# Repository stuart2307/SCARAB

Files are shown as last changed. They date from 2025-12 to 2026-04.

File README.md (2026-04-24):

# The SCARAB
The Save and Cartridge Aid Requiring Adapter Boards

# THE IDEA
As far as preservation goes, emphasis is placed on the software side of things.
Tools exist to dump ROMs, and archive them, but there are few tools to diagnose the hardware.
This is the niche the SCARAB aims to fill.

# WHAT DOES IT DO?
It tests the pins of cartridges to ensure they work correctly.
It validates the checksum of the internal ROM.
It tests the save battery, if applicable, via a Save Data Retention test.

# WHY DID YOU MAKE IT?
I've always loved retro gaming, and I am a collector of old hardware.
As such, when given the opportunity to work with it as part of my Final Year Project, I settled on the SCARAB.
I wanted to have some kind of tool to ensure my cartridges were operational.

Licensed under the GNU General Public License.

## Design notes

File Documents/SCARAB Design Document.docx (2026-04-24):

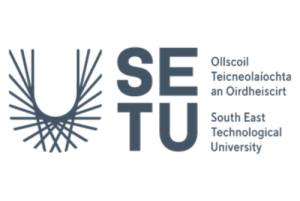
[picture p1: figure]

# SCARAB: Design Document

For submission to SETU

Author: Stuart Rossiter

Student Number: C00284845

Course: BSc (Hons.) Software Development

Supervisor: Joseph Kehoe

# 1. SCARAB Program

## 1.1 Software Architecture

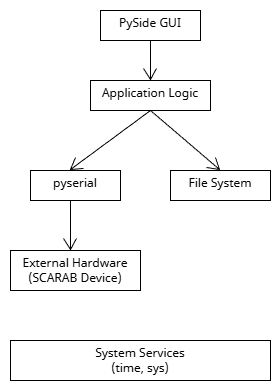
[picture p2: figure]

### 1.1.1 PySide

For GUI development, I am using Python’s own binding of the GUI toolkit Qt, developed by The Qt Company themselves. The binding, known as PySide, is cross-platform, much like Qt. The PySide binding is open source under the GPLv3 and Qt commercial license (pyside, 2021).

### 1.1.2 Python

The application logic will be handled using Python. Python, created by Guido van Rossum in 1991, is a general-purpose language with a simple syntax, similar to the English language (W3Schools, n.d.). Given its simplicity, it allows for rapid development, aided by its abundance of external libraries.

### 1.1.3 pySerial

The pySerial library encapsulates serial port access, providing cross-platform backends for Python (pyserial, 2022). This will be used to interface with the SCARAB Device.

### 1.1.4 File System

The SCARAB program will need to store backed up save files. As such, interaction with the PC’s file system is necessary.

### 1.1.5 External Hardware (SCARAB Device)

pySerial is being used to communicate with external hardware. In this case, it is communicating with the SCARAB Device itself. Specifically, it is communicating with the Arduino which powers the SCARAB.

### 1.1.6 System Services

The SCARAB PC Program will need to make use of some system libraries such as time for any necessary delays while the SCARAB Device connects, and sys for exiting.

# 2. SCARAB Device

## 2.1 Hardware Architecture

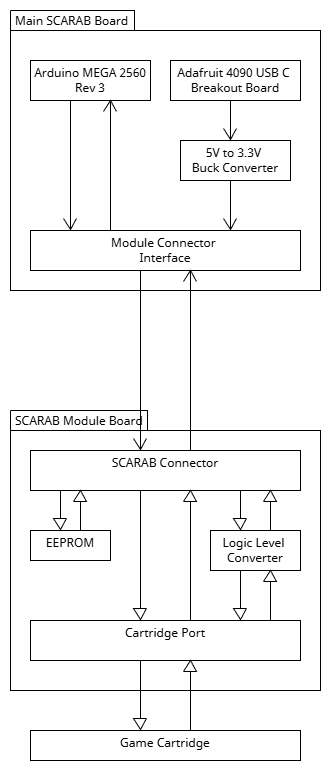
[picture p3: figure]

### 2.1.1 Arduino MEGA 2560 Rev 3

Based on the ATmega2560 microcontroller, the Arduino Mega 2560 Rev3 contains everything needed to support the ATMega2560, including 54 digital I/O pins, 16 analog inputs, 4 hardware serial ports, a 16MHz crystal oscillator, USB connection, and a power jack (Arduino, 2025). The Arduino serves as the intermediary device which translates between what the PC wants, and what the cartridge expects.

### 2.1.2 Adafruit 4090 USB C Breakout Board

The Adafruit USB C board will serve as the main power source for the cartridges and the EEPROM. While a microcontroller has enough power to interface with the cartridge, it doesn’t support the Amps necessary to also power it. Using a USB-C cable, the SCARAB could draw the power necessary from a USB port on the PC. While this will require 2 USB cables to be connected between the SCARAB and the PC, it’s preferable to the alternative of batteries.

### 2.1.3 5V to 3.3V Buck Converter

Not only do some cartridges such as the GBA or N64 use 3.3V logic, but they utilise 3.3V VCC too. The logic level converters would not work for the level of amps required, so a new solution was needed. This is where buck converters are being used. Buck converters convert a DC voltage to a lower DC voltage, such as 5V to 3.3V in this case (Yates, 2024).

### 2.1.4 Module Connector Interface / SCARAB Connector

A series of pins and pin headers, the Module Connector and SCARAB Connector serve as a link between the SCARAB Device and its various cartridge port modules.

### 2.1.5 EEPROM

The Electronically Erasable Programmable Read Only Memory (EEPROM) serves as the identification chip for the individual modules. The SCARAB will need to adjust itself based on the type of cartridge it is reading from, so the EEPROM will store the necessary data to assist in this.

### 2.1.6 Logic Level Converter

As mentioned above, some cartridges use 3.3V logic, where the Arduino MEGA 2560 uses 5V logic. These logic level converters will translate between the Arduino and the cartridge in these cases. They will not be present on every module, only the ones that require 3.3V.

### 2.1.7 Cartridge Port

The cartridge ports serve as an interface between the Arduino and the cartridges themselves. They are fit for purpose, and mimic the port contained within the respective consoles that the cartridges are designed for.

### 2.1.8 Game Cartridge

The game cartridges themselves are the main purpose of the SCARAB. They are being tested and checked for any issues, and having their save data backed up.

## 2.2 Circuit Diagrams

### 2.2.1 SCARAB Device

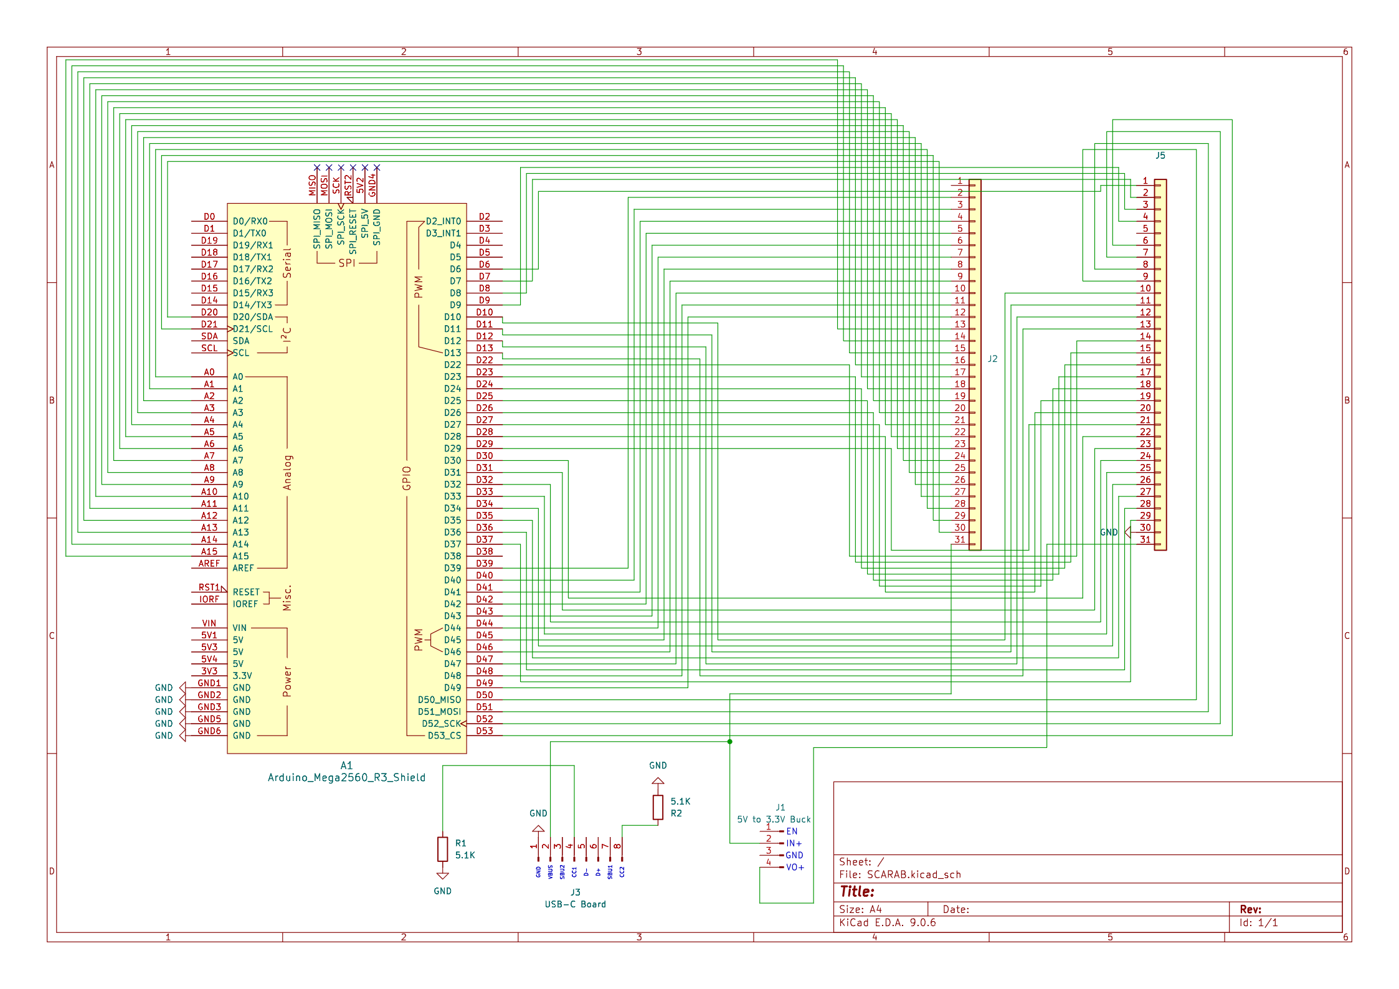
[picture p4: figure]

### 2.2.2 SNES Module

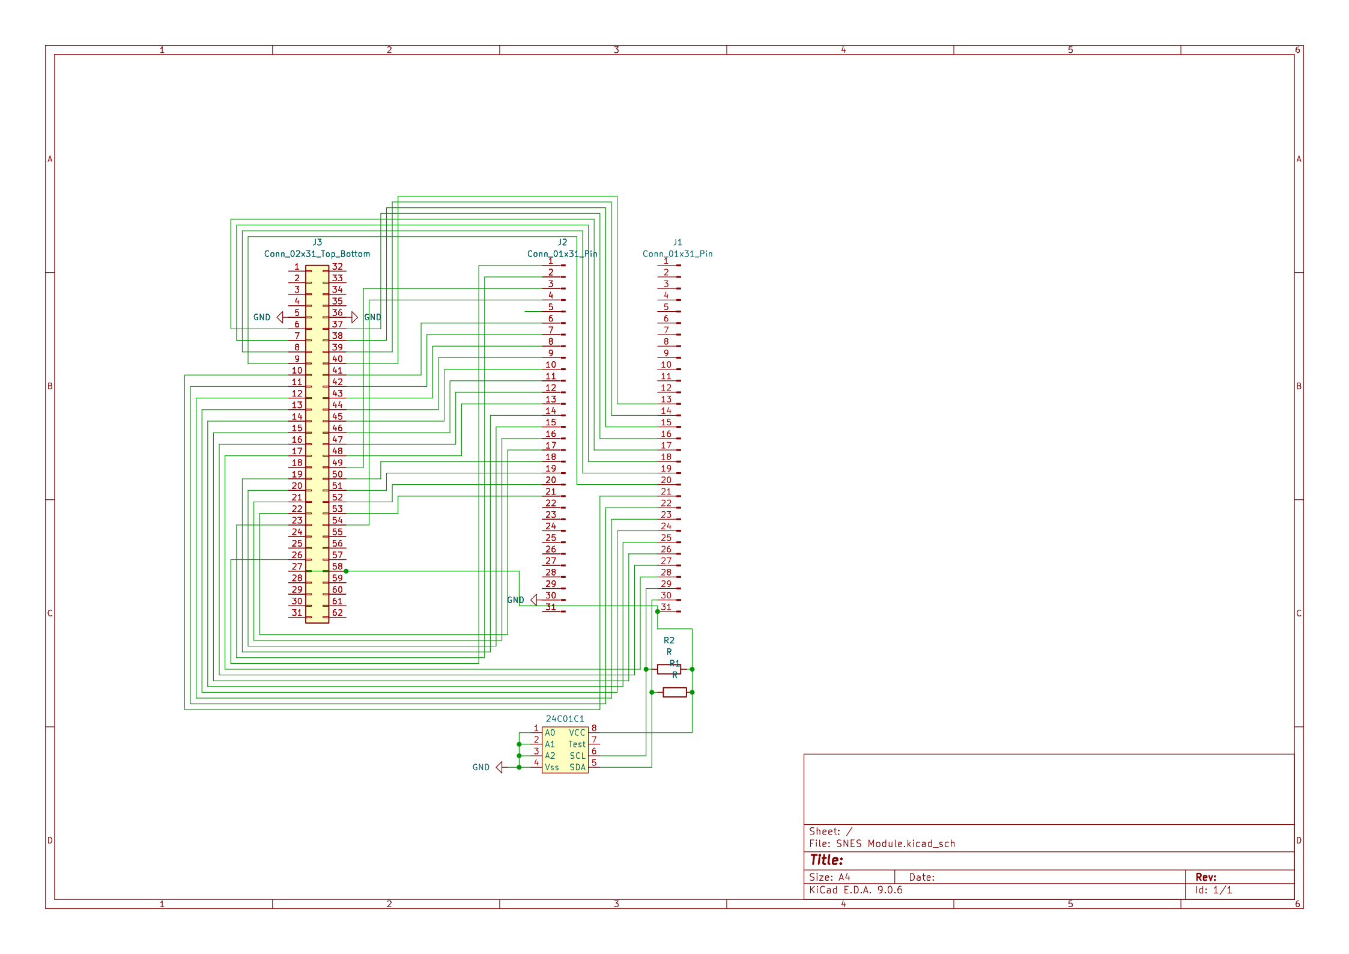
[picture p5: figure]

### 2.2.3 N64 Module

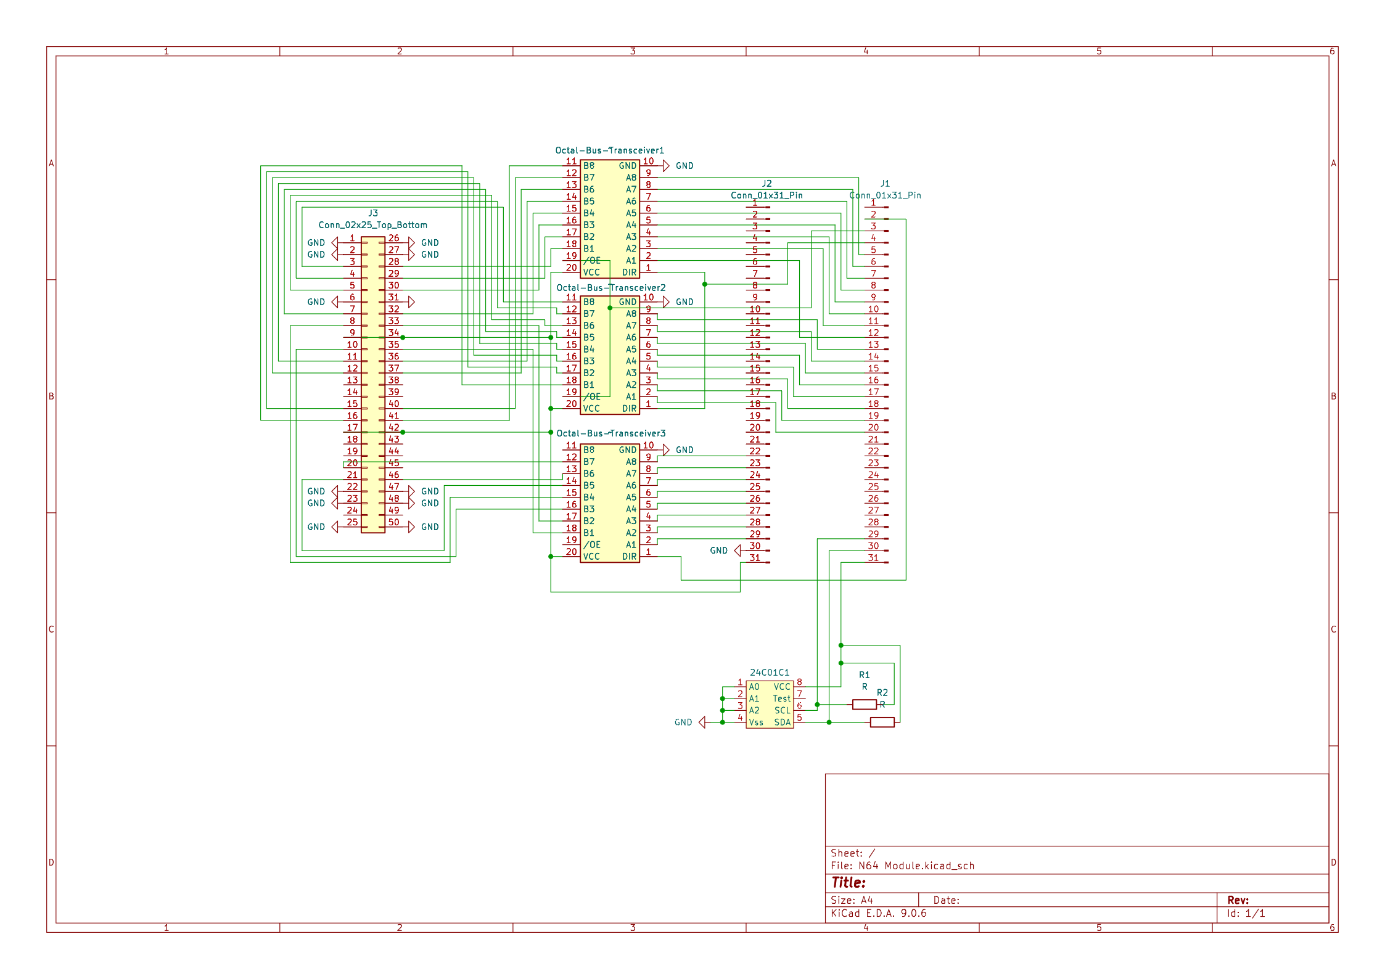
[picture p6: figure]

### 2.2.4 GBA Module

### 2.2.5 NES Module

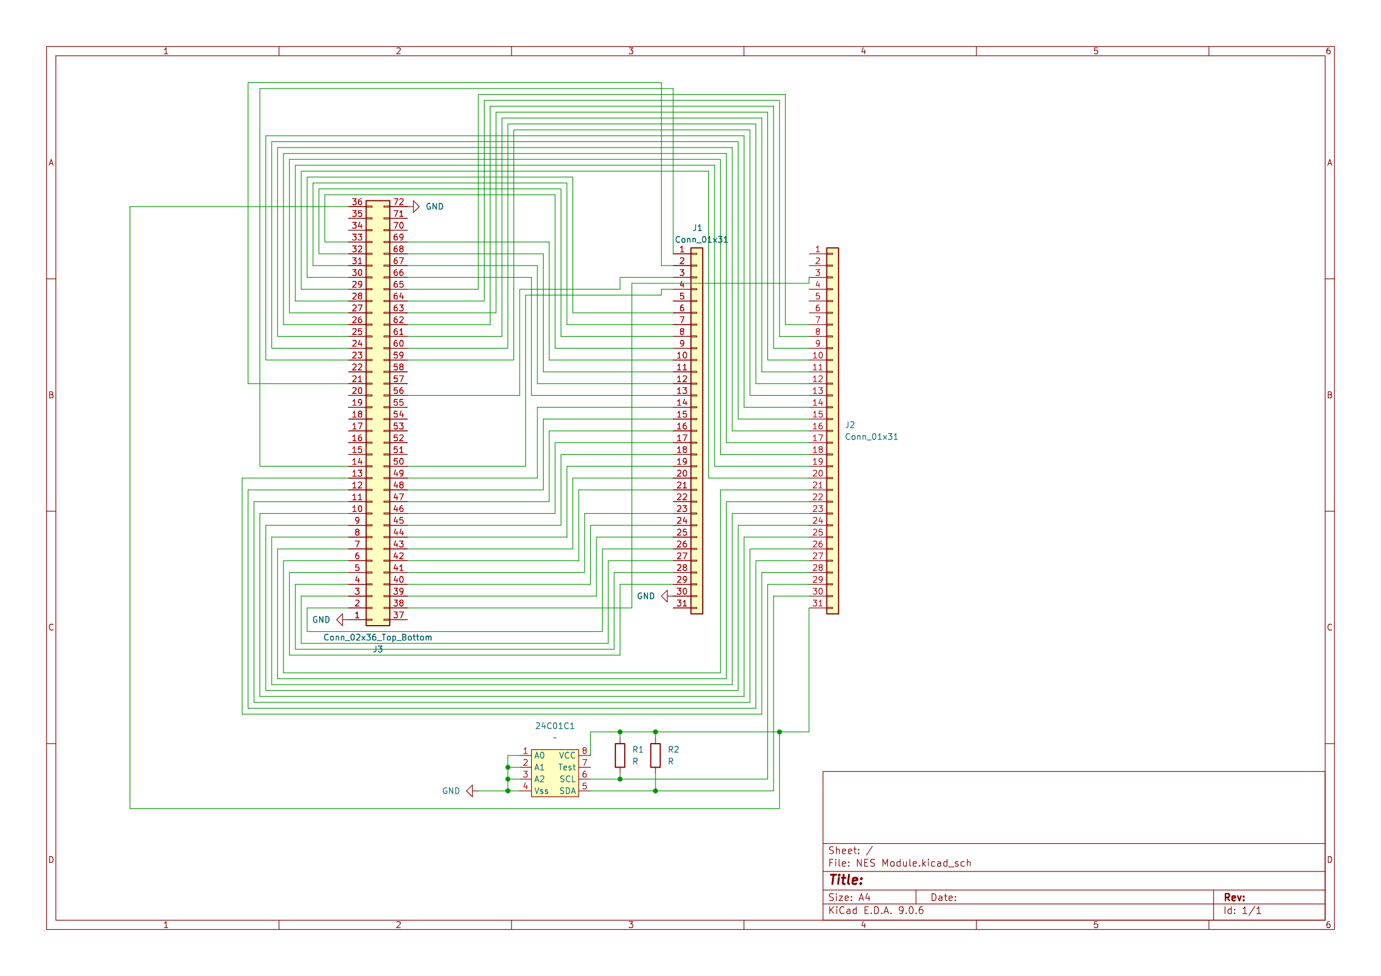
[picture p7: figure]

# 3. Algorithm Pseudocode

## 3.1 SCARAB

### 3.1.1 Identify Module

func identifyModule() {

Initialize EEPROM Connection

value = Read From EEPROM

Close EEPROM Connection

switch (value) {

case “SNES”:

globalFunctionPointers = snesFunctionPointers

case “NES”:

globalFunctionPointers = nesFunctionPointers

case “GBA”:

globalFunctionPointers = gbaFunctionPointers

case “GBC”:

globalFunctionPointers = gbcFunctionPointers

case “N64”:

globalFunctionPointers = n64FunctionPointers

}

}

## 3.2 SNES

### 3.2.1 Read Cartridge

func readSnesCartridge(address) {

Place address on address lines

Set RD line to active low

byte = Read from data lines

return byte

}

### 3.2.2 Write Cartridge

func writeSnesCartridge(address, byte) {

Place address on address lines

Place byte on data lines

Set WR line to active low

}

### 3.2.3 Dump Save

func dumpSnesSave(saveSize, romLayout) {

Create buffer[1024] to store data

switch (romLayout) {

case “LoRom”:

startLocation = LoRomSaveLocation

case “HiRom”:

startLocation = HiRomSaveLocation

case “ExHiRom”:

startLocation = ExHiRomSaveLocation

}

for address in range startLocation to startLocation + saveSize {

buffer[(address – startLocation % 1024)] = readSnesCartridge(address)

checksum for buffer XOR new byte of data

if buffer is full {

Send buffer to PC

Send checksum to PC

clear buffer

if PC returns OK then continue

else error

}

}

}

### 3.2.4 Restore Save

func restoreSnesSave(saveSize, romLayout) {

Create buffer[1024] to store data

switch (romLayout) {

case “LoRom”:

startLocation = LoRomSaveLocation

case “HiRom”:

startLocation = HiRomSaveLocation

case “ExHiRom”:

startLocation = ExHiRomSaveLocation

}

for address in range startLocation to startLocation + saveSize {

if buffer is empty { //if (address – startLocation % 1024) == 0

Request data from PC

Request Checksum from PC

Validate Checksum

if OK then ACK

else ERR

}

writeSnesCartridge(address, buffer[(address – startLocation % 1024)])

}

Send OK to PC

}

### 3.2.5 Calculate Checksum

func calcSnesChecksum(romSize) {

checksum = 0

for address in range romSize {

checksum += readSnesCartridge(address)

if checksum overflows 16 bits, checksum &= 0x00FF

}

return checksum

}

## 3.3 NES

### 3.3.1 Read Cartridge

func readNesCartridge(address, romArea) {

if romArea is “PRG” {

Place address on CPU address lines

set CPU RD to active low

byte = read from CPU data lines

}

else romArea is “CHR” {

Place address on PPU address lines

set PPU RD to active low

byte = read from PPU data lines

}

return byte

}

### 3.3.2 Write Cartridge

func writeNesCartridge(address, romArea, byte) {

if romArea is “PRG” {

Place address on CPU address lines

Place byte on CPU data lines

set CPU WR to active low

}

else romArea is “CHR” {

Place address on PPU address lines

Place byte on PPU data lines

set PPU WR to active low

}

}

### 3.3.3 Dump Save

func dumpNesSave(saveSize, mapper, saveSize) {

based on mapper, writeNesCartridge(BankControlAddress, PRG, RamEnableCode)

declare buffer[1024] to store data

for x in range saveSize {

buffer[x % 1024] = readNesCartridge(x + baseSaveAddress, PRG)

if buffer full {

send buffer to PC

calc Checksum on buffer

send Buffer to PC

clear buffer on OK

}

}

}

### 3.3.4 Restore Save

func restoreNesSave(saveSize, mapper, saveSize) {

based on mapper, writeNesCartridge(BankControlAddress, PRG, RamEnableCode)

declare buffer[1024] to store data

for x in range saveSize {

writeNesCartridge(x + baseSaveAddress, PRG, buffer[x%1024]

if buffer empty { //if (x % 1024) == 0

Request data from PC

Request Checksum from PC

Validate Checksum

if OK then ACK

else ERR

}

}

}

### 3.3.5 Calculate Checksum

## 3.4 GBA

### 3.4.1 Read Cartridge

### 3.4.2 Write Cartridge

### 3.4.3 Dump Save

### 3.4.4 Restore Save

### 3.4.5 Calculate Checksum

## 3.5 GB/GBC

### 3.5.1 Switch Bank

func switchBank(bankNumber, romType, memType) {

Determine Write address from romType

if memType is RAM, write to enable RAM mode

If bankNumber > 1F (needs more than 5 bits, never happens with RAM) {

Write to enable ROM banking mode

Write lower 5 bits

Write upper 2 bits

}

else {

Write bank to address

}

}

### 3.5.2 Read Cartridge

func readGbCartridge(address) {

Place address on address lines

Toggle READ to active low

byte = Read from data pins

return byte

}

### 3.5.3 Write Cartridge

func writeGbCartridge(address, bank, byte) {

Place address on address lines

Place byte on data lines

Toggle WRITE to active low

}

### 3.5.4 Dump Save

func dumpGbSave(ramBanks) {

Create buffer to store data

for x in range ramBanks {

//Banks are offset by 1. bank 0 is the first bank, never needs switching

if bank > 1, switchBank(x – 1, romType, RAM), change offset from 0

Write enable RAM

for y in range 8KiB + offset {

buffer.add(readGbCartridge(y)

if buffer full {

Calculate checksum on buffer

Send buffer to PC

Send checksum to PC

}

}

Write disable RAM

}

}

### 3.5.5 Restore Save

func restoreGbSave(saveSize, ramBanks) {

Create buffer[1024] to store data

Request data from PC

Request Checksum from PC

Validate Checksum

if OK then ACK

else ERR

for x in range ramBanks {

//Banks are offset by 1. bank 0 is the first bank, never needs switching

if bank > 1, switchBank(x – 1, romType, RAM), change offset from 0

Write enable RAM

for y in range 8KiB + offset {

writeGbCartridge(

if buffer empty {

Request data from PC into buffer

Request Checksum from PC

Validate Checksum

if OK then ACK

else ERR

}

}

Write disable RAM

}

Send OK to PC

}

### 3.5.6 Calculate Checksum

## 3.6 N64

### 3.6.1 Read Cartridge

func readN64Cartridge(address) {

Place upper half of address on address lines

Latch upper half of address

Place lower half of address on address lines

Latch lower half of address

Set RD line to active low

byte = Read from data lines

return byte

}

### 3.6.2 Write Cartridge

func writeN64Cartridge(address, byte) {

Place upper half of address on address lines

Latch upper half of address

Place lower half of address on address lines

Latch lower half of address

Put data on data lines

Set WR to active low

}

### 3.6.3 Dump Save

### 3.6.4 Restore Save

### 3.6.5 Calculate Checksum

# 4. User Interface

## 4.1 Main Menu

### 4.1.1 SCARAB Found

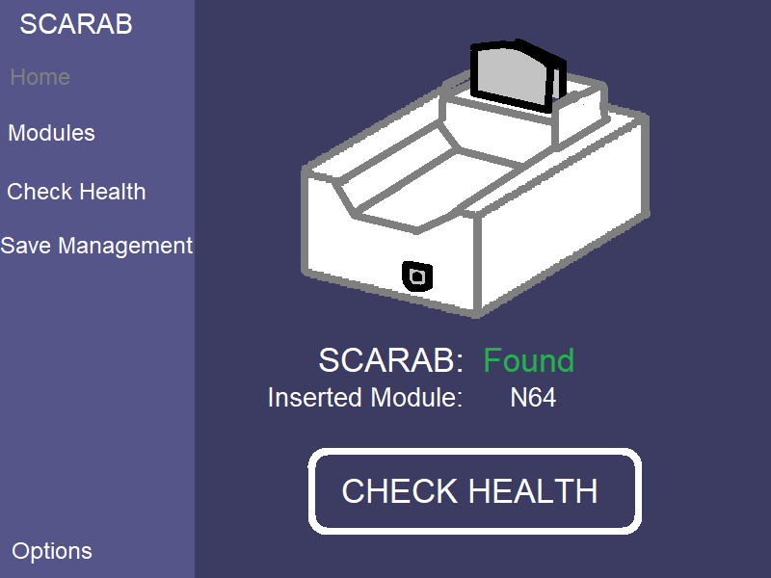
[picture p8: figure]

### 4.1.2 SCARAB Not Found

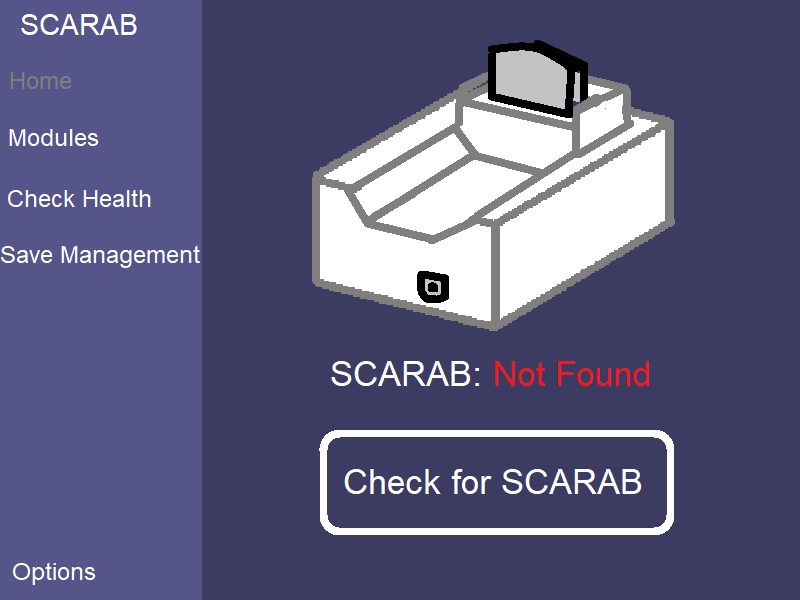
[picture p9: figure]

## 4.2 Modules

### 4.2.1 Module Inserted

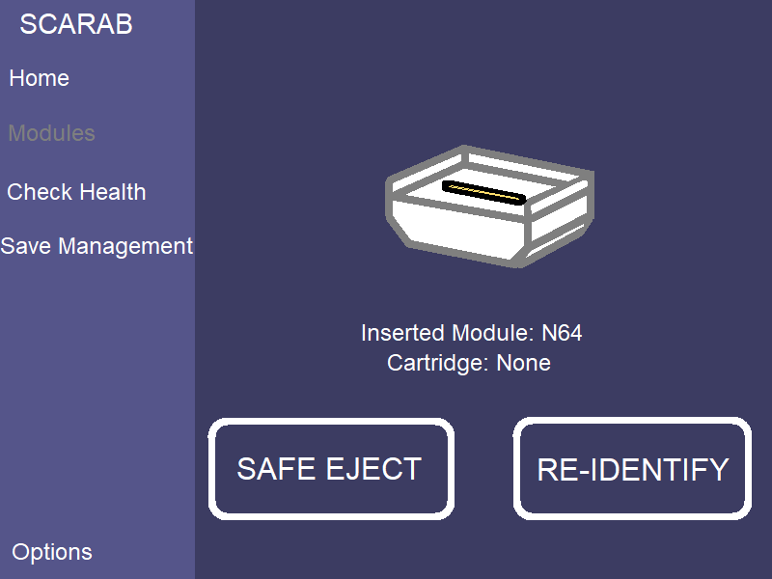
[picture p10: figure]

### 4.2.2 Module Not Inserted

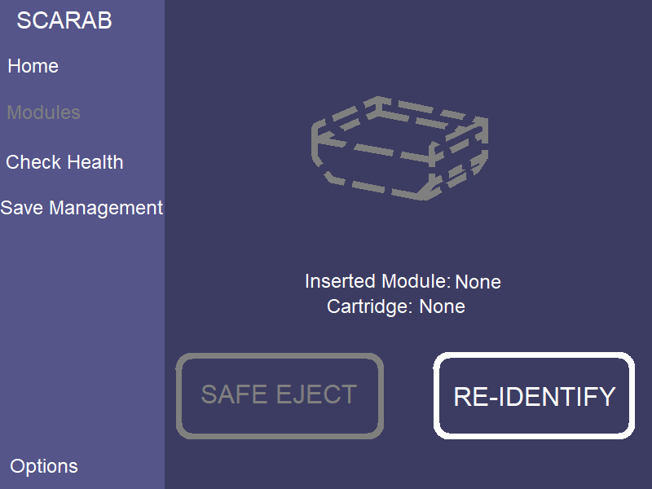
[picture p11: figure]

## 4.3 Check Health

### 4.3.1 Cartridge Inserted

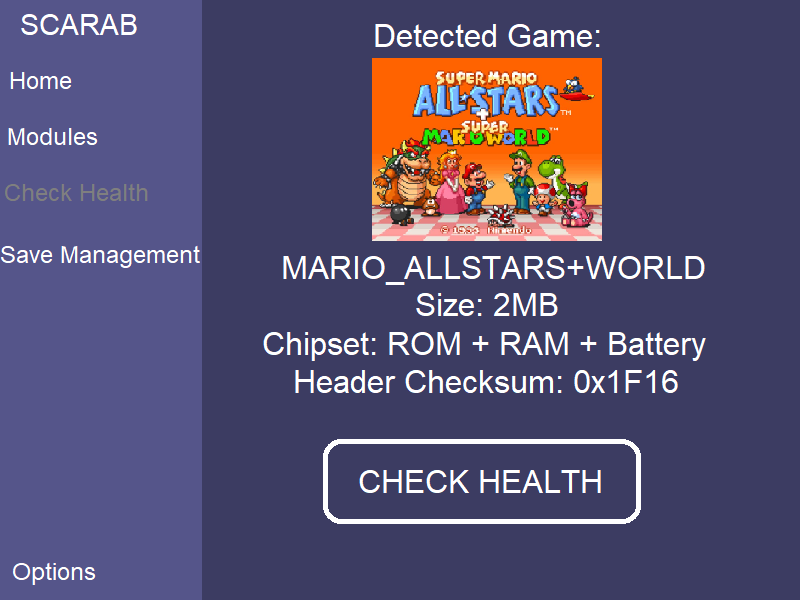
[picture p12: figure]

### 4.3.2 Cartridge Not Inserted

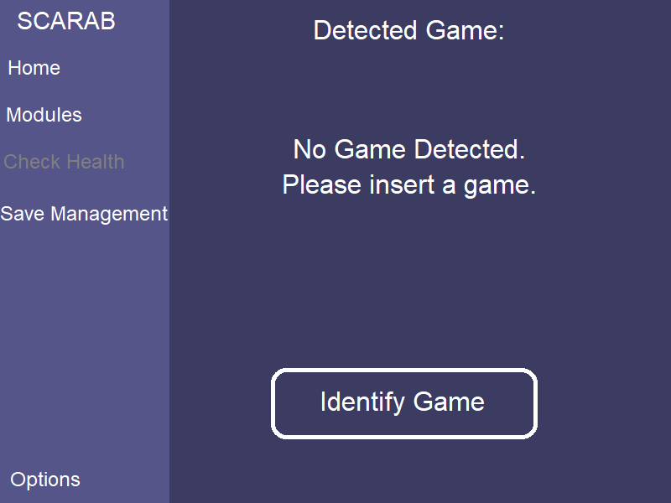
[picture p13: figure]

### 4.3.3 Health Check In Progress

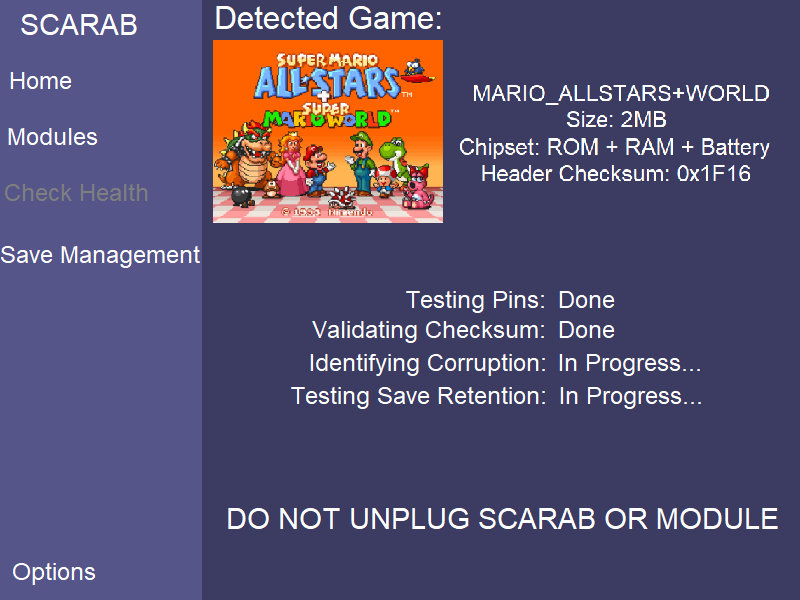
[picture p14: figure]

### 4.3.4 Health Check Done

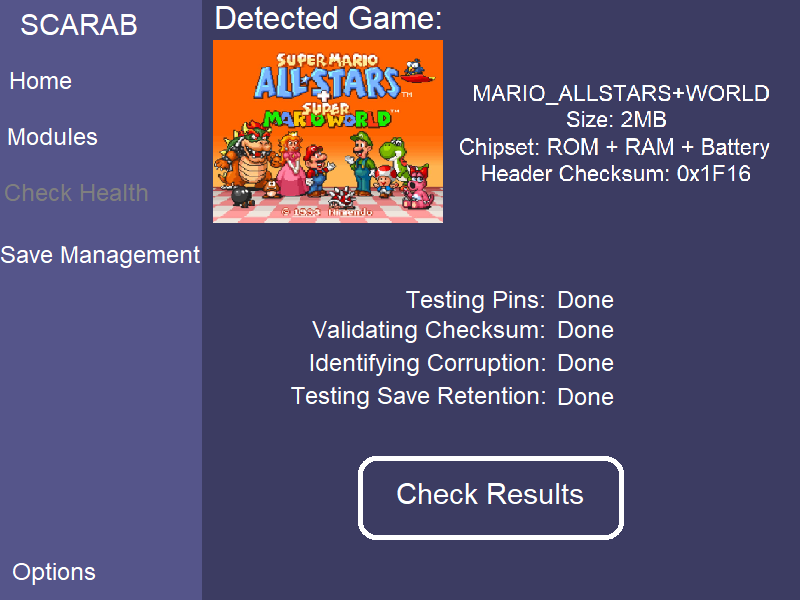
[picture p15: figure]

### 4.3.5 Health Check Results

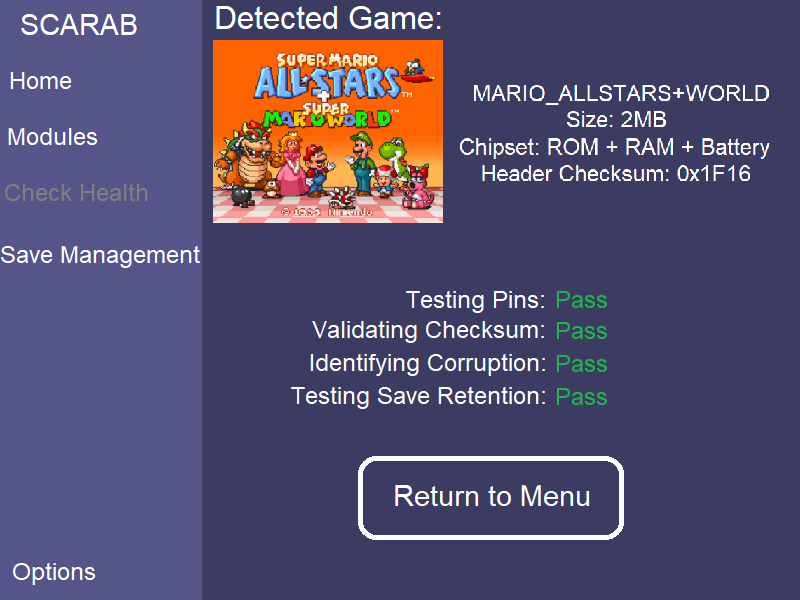
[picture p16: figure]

## 4.4 Save Management

### 4.4.1 Main Menu

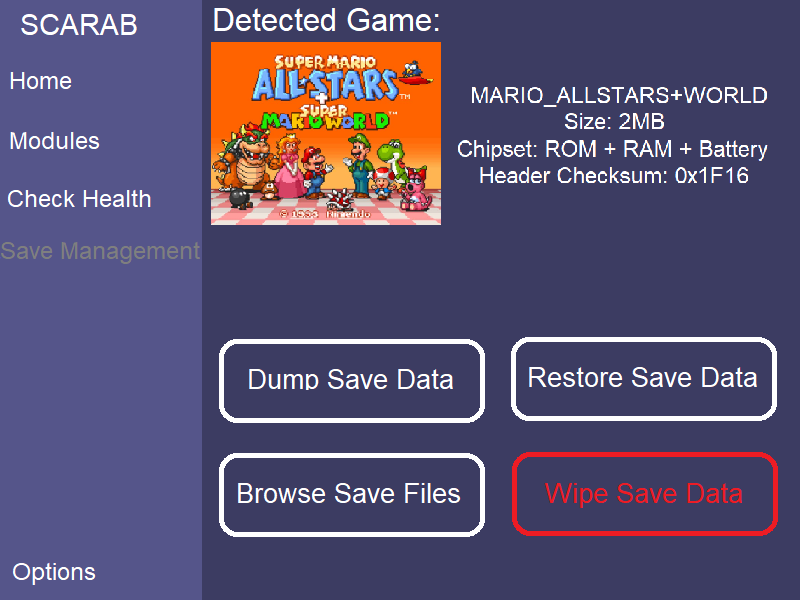
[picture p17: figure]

### 4.4.2 Main Menu No Cart

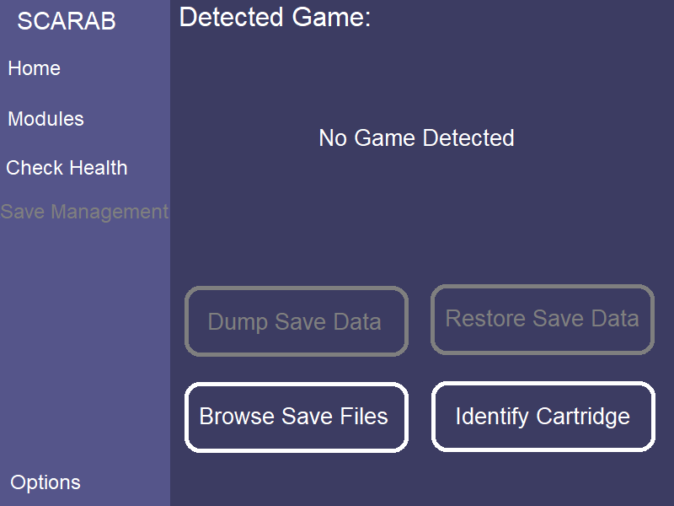
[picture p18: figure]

### 4.4.3 Dumping Save

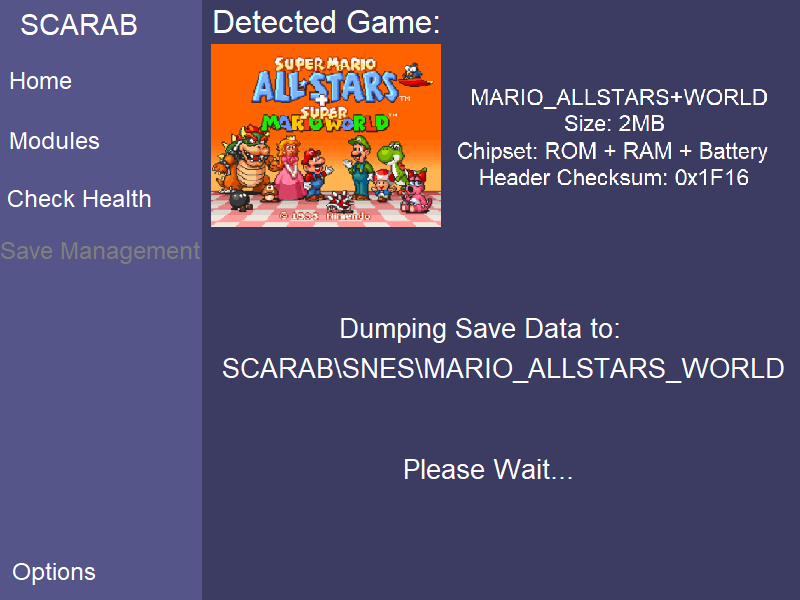
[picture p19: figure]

### 4.4.4 Save Dumped

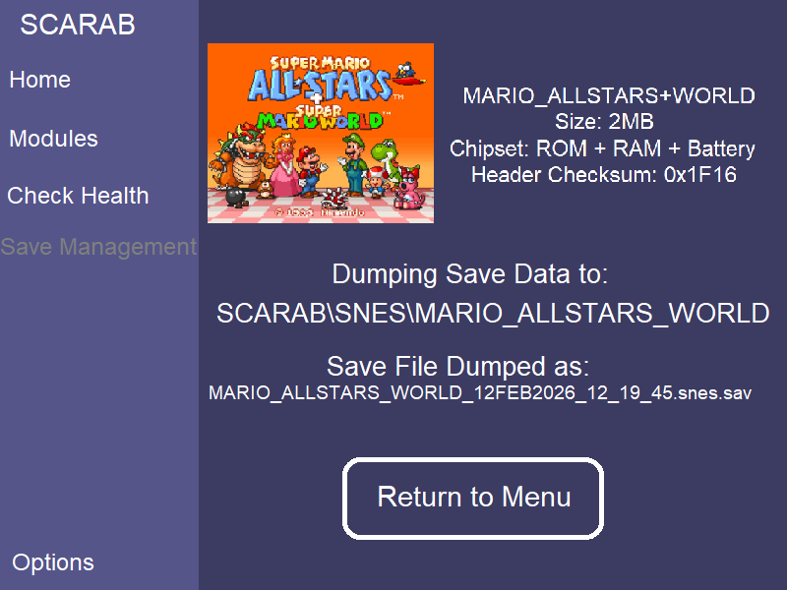
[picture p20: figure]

### 4.4.5 Restore Save

### 4.4.6 Restoring Save

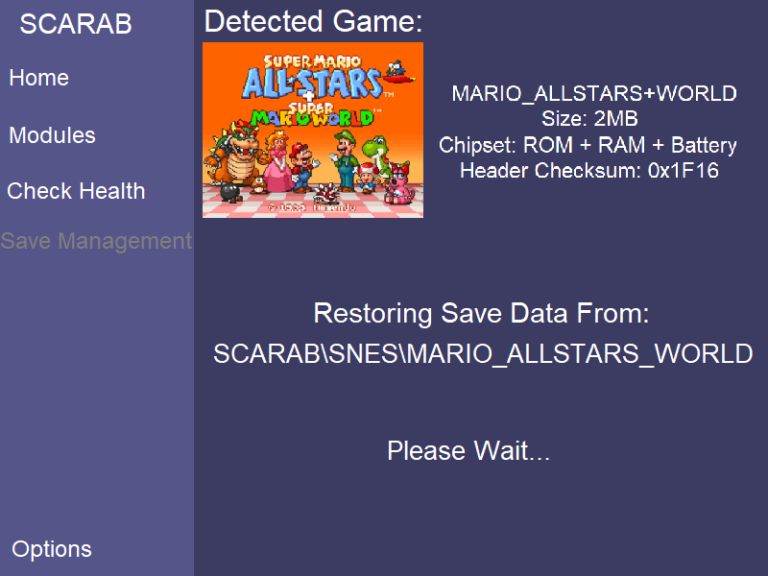
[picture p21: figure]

### 4.4.7 Save Restored

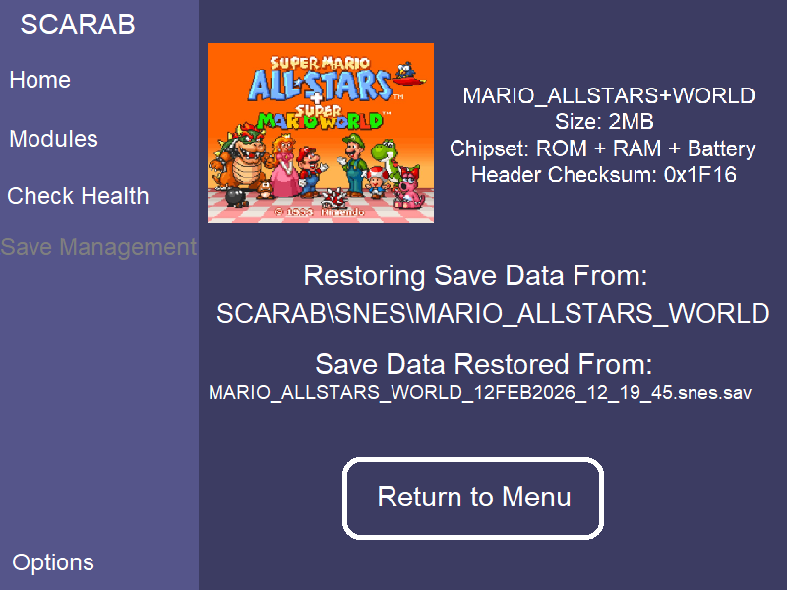
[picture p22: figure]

### 4.4.8 Browse Saves – Select Game

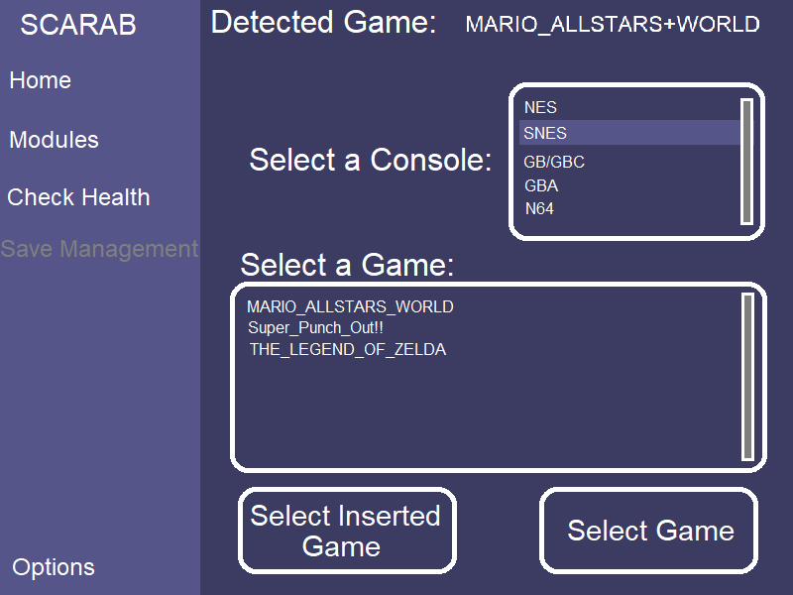
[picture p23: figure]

### 4.4.9 Browse Saves

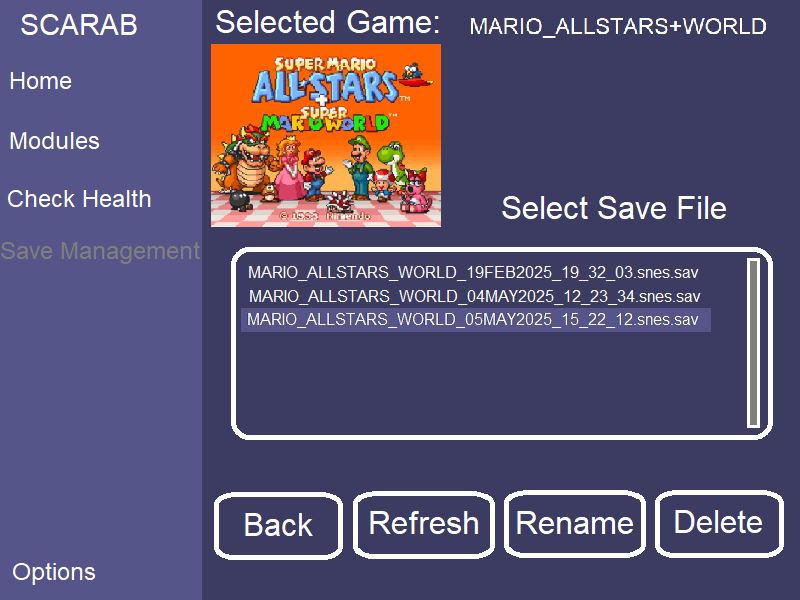
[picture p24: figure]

# 5. Bibliography

Arduino, 2025. Arduino® MEGA 2560 Rev3. [Online]
Available at: https://docs.arduino.cc/resources/datasheets/A000067-datasheet.pdf
[Accessed 10 February 2026].

pyserial, 2022. pySerial. [Online]
Available at: https://github.com/pyserial/pyserial
[Accessed 10 February 2026].

pyside, 2021. GitHub - pyside/pyside-setup: Git super project for PySide. [Online]
Available at: https://github.com/pyside/pyside-setup
[Accessed 10 February 2026].

W3Schools, n.d. Introduction to Python. [Online]
Available at: https://www.w3schools.com/python/python_intro.asp
[Accessed 9 November 2025].

W3Schools, n.d. Introduction to Python. [Online]
Available at: https://www.w3schools.com/python/python_intro.asp
[Accessed 10 February 2026].

Yates, J., 2024. Understanding Buck and Boost Converters and the Capacitors Behind Them. [Online]
Available at: https://blog.knowlescapacitors.com/blog/understanding-buck-and-boost-converters-and-the-capacitors-behind-them
[Accessed 10 February 2026].

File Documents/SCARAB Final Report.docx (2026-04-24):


# SCARAB: Final Report

For submission to SETU

Author: Stuart Rossiter

Student Number: C00284845

Course: BSc (Hons.) Software Development

Supervisor: Joseph Kehoe

# 1. Abstract

This final report covers the development cycle of the Save and Cartridge Aid Requiring Adapter Boards. Shortened to SCARAB, the project’s purpose is to aid in the preservation of retro gaming hardware, through various health checks.

Throughout this report, the challenges encountered during development will be discussed, along with the methods used to overcome them. These issues range from hardware to software, with an emphasis on the latter as this is a Software Development course.

Following the challenges, the requirements that have been achieved and those that have not been achieved will be discussed. Achievements range from the creation of an Arduino powered device to NES and SNES compatibility, while the scrapped features include the likes of Mega Drive compatibility.

In addition, the lessons learned during the creation of the SCARAB will be discussed. These tie in with the challenges, as many of the challenges provided opportunities to grow and learn as a developer.

Testing is documented next, outlining the rigorous testing which was done on the SCARAB Device and SCARAB PC Program. Many of the test cases cover alternative outcomes, such as a cartridge not having been inserted into the SCARAB.

Finally, a reflection concludes the report. This is a personal section, where my skills and growth as a developer are discussed at length. This final section shows how I have become a better developer after undertaking the SCARAB project.

# 2. Introduction

The Save and Cartridge Aid Requiring Adapter Boards (SCARAB) is a retro game cartridge health checker, designed to aid in the preservation of the hardware, over the software. The SCARAB project is split into 2 parts: the SCARAB Device, and the SCARAB PC Program.


(Fig 2.1.1 SCARAB board with inserted Arduino Mega 2560)

The SCARAB Device is responsible for interfacing directly with game cartridges and performing tests to determine their current condition. The results of these tests are returned to the user’s machine over serial, to be displayed in the PC Program.

The SCARAB PC Program provides a user interface for the device, communicating with it via serial. Core features include cartridge identification, a health checking suite, and save management capabilities.

# 3. Challenges

## 3.1 Breadboard Prototyping Issues

One of the main challenges during the development of the SCARAB, was the prototyping of modules. The rows of pins on the Cartridge Connectors were too close together to utilise a breadboard, without connecting both rows of pins to the same side of said breadboard. In addition to this, the pins were slightly too small to have a snug fit within a wire’s female end. This would result in loose connections, causing insufficient power or bad data reads/writes to cartridges. To facilitate the ease of development, only the most fundamental features of the modules would be tested on breadboards, i.e. reading a byte from and writing a byte to a cartridge. With a simple prototype confirming viability of the module, the PCB would be designed and ordered to fully develop the module, and the SCARAB’s interface with it.

## 3.2 Logic Level Translation

While the Arduino is powered at 5v and utilises the same voltage for its logic levels, not all cartridges support this level of power. NES, SNES, and GB/GBC cartridges run natively on 5v, yet the N64 and GBA cartridges run at a lower voltage: 3.3v. Translating all GPIO pins from 5v down to 3.3v would be necessary for these cartridges, which proved to be more difficult than anticipated. Attempts were made to utilise the SN74LVC245AN Octal Bus Transceivers, as it was believed that they would suffice. This was not the case, as the level shifting capabilities of these were not bi-directional. The voltage would be downgraded to 3.3v coming from the Arduino, but it would not be upscaled back to 5v when coming from the cartridge. Alternative approaches were considered, to ensure safe voltage translation and communication with low voltage cartridges.

## 3.3 NES Mapper Handling

NES cartridges use a wide variety of mapper configurations. These mappers are specialized hardware chips within the cartridges that extend the console’s capabilities. For example, they can swap in different banks of ROM/RAM data, allowing games larger than 40KB to be run on the NES. These mappers all behave differently, and as such, performing operations on the cartridges requires pre-operation mapper handling. The decision was made to stick with 6 main mappers, for the time being: NROM, UNROM, CNROM, AOROM, MMC1, and MMC3. Of the 695 licensed releases in North America, 668 are covered by these mappers (tepples, 2020), providing broad compatibility while keeping the complexity to a minimum.

## 3.4 GUI Threading with the SCARAB

When interfacing with the SCARAB device, I encountered the issue of the PC Program’s main GUI Thread becoming blocked, while the SCARAB performed its tests on the cartridge that was inserted. This was a major problem, as the app would become completely unresponsive while the tests were being run. To remedy this, different approaches to concurrency were investigated, including traditional multi-threading and asynchronous execution. In the end, a solution was devised using PySide6’s QTimer.singleShot method. This method utilises a delayed callback to a function, without blocking the main thread. To implement, the operations were split into discrete stages, progressing to the next stage via these scheduled executions.

# 4. Achievements

## 4.1 Arduino Powered Device

One of the 2 main components of the SCARAB project is the SCARAB device. A fully functional cartridge interfacing device was designed and implemented, powered by an Arduino Mega 2560. The main PCB also hosts a USB-C module for power supply, a buck converter for converting the 5V supply to 3.3V for certain modules, and pin headers for attaching module boards. The device reads from cartridges based on the inserted board, and relays the necessary information to the SCARAB PC Program.

## 4.2 GUI Based Cross-Platform Program

The other component of the SCARAB project is the SCARAB PC Program: a GUI-based application designed and developed in Python using the PySide 6 framework. The application supports user-provided cartridge imagery, displayed when the specified cartridge is inserted. Key details about the cartridge are also displayed to the user, such as Title, ROM Size, and Checksum. The SCARAB application has also been developed with modularity in mind. It allows for new modules to be added by placing their Python files in a designated Modules directory, which allows for extension without modifying the application.

## 4.3 NES/SNES Support

The SCARAB module boards allow for future expansion, and the support of various cartridge types. Currently, the SCARAB supports 2 cartridge types: the NES, and the SNES. These modules were designed and prototyped on breadboards, before being given custom PCBs to connect to the SCARAB device. The NES has support for 6 mappers, allowing for a high level of compatibility with licensed releases. The SNES supports LoRom and HiRom layouts, covering a vast majority of cartridges, save for those with the SA-1 enhancement chip.

## 4.4 Save Management

As part of the cartridge aiding functionalities of the SCARAB, the ability to dump/restore save data from cartridges was included to, for example, allow the batteries powering internal SRAM to be changed without losing one’s save file. This save management system was developed and integrated into the SCARAB PC Program, providing means to backup and archive save files for cartridge repair or otherwise.

## 4.5 Health Checking

The main purpose of the SCARAB is to allow for users to check the overall health of their retro video game cartridges. This is facilitated by the SCARAB Program’s Check Health Suite. The checking of cartridge health is split into 3 distinct categories; Cartridge Pins, ROM Data, and Save Data.

For Cartridge Pins, the functionality of the cartridge’s edge connector’s pins are verified. The SCARAB tests that all data pins are toggling on and off as intended, which consequently tests the READ and ROMSELECT pins, if applicable.

For ROM Data, the checksum of the ROM is calculated. This varies by system, as some contain a checksum within the ROM header, whereas some need to be validated externally. For example, the SNES header contains 16-bit sum of every byte of ROM data, with the overflow discarded (Nintendo, 1993).

Finally, the Save Data testing consists of the testing of the cartridge’s save retention. Any previously existing save file is dumped from the cartridge, and a predetermined save is written to it. After cutting cartridge power for ~30 seconds, the predetermined save is read back and compared to the original. The match percentage is returned to the user.

## 4.6 Modular Design

The SCARAB device supports a modular design. The cartridge connectors each have their own custom PCB, which they are attached to along with an EEPROM for identification. This modular system allows for users to pick and choose which cartridges they wish for their SCARAB device to support. In addition, this allows for future expansion, for cartridge types currently not supported by the SCARAB.

## 4.7 EEPROM Identification

Each SCARAB module accommodates an EEPROM for cartridge identification. The first page of the EEPROM stores an 8-byte identifier string, specific to each module. The SCARAB Program provides the functionality to set this identifier when performing initial setup for newly assembled modules.

# 5. Scrapped Features

## 5.1 Mega Drive Compatibility

Originally, the SCARAB was to come with a Mega Drive Adapter Board, which would allow for the analysis and archival of SEGA Mega Drive cartridges. This, however, was dropped due to time constraints. The choice was made to drop the SEGA Mega Drive over other cartridge types, as it is less popular than the Nintendo consoles planned for the SCARAB (Zackariasson & Wilson, 2012).

## 5.2 Automatic Save Retention Testing

When testing a cartridge’s save data retention, the SCARAB requests that the user unplug the power cable, to allow for RAM to lose the data written to it. The original plan was for this to be an automatic process.

Using MOSFETs, the SCARAB would control the power lines. Unfortunately, the SCARAB’s main board was very packed, leading the idea to be pushed back to a later stage. This later stage never arrived, leading to the scrapping of the MOSFET controlled power lines. With a redesign, this could potentially be accommodated.

## 5.3 3.3V Compatibility

The SCARAB was ideally to support cartridges of both 5V logic levels, and 3.3V logic levels. This did not end up happening. The 8-bit Logic Level Translators used, the SN74LVC245A Octal Bus Transceivers, were not ideal for the job. It was my understanding that the level shifting was bidirectional, but that is not the case. The use of a truly bidirectional level shifter, in the TXS1080E would serve to allow for such compatibility. By omitting the 3.3V environment from the SCARAB’s compatibility, it immediately renders the Nintendo 64 and Game Boy Advance adapter boards redundant until a redesign is done.

## 5.4 Identify Corruption

Out of the 4 tests originally planned as part of the Check Health Suite provided by the SCARAB, only 3 were completed. Identify Corruption was scrapped. The original plan was to identify any areas of ROM that were incorrect or had become corrupted. This proved to be far more difficult than thought. Without a fully intact version of the ROM on the inserted cartridge, there would be no way to know exactly which bytes were invalid. Alternatives were explored, such as adding a feature for users to supply their own ROM files. This too was abandoned, as I felt it condoned piracy, which is a moral grey area.

# 6. Lessons Learned

Throughout the development of the SCARAB, I have learned many things.

## 6.1 Hardware Prototyping Limitations

Throughout the development of the SCARAB device, it became clear that there were limitations to what could be achieved via breadboard prototyping. Loose wires, cheap breadboards, and multiple connections between components create additional potential points of failure. As a result, I have learned that the ideal approach is to create a prototype of the most basic features on a breadboard, and to develop fully on a designed PCB.

## 6.2 “Measure Twice, Cut Once”

Upon receiving the PCBs I had designed, it had come to my attention that the spacing between the pins on the GB/GBC/GBA modules were incorrect. The pin distance for these devices is 1.5mm, yet I had mistakenly set them to the pre-existing distance of 1.27mm. With no time to reprint, the module had to be abandoned. This taught me the incredibly important lesson of double and triple checking all my work.

## 6.3 Importance of Concurrency in GUI Programs

When running the tests on the inserted cartridges, I noticed that the SCARAB PC program became unresponsive. Concerned, I investigated and found that it was a quirk of the main GUI thread of PySide6 being occupied by the testing. I learned many ways to remedy this, such as external multithreading, or Qt Event Loop functions within PySide6. My chosen method was the QTimer.singleShot function which allows for delayed callbacks. This was a vital change, as letting a GUI go unresponsive results in a poor user experience.

## 6.4 Benefits of Modular Design

A key feature of the SCARAB is its modular design. It allows for future expansion, allowing users to create and implement their own SCARAB modules with ease. This also helped me in my development, as it led to a fully functional GUI early on, where I could simply drop in new modules to test.

## 6.5 Ethical and Legal Implications of Software

When deliberating the feasibility of the Identify Corruption test, the idea of users supplying their own valid ROMs was brought up. This raised an ethical dilemma about whether this was encouraging piracy. This also crosses over into the legality of such an option.

# 7. Testing

The SCARAB project was tested rigorously, as outlined below. Prior to all these tests, the following preconditions were verified and assumed to be handled correctly throughout all subsequent tests.

## 7.1 Precondition Test Cases

### 7.1.1 Detect SCARAB

Actors: PC, Cartridge Port
Pre-conditions: | The PC is running the SCARAB GUI program.
Main Success Scenario: | 1. The user plugs the SCARAB into the PC using the USB cables. 2. The user clicks “Re-Identify SCARAB” 3. The program begins its attempt of identifying the SCARAB.
Expected Result: | The SCARAB PC Program has identified the SCARAB.
Actual Result: | The SCARAB was indeed correctly identified, and reflected in the GUI Program.
Result: | PASS
Comments:

Alternate Scenario
Scenario | The SCARAB was not plugged in to the PC.
Expected Result: | The SCARAB PC Program displays an error message to the user.
Actual Result: | The user receives an error message as expected, notifying them that the SCARAB was not found.
Result: | PASS

Alternate Scenario
Scenario | An Arduino Mega 2560 is connected, but without the SCARAB code on it.
Expected Result: | The SCARAB PC Program displays an error message to the user.
Actual Result: | The user receives an error message as expected, notifying them that the SCARAB was not found.
Result: | PASS

### 7.1.2 Identify Module

Actors: PC, Cartridge Port
Pre-conditions: | The PC is running the SCARAB GUI program. The SCARAB has been plugged in and identified.
Main Success Scenario: | 1. The user plugs a module into the SCARAB’s module connector. 2. The user clicks “Modules” on the sidebar of the GUI program, moving to the “Modules” menu. 3. The user clicks “Identify Module”. 4. The SCARAB attempts to identify the inserted module.
Expected Result: | The SCARAB has identified the module.
Actual Result: | The SCARAB module was correctly identified, and this was reflected accordingly in the program.
Result: | PASS
Comments:

Alternate Scenario
Scenario | No module has been inserted into the SCARAB.
Expected Result: | The SCARAB PC Program displays an appropriate error message to the user.
Actual Result: | The user received an error message as expected, notifying them that no module has been inserted.
Result: | PASS

Alternate Scenario
Scenario | The inserted module has not had its EEPROM configured.
Expected Result: | The SCARAB PC Program displays an appropriate error message to the user.
Actual Result: | The user received an error message as expected, notifying them that no module has been inserted.
Result: | PASS

### 7.1.3 Identify Cartridge

Actors: PC, Cartridge Port
Pre-conditions: | The SCARAB is plugged into the PC. The inserted module has been identified.
Main Success Scenario: | 1. A cartridge is inserted into the SCARAB’s module. 2. The user clicks “Modules” on the sidebar of the GUI program, moving to the “Modules” menu. 3. The user clicks “Identify Cartridge”. 4. The SCARAB attempts to identify the inserted cartridge.
Expected Result: | The cartridge is successfully identified and reflected in the GUI program.
Actual Result: | The cartridge was successfully identified, with details about it being reflected to the user.
Result: | PASS
Comments:

Alternate Scenario
Scenario | No cartridge is inserted.
Expected Result: | The SCARAB PC Program displays an appropriate error message to the user.
Actual Result: | The user received an error message as expected, notifying them that there is no cartridge present.
Result: | PASS

## 7.2 Detailed Test Cases

### 7.2.1 Dump Save

Actors: User, SCARAB Device
Pre-conditions: | The SCARAB is connected to a PC with both USB cables. The PC is running the SCARAB GUI program. A cartridge port module is inserted into the SCARAB. A cartridge is inserted into the SCARAB’s cartridge port. A 100% save file has been restored to the cartridge in question.
Main Success Scenario: | 1. The user selects the “Save Management” option from the GUI’s sidebar 2. The program takes the user to the “Save Management” screen. 3. The user selects “Dump Save Data” from the main window. 4. The program begins dumping the save data of the inserted cartridge.
Expected Result: | The SCARAB has successfully dumped the save file of the inserted cartridge to a new file on the PC.
Actual Result: | A .sav file was successfully created, and the validity was verified against the pre-restored save file.
Result: | PASS
Comments:

Alternate Scenario
Scenario | The inserted cartridge does not support save data.
Expected Result: | The user is notified that the cartridge does not support save data, and the program does not attempt to dump the save.
Actual Result: | The user received an error message as expected, notifying them that save data is not supported.
Result: | PASS

### 7.2.2 Restore Save

Actors: User, SCARAB Device
Pre-conditions: | The SCARAB is connected to a PC with both USB cables. The PC is running the SCARAB GUI program. A cartridge port module is inserted into the SCARAB. A cartridge is inserted into the SCARAB’s cartridge port.
Main Success Scenario: | 1. The user selects the “Save Management” option from the GUI’s sidebar 2. The program takes the user to the “Save Management” screen. 3. The user selects “Restore Save Data” from the main window. 4. The program prompts the user to select a save file, displaying the dumped saves compatible with the inserted cartridge. 5. The user selects the predetermined “100% completion” save file, and clicks “Restore Save” 6. The SCARAB begins restoring the save file to the cartridge.
Expected Result: | The SCARAB successfully restores the save data to the cartridge.
Actual Result: | The save data was confirmed to have been written, after having been checked in-game.
Result: | PASS
Comments:

Alternate Scenario
Scenario | The inserted cartridge does not support save data.
Expected Result: | The user is notified that the cartridge does not support save data, and the program does not attempt to restore the save.
Actual Result: | The user received an error message as expected, notifying them that save data is not supported.
Result: | PASS

### 7.2.3 Check Health

Actors: User, SCARAB Device
Pre-conditions: | The SCARAB is connected to a PC with both USB cables. The PC is running the SCARAB GUI program. A cartridge port module is inserted into the SCARAB. A cartridge is inserted into the SCARAB’s cartridge port.
Main Success Scenario: | 1. The user selects the “Check Health” option from the GUI’s sidebar. 2. The program takes the user to the “Health Management” screen. 3. The user clicks “Check Health”. 4. The program brings the user to the testing screen, where it warns the user not to remove the cartridge during testing, while providing progress updates. 5. The SCARAB performs the test(s) on the cartridge.
Expected Result: | The tests are run by the SCARAB, and the results are displayed.
Actual Result: | The tests were successfully run by the SCARAB, and the results were displayed within the GUI Program.
Result: | PASS
Comments:

### 7.2.4 Identify Corruption

Actors: User, SCARAB Device
Pre-conditions: | The SCARAB is connected to a PC with both USB cables. The PC is running the SCARAB GUI program. A cartridge port module is inserted into the SCARAB. A cartridge is inserted into the SCARAB’s cartridge port.
Main Success Scenario: | 1. The user selects the “Check Health” option from the GUI’s sidebar. 2. The program takes the user to the “Health Management” screen. 3. The user selects “Custom Scan” 4. The user ticks the box for Identify Corruption. 5. The user clicks “Run Test(s)”. 6. The program brings the user to the testing screen, where it warns the user not to remove the cartridge during testing, while providing progress updates. 7. The SCARAB checks the ROM and save data for any corruption.
Expected Result: | The SCARAB displays the results of the Identify Corruption test to the user.
Actual Result: | The Identify Corruption test never ran, as it always defaults to “Not Selected.”
Result: | FAIL
Comments: | Feature was scrapped due to difficulties and ethical concerns.

### 7.2.5 Verify Checksum

Actors: User, SCARAB Device
Pre-conditions: | The SCARAB is connected to a PC with both USB cables. The PC is running the SCARAB GUI program. A cartridge port module is inserted into the SCARAB. A cartridge is inserted into the SCARAB’s cartridge port.
Main Success Scenario: | 1. The user selects the “Check Health” option from the GUI’s sidebar. 2. The program takes the user to the “Health Management” screen. 3. The user selects “Custom Scan” 4. The user ticks the box for Verify Checksum. 5. The user clicks “Run Test(s)”. 6. The program brings the user to the testing screen, where it warns the user not to remove the cartridge during testing, while providing progress updates. 7. The SCARAB calculates the checksum of the cartridges rom, and checks it against a known valid checksum.
Expected Result: | The result of the Verify Checksum test is returned to the user. Known functioning cartridges should pass.
Actual Result: | The SCARAB Program successfully relayed the test results back to the user through the GUI. The known working cartridge passed.
Result: | PASS
Comments:

### 7.2.6 Test Pins

Actors: User, SCARAB Device
Pre-conditions: | The SCARAB is connected to a PC with both USB cables. The PC is running the SCARAB GUI program. A cartridge port module is inserted into the SCARAB. A cartridge is inserted into the SCARAB’s cartridge port.
Main Success Scenario: | 1. The user selects the “Check Health” option from the GUI’s sidebar. 2. The program takes the user to the “Health Management” screen. 3. The user selects “Custom Scan” 4. The user ticks the box for Test Pins. 5. The user clicks “Run Test(s)”. 6. The program brings the user to the testing screen, where it warns the user not to remove the cartridge during testing, while providing progress updates. 7. The SCARAB reads tests the toggling of data pins using the header or other known ROM data.
Expected Result: | The results of the test are displayed to the user. Known functioning cartridges should pass.
Actual Result: | The results of the test were relayed back to the user through the GUI. A known working cartridge passed.
Result: | PASS
Comments:

### 7.2.7 Test Save Retention

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

Main Success Scenario:

1. The user selects the “Check Health” option from the GUI’s sidebar.
2. The program takes the user to the “Health Management” screen.
3. The user selects “Custom Scan”
4. The user ticks the box for Test Save Retention.
5. The user clicks “Run Test(s)”.
6. The program brings the user to the testing screen, where it warns the user not to remove the cartridge during testing, while providing progress updates.
7. The SCARAB backs up the user’s save and writes a pre-determined save file to the cartridge.
8. The user, as prompted, removes the USB-C Power Cable from the SCARAB.
9. After 30 seconds, the user reinserts the power cable, as prompted.
10. The save file is dumped and compared to the pre-determined one.
11. The backup save file is rewritten to the cartridge.

Expected Result: | The results are a >99% match.
Actual Result: | The save files were a >99% match, confirming an operational save battery.
Result: | PASS
Comments:

Alternate Scenario
Scenario | User does not unplug the USB-C Power Cable.
Expected Result: | The results were skewed, as a near 100% match.
Actual Result: | The results are a 99.99% match
Result: | PASS

Alternate Scenario
Scenario | The user does not plug the USB-C Power cable back in.
Expected Result: | The results are skewed, as a near 0% match
Actual Result: | The results were a 0% match.
Result: | PASS

Alternate Scenario
Scenario | The inserted cartridge does not support save data.
Expected Result: | The user is notified that the cartridge does not support save data, and the test is listed as “Not Selected”.
Actual Result: | The test was listed as “Not Selected”.
Result: | FAIL
Comments: | User is not notified about lack of save data support.

### 7.2.8 Set Pins

Actors: None
Pre-conditions: | The SCARAB is powered. The SCARAB has received a request
Main Success Scenario: | 1. The SCARAB checks the correct pin layout for the inserted port module. 2. The SCARAB sets the appropriate pins to input or output.
Expected Result: | The correct ports are set to input and output.
Actual Result: | The correct ports were set on the SCARAB.
Result: | PASS

### 7.2.9 Read Data

Actors: PC, Cartridge Port
Pre-conditions: | The SCARAB is plugged into the PC. The SCARAB has received a read request from the PC.
Main Success Scenario: | 1. The SCARAB receives the address to read from, and the size of the read. 2. The SCARAB reads the data from the cartridge into a buffer.
Expected Result: | The SCARAB reads data from the given address and returns it to the PC over serial.
Actual Result: | The SCARAB read the data and returned it, which was validated against a known valid ROM.
Result: | PASS

### 7.2.10 Write Data

Actors: PC, Cartridge Port
Pre-conditions: | The SCARAB is plugged into the PC. The SCARAB has received a write request from the PC.
Main Success Scenario: | 1. The SCARAB receives the request data. 2. The SCARAB loads the writable data into a buffer. 3. The SCARAB writes the data to the cartridge, beginning at the specified address.
Expected Result: | The SCARAB successfully writes the necessary data to the cartridge.
Actual Result: | The SCARAB wrote the data to the cartridge, tested by writing to the save data and checking in-game
Result: | PASS

# 8. Reflection

During my development of the SCARAB, I learned a lot about the development cycle of software, and the intricacies of embedded systems. While some decisions I stand by, there are some things that I would change were I to do this project all over again.

First and foremost, I would swap out the Arduino Mega 2560 Rev 3 for the Arduino Mega PRO. The PRO supports being powered at 3.3v, which negates the need for logic level translators altogether. This is seen in the likes of the Open-Source Cart Reader by Sanni (sanni, 2025).

In addition, I would reduce the number of USBs used from 2 to 1. Currently, the Arduino gets powered by its serial cable, with it also serving as the Serial Communications cable. The cartridges get powered by an external USB-C Breakout board. Ideally, I would develop a communications protocol and utilise the USB-C port for both power and data transfer.

The SCARAB introduced challenges previously unknown to me, such as the ethical concerns of encouraging piracy. This taught me to think about more than just the feasibility of coding a feature, when it came to deliberating whether it should be included.

To conclude, the most meaningful takeaway from the SCARAB project was what it revealed about what I value as a developer. I learned to love coding more than I had ever believed, when working on something I was truly interested in, that being retro gaming and hardware. Through the earlier years of the Software Development course, heavy amounts of web development were involved, which I did not find as interesting as one would hope. The SCARAB, however, has reignited my passion for development, and has outlined for me the type of work I would like to do going forward.

# 9. Glossary

SCARAB – Save and Cartridge Aid Requiring Adapter Boards

SNES – Super Nintendo Entertainment System

NES – Nintendo Entertainment System

ROM – Read Only Memory

EEPROM – Electronically Erasable Programmable Read Only Memory

USB – Universal Serial Bus

# 10. Bibliography

Nintendo, 1993. SNES Development Manual. s.l.:Nintendo of America.

sanni, 2025. OSCR: What to Order. [Online]
Available at: https://github.com/sanni/cartreader/wiki/What-to-order
[Accessed 20 April 2026].

tepples, 2020. Most common mappers. [Online]
Available at: https://forums.nesdev.org/viewtopic.php?t=20019
[Accessed 20 April 2026].

Zackariasson, P. & Wilson, T. L., 2012. The Video Game Industry: Formation, Present State, and Future. 1st ed. New York: Routledge.

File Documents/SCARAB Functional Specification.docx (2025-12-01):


# SCARAB: Functional Specification

For submission to SETU

Author: Stuart Rossiter

Student Number: C00284845

Course: BSc (Hons.) Software Development

Supervisor: Joseph Kehoe

# 1. Introduction

The SCARAB (Save and Cartridge Aid Requiring Adapter Boards) is a diagnostic tool designed to check the overall health of retro game cartridges, and manage their saves through a GUI based PC program. Designed for the purpose of retro game preservation, the SCARAB will use an Arduino MEGA 2560 to interface with the cartridges, through cartridge port modules. These modules will be able to be swapped in and out, allowing for a wide variety of cartridge types, and future expansion.

## 1.1 Target Users

The SCARAB will be designed for retro gaming enthusiasts and preservationists. Retro gaming enthusiasts would want to ensure that their video games remain playable, and would be interested in backing up their save games in case something does go wrong. Preservationists keep all sorts of cartridges in working order, preserving the hardware with the software, so they would make use of the SCARAB’s diagnostic capabilities.

## 1.2 Technologies

To serve as an interface between the cartridge port modules and the PC, a microcontroller will be required, in this case an Arduino. Due to the number of pins required for cartridge ports such as the Game Boy Advance, or the Nintendo 64, an Arduino MEGA 2560 would be ideal, due to the sheer number of digital I/O pins on the board. Alternate boards would be usable, but would require latches or multiplexing. For the GUI based PC program, Python would be sufficient, as it can interface with the Arduino directly over serial, and the Tkinter library provides GUI functionality. Various electronic components will also be required, listed below:

- 2x 8-bit transceivers, for 5v to 3.3v logic conversion.
- USB-C port. The Arduino has a max mA output, so a separate USB will be used to power the cartridges.
- Cartridge ports, to interface with the cartridges.
- Printed PCBs, for the SCARAB and its modules.

# 2. Functional Requirements

The functional requirements for the SCARAB are separated into 2 groups: Core and Non-Core.

## 2.1 Core Requirements

- Users should be able to run diagnostic tests on inserted cartridges.
- Users should be able to dump the save data from their cartridges.
- Save Data should be able to be flashed back to the cartridges.
- Users should be able to view and manage their various save files from the GUI program.
- Cartridge ports should be able to be removed, and swapped out with other cartridge port modules.

## 2.2 Non-Core Requirements

- Users should be able to view and edit their save files with a hex editor within the GUI program.
- Users can insert more than one cartridge module to the SCARAB at the same time.
- Users will be able to use 2 probes contained in the side of the SCARAB to check battery levels directly, with results displayed in the GUI PC program.

# 3. Context Diagram and Use Cases

## 3.1 Context Diagram


## 3.2 Use Case Diagrams

### 3.2.1 PC Program


### 3.2.2 SCARAB Device Use Case Diagram


## 3.3 Brief Use Cases

### 3.3.1 Dump Save

Actors: User, SCARAB Device

Description: This use case begins when the user wishes to dump the save file from the inserted cartridge. The user selects “Save Manager” from the sidebar. From there, the user selects the “Dump Save Data” option. The use case ends when the save data has been dumped from the cartridge.

### 3.3.2 Restore Save

Actors: User, SCARAB Device

Description: This use case begins when the user wishes to restore a dumped save to the inserted cartridge. The user selects “Save Manager” from the sidebar. From there, they select the desired save, and press “Restore Save Data”. The use case ends when the save data has been restored to the cartridge.

### 3.3.3 Check Health

Actors: User, SCARAB Device

Description: This use case begins when the user wishes to check the health of the inserted cartridge. The user selects “Health Check” from the sidebar. The user then selects the tests they wish to run, and clicks “Run Test(s)”. This use case ends when the results of the tests are returned to the user.

### 3.3.4 Identify Corruption

Actors: User, SCARAB Device

Description: This use case begins when the user wishes to identify any corrupted data within a cartridge/memory card. The user selects “Health Check” from the sidebar. The user then selects “Identify Corrupted Blocks”, and clicks “Run Test(s)”. This use case ends when the result of the test is returned to the user.

### 3.3.5 Verify Checksum

Actors: User, SCARAB Device

Description: This use case begins when the user wishes to verify the checksum of a cartridge ROM against a known dump. The user selects “Health Check” from the sidebar. The user then selects “Verify Checksum”, and clicks “Run Test(s)”. This use case ends when the result of the test is returned to the user.

### 3.3.6 Test Pins

Actors: User, SCARAB Device

Description: This use case begins when the user wishes to verify the checksum of a cartridge ROM against a known dump. The user selects “Health Check” from the sidebar. The user then selects “Verify Checksum”, and clicks “Run Test(s)”. This use case ends when the result of the test is returned to the user.

### 3.3.7 Test Save Retention

Actors: User, SCARAB Device

Description: This use case begins when the user wishes to test the save retention of the inserted cartridge. The user selects “Health Check” from the sidebar. The user then selects “Test Save Retention”, and clicks “Run Test(s)”. This use case ends when the result of the test is returned to the user.

### 3.3.8 Determine Port

Actors: Cartridge Port

Description: This use case begins when a new cartridge port is inserted. The SCARAB probes the inserted board to determine what cartridge port the board holds. This use case ends when the Arduino has determined the port type.

### 3.3.9 Set Pins

Actors: None

Description: This use case begins when the SCARAB determines a new port type. The SCARAB determines which pins to set as INPUT and OUTPUT. This use case ends when the pins are correctly set.

### 3.3.10 Read Data

Actors: PC, Cartridge Port

Description: This use case begins when the SCARAB gets a read request from the PC. The SCARAB reads data from the cartridge. This use case ends when the requested data has been read.

### 3.3.11 Write Data

Actors: PC, Cartridge Port

Description: This use case begins when the SCARAB gets a write request from the PC. The SCARAB receives the data and places it in a buffer. This use case ends when the requested data has been written to the cartridge.

### 3.3.12 Return Data

Actors: PC

Description: This use case begins when the SCARAB needs to send data to the PC. This use case ends when the SCARAB has sent the data to the PC.

### 3.3.13 Release Port

Actors: PC, Cartridge Port

Description: This use case begins when the PC sends a request to the SCARAB to release the cartridge port. The SCARAB cuts power to the port and disables all pins. This use case ends when the SCARAB sends a confirmation to the PC.

## 3.4 Detailed Use Cases

### 3.4.1 Dump Save

Actors: User, SCARAB Device
Difficulty: | ★★★★☆
Pre-conditions: | The SCARAB is connected to a PC with both USB cables. The PC is running the SCARAB GUI program. A cartridge port module is inserted into the SCARAB. A cartridge is inserted into the SCARAB’s cartridge port.
Main Success Scenario: | 1. The user opens the sidebar and selects the “Save Manager” option. 2. The program takes the user to the “Save Management” screen. 3. The user selects “Dump Save Data” from the main window. 4. The program prompts the user to confirm the dump, displaying the inserted cartridge name and image. 5. The user clicks “Dump Save”, and the SCARAB begins dumping the cartridge’s save file.
Post-conditions: | The SCARAB has successfully dumped the save file of the inserted cartridge to a new file on the PC.
Alternate Step(s): | 4a. The program prompts the user that the current cartridge does not store save data. 5a. The user cancels the dump.

### 3.4.2 Restore Save

Actors: User, SCARAB Device
Difficulty: | ★★★★☆
Pre-conditions: | The SCARAB is connected to a PC with both USB cables. The PC is running the SCARAB GUI program. A cartridge port module is inserted into the SCARAB. A cartridge is inserted into the SCARAB’s cartridge port.
Main Success Scenario: | 1. The user opens the sidebar and selects the “Save Manager” option. 2. The program takes the user to the “Save Management” screen. 3. The user selects “Restore Save Data” from the main window. 4. The program prompts the user to select a save file, displaying the dumped saves compatible with the inserted cartridge. 5. The user selects the save file they wish to restore, and clicks “Restore Save”. 6. The SCARAB begins restoring the save file to the cartridge.
Post-conditions: | The SCARAB has successfully restored the save data to the inserted cartridge.
Alternate Step(s): | 4a. The program prompts the user that the current cartridge does not store save data. 4b. The program prompts the user that there are no supported save files present for the current cartridge. 5a. The user backs out of the save file selection screen.

### 3.4.3 Check Health

Actors: User, SCARAB Device
Difficulty: | ★★★★★
Pre-conditions: | The SCARAB is connected to a PC with both USB cables. The PC is running the SCARAB GUI program. A cartridge port module is inserted into the SCARAB. A cartridge is inserted into the SCARAB’s cartridge port.
Main Success Scenario: | 1. The user opens the sidebar and selects the “Health Manager” option. 2. The program takes the user to the “Health Management” screen. 3. The user selects which tests they wish to perform on the cartridge. 4. The user clicks “Run Test(s)”. 5. The program brings the user to the testing screen, where it warns the user not to remove the cartridge during testing, while providing progress updates. 6. The SCARAB performs the test(s) on the cartridge.
Post-conditions: | The user can see the results of the test(s).
Alternate Step(s): | 3a. The user clicks “Run All Tests”.

### 3.4.4 Identify Corruption

Actors: User, SCARAB Device
Difficulty: | ★★★★☆
Pre-conditions: | The SCARAB is connected to a PC with both USB cables. The PC is running the SCARAB GUI program. A cartridge port module is inserted into the SCARAB. A cartridge is inserted into the SCARAB’s cartridge port.
Main Success Scenario: | 1. The user opens the sidebar and selects the “Health Manager” option. 2. The program takes the user to the “Health Management” screen. 3. The user selects the “Identify Corruption”. 4. The user clicks “Run Test(s)”. 5. The program brings the user to the testing screen, where it warns the user not to remove the cartridge during testing, while providing progress updates. 6. The SCARAB checks the ROM and save data for any corruption.
Post-conditions: | The user can see the results of the test.
Alternate Step(s):

### 3.4.5 Verify Checksum

Actors: User, SCARAB Device
Difficulty: | ★★★☆☆
Pre-conditions: | The SCARAB is connected to a PC with both USB cables. The PC is running the SCARAB GUI program. A cartridge port module is inserted into the SCARAB. A cartridge is inserted into the SCARAB’s cartridge port.
Main Success Scenario: | 1. The user opens the sidebar and selects the “Health Manager” option. 2. The program takes the user to the “Health Management” screen. 3. The user selects the “Verify Checksum”. 4. The user clicks “Run Test(s)”. 5. The program brings the user to the testing screen, where it warns the user not to remove the cartridge during testing, while providing progress updates. 6. The SCARAB calculates the checksum of the cartridges rom, and checks it against a known valid checksum.
Post-conditions: | The user can see the results of the test.
Alternate Step(s):

### 3.4.6 Test Pins

Actors: User, SCARAB Device
Difficulty: | ★★☆☆☆
Pre-conditions: | The SCARAB is connected to a PC with both USB cables. The PC is running the SCARAB GUI program. A cartridge port module is inserted into the SCARAB. A cartridge is inserted into the SCARAB’s cartridge port.
Main Success Scenario: | 1. The user opens the sidebar and selects the “Health Manager” option. 2. The program takes the user to the “Health Management” screen. 3. The user selects the “Test Pins”. 4. The user clicks “Run Test(s)”. 5. The program brings the user to the testing screen, where it warns the user not to remove the cartridge during testing, while providing progress updates. 6. The SCARAB reads areas of ROM multiple times and compares results.
Post-conditions: | The user can see the results of the test.
Alternate Step(s):

### 3.4.7 Test Save Retention

Actors: User, SCARAB Device
Difficulty: | ★★★★☆
Pre-conditions: | The SCARAB is connected to a PC with both USB cables. The PC is running the SCARAB GUI program. A cartridge port module is inserted into the SCARAB. A cartridge is inserted into the SCARAB’s cartridge port.
Main Success Scenario: | 1. The user opens the sidebar and selects the “Health Manager” option. 2. The program takes the user to the “Health Management” screen. 3. The user selects the “Test Save Retention”. 4. The user clicks “Run Test(s)”. 5. The program brings the user to the testing screen, where it warns the user not to remove the cartridge during testing, while providing progress updates. 6. The SCARAB loads the cartridge with a predetermined save, cuts power from the cartridge for 30 seconds, and checks the save on the cartridge against the original.
Post-conditions: | The user can see the results of the test.
Alternate Step(s):

### 3.4.8 Determine Port

Actors: Cartridge Port
Difficulty: | ★★★☆☆
Pre-conditions: | The SCARAB is powered. A cartridge port has just been inserted into the SCARAB device.
Main Success Scenario: | 1. The SCARAB detects that a new cartridge port has been inserted. 2. The SCARAB tests identifier lines on the module, and checks the returned voltages. 3. The voltages are checked against a table, to determine the inserted module type.
Post-conditions: | The SCARAB knows which cartridge port module has been inserted.
Alternate Step(s):

### 3.4.9 Set Pins

Actors: None
Difficulty: | ★☆☆☆☆
Pre-conditions: | The SCARAB is powered. The SCARAB has just determined the type of the inserted port.
Main Success Scenario: | 1. The SCARAB checks the correct pin layout for the inserted port module. 2. The SCARAB sets the appropriate pins to input or output.
Post-conditions: | The SCARAB has set the pins correctly.
Alternate Step(s):

### 3.4.10 Read Data

Actors: PC, Cartridge Port
Difficulty: | ★★☆☆☆
Pre-conditions: | The SCARAB is plugged into the PC. The SCARAB has received a read request from the PC.
Main Success Scenario: | 1. The SCARAB receives the address to read from, and the size of the read. 2. The SCARAB reads the data from the cartridge into a buffer.
Post-conditions: | The SCARAB has read the data at the requested address
Alternate Step(s): | 3. The SCARAB sends the full buffer to the PC, and continues reading.

### 3.4.11 Write Data

Actors: PC, Cartridge Port
Difficulty: | ★★★☆☆
Pre-conditions: | The SCARAB is plugged into the PC. The SCARAB has received a write request from the PC.
Main Success Scenario: | 1. The SCARAB receives the request data. 2. The SCARAB loads the writable data into a buffer. 3. The SCARAB writes the data to the cartridge, beginning at the specified address.
Post-conditions: | The SCARAB has written the data to the cartridge.
Alternate Step(s):

### 3.4.12 Return Data

Actors: PC
Difficulty: | ★☆☆☆☆
Pre-conditions: | The SCARAB is plugged into the PC. The SCARAB needs to send data to the PC program.
Main Success Scenario: | 1. The SCARAB performs a handshake with the PC program. 2. The SCARAB sends the data with packet headers along the serial line to the PC. 3. The SCARAB receives a response confirming transfer.
Post-conditions: | The SCARAB’s data has been transferred to the PC.
Alternate Step(s): | 2a. The PC has not responded to the handshake, so the SCARAB aborts the process.

### 3.4.13 Release Port

Actors: PC, Cartridge Port
Difficulty: | ★★★☆☆
Pre-conditions: | The SCARAB is plugged into the PC. The SCARAB has detected a port is being removed.
Main Success Scenario: | 1. The SCARAB sets all pins to INPUT, essentially disabling them. 2. The SCARAB cuts power to the cartridge port. 3. The SCARAB sends a “Port Removed” response to the PC.
Post-conditions: | The port module connector is no longer receiving power or data.
Alternate Step(s):

# 4. FURPS

## 4.1 Functionality

The SCARAB’s ability to read save data and test cartridges will be its main measure. It should be able to interact with a variety of cartridges, and detect issues with known damaged test cartridges. The SCARAB puts emphasis on modularity, so it must also be able to support a wide range of cartridges and cartridge port modules. The modules need to be able to be swapped seamlessly, with detections in place for removal and insertion of both cartridges and modules. The final iteration should have at least 5 different modules.

## 4.2 Usability

The SCARAB needs to be well documented, with graphical guides within the GUI program for module insertion. Given a SCARAB with no inserted port, a port module, an appropriate cartridge, and an installed SCARAB GUI, users new to the system should be able to begin a health check or save data dump within 60 seconds.

## 4.3 Reliability

The SCARAB will need to be very reliable, as malfunctions could cause damage to the cartridges which it is trying to preserve. Confirmed working cartridges will need to pass all tests 99% of the time. Cartridges with known defects, such as dirty pins or a dead internal battery, will also need to fail at minimum 1 test 95% of the time. Any time a module or cartridge has been removed, the SCARAB PC program should detect it within 1 second.

## 4.4 Performance

The SCARAB will need to be reasonably quick, within reason. The absolute maximum baud rate of the Arduino Mega’s serial line is 1 Megabit per second. Given constant data flow, that’s ~80 seconds for an 8MB N64 ROM dump for checksum calculation. Leaving room for pauses in data flow, the SCARAB should be able to transfer the contents of The Legend of Zelda: Ocarina of Time (32MB) within 6 minutes. Below is a table showing ROM sizes, Minimum Possible Time (MPT), and Acceptable Transfer Time (ATT).

Name | Console | Size | MPT | ATT
Super Mario Bros. 3 | NES | 384KB | 3.1s | 5s
Pokémon Red & Blue | GB | 1MB | 8s | 12s
Super Metroid | SNES | 3MB | 24s | 30s
Pokémon Crystal | GBC | 2MB | 16s | 20s
The Legend of Zelda: Ocarina of Time | N64 | 32MB | 5 Min 20s | 6 Min
Pokémon Ruby / Sapphire | GBA | 16MB | 2 Min 30s | 3 Min

## 4.5 Supportability

The SCARAB is designed with supportability in mind. New firmware should be able to be flashed to the microcontroller (Arduino, in this case) via the connecting cable. Modular cartridge ports should allow for future expansion to the list of compatible cartridges.

# 5. Metrics

There are certain criteria that the SCARAB must meet in order to be deemed a success. They are as follows:

- Users from the target demographic should be able to go from an unplugged SCARAB device and an installer for the PC program on the PCs desktop, to checking the health of an inserted cartridge, within 60 seconds.
- The SCARAB device should be able to detect the inserted module. The insertion or removal of modules should be detected by the SCARAB device and PC program within 0.5 seconds.
- The insertion or removal of cartridges into the modules should be detectable by the SCARAB and PC program within 1 second.
- The SCARAB device should be able to fully dump the save file of a cartridge within 5 seconds. The same 5 second timeframe applies to restoring a save file.
- The SCARAB must identify known issues in at least 95% of cases. Known working cartridges must not have any issues identified at least 99% of the time.
- The SCARAB should be able to identify whether the cartridge supports on-cartridge save data.
- The SCARAB should be able to dump ROMs for checksum validation as outlined in the table above (see 4.4 Performance).

# 6. Project Plan

Each use case of the SCARAB will need to be implemented in order of importance. Below is a timeline of the expected development of the SCARAB.

| October | | | | November | | | | December | | | | January | | | | February | | | | March | | | | April
Functional Specification
Research Document
Design Document
Read Data
Return Data
Check Health
Test Pins
Dump Save
Identify Corruption
Verify Checksum
Write Data
Test Save Retention
Restore Save
Determine Port
Set Pins
Release Port
Testing
Final Report

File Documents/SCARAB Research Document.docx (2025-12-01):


# SCARAB: Research Document

For submission to SETU

Author: Stuart Rossiter

Student Number: C00284845

Course: BSc (Hons.) Software Development

Supervisor: Joseph Kehoe

# 1. Abstract

The SCARAB device and accompanying program are retro game preservation tools designed to check the health of retro game cartridges, and manage their save data. The device, built around a microcontroller, interfaces with the cartridges via cartridge port modules. These modules can be swapped in and out, allowing for a variety of cartridge types, and providing future expansion options. The SCARAB device can auto-detect the inserted modules, and can detect whether a cartridge is inserted. The SCARAB program provides a GUI for the user to interact with. It provides options to dump and restore save data, run a full diagnostic checkup on an inserted cartridge, and run individual tests. It also serves as a save browser, allowing the user to view the save files they have dumped from cartridges.

# 2. Overview

When it comes to researching for the SCARAB, the research needed to be split up into 2 parts. One part focuses on the GUI PC Program. This first part goes into the choice of language for developing the program, and discusses the libraries which have been considered for use with the language. The second part of the research focuses on the SCARAB Device itself. First and foremost, research has been done about microcontrollers, as the “brain” of the device. In addition, the architecture of game cartridges will be discussed, as they will need to be interfaced with by the microcontroller. Finally, various electronic components will be required, and they will be discussed accordingly.

# 3. SCARAB PC Program

## 3.1 Languages

When it comes to choosing a language for the PC program portion of the SCARAB, a lot of thinking needed to be done. The list of requirements for a language are as follows:

- Does not need to be super performance oriented (e.g. Assembly).
- Needs to be able to interface with the SCARAB’s microcontroller.
- Needs to have a good GUI library.
- Needs to be cross platform (Windows, Linux, MacOS).

Several languages are being considered for this.

### 3.1.1 C++

Developed by Bjarne Stroustrup, C++ is a cross-platform language with a high level of control over system resources and memory, due to it being an extension of the C language (W3Schools, 2011). It’s an object-oriented language, facilitating structure and the reusability of code. C++ is known for being fast, as it is used in the likes of operating systems or embedded systems. While not necessary for the SCARAB, this is appreciated.

(Fig 3.1.1.1 – C++ Logo, (Wikimedia Commons, 2017))

With regards to microcontroller interfacing, C++ has a one-size-fits-all library: Boost.Asio. Boost.Asio is a part of the open-source Boost libraries, and it provides tools for asynchronous I/O, concurrency, and networking (Exito Technology, 2023). Boost.Asio provides means for communication over Wi-Fi and Serial connections, 2 prominent methods used by microcontrollers. Bluetooth can also be used, but it requires user implementation as it is not standard with Boost.Asio. The library also abstracts any platform-specific details, allowing for cross-platform support (Exito Technology, 2023).

Qt is a framework designed mainly around the creation of GUI based cross-platform applications. It contains a set of intuitive and modularized C++ library classes, and is loaded with APIs to simplify development (The Qt Company, n.d.). Tools such as Qt Design Studio, a UI design and development environment, also aid in development (The Qt Company, n.d.).

### 3.1.2 C#

Created by Microsoft, C# is a cross-platform general purpose language that runs on the .NET Framework (Microsoft, 2024). Much like C++, C# is in the C family of languages, leading to some familiar syntax such as ending lines with semi-colons, but with added features such as a “foreach” statement for any collection type.


(Fig 3.1.2.1 – C# Logo, (Microsoft, 2022))

C# has Wi-Fi and Serial connection modules built-in, allowing for easy communication with the SCARAB’s microcontroller. With regards to GUI development, C# has an open-source cross-platform framework in Avalonia. Avalonia is a dotnet framework, considered by many to be the spiritual successor of Windows Presentation Foundation, an open-source UI framework for Windows (AvaloniaUI, 2024).

### 3.1.3 Python

Python, created by Guido van Rossum in 1991, is a general-purpose language with a simple syntax, similar to the English language (W3Schools, n.d.). Given its simplicity, it allows for rapid development, aided by its abundance of external libraries. It is a high-level interpreted language, and as such, speed is not a strong point. As mentioned above, however, speed is not paramount for the SCARAB, but it would be appreciated.

(Fig 3.1.3.1 – Python Logo, (Wikimedia Commons, 2008))

For microcontroller communication, Python can cover all bases. The ‘socket’ module allows for communication with Wi-Fi and Bluetooth enabled boards, opening sockets for low-level networking (Python, 2020). For Serial communications, the pySerial library is ideal. The pySerial module encapsulates serial port access, providing cross-platform backends for Python (pyserial, 2022).

For GUI development, Python has its own binding of the GUI toolkit Qt, developed by The Qt Company themselves. The binding, known as PySide, is cross-platform, much like Qt. The PySide binding is open source under the GPLv3 and Qt commercial license (pyside, 2021).

# 4. SCARAB Device

## 4.1 Microcontrollers

To serve as an interface between the cartridge port modules and the SCARAB PC program, some kind of microcontroller was deemed necessary. Microcontrollers are small computers on a single chip. They contain a processor core, RAM, and EEPROM, for storing programs to run. The purpose of a microcontroller is to manage a specific set of tasks within an embedded system, without the need for a complex operating system (Schneider & Smalley, 2024). This is perfect for the SCARAB, as there are only a handful of tasks necessary.

### 4.1.1 Arduino

Among the reasons for choosing Arduino, the main one is the variety of development boards. Several families of boards exist, such as Nano, MKR, UNO, Classic, and Mega, sporting over 30 different boards between them (Arduino, 2022). Given the sheer number of boards, and all their different configurations, there is sure to be a board suitable for the SCARAB. In addition to this, Arduino is inexpensive, has cross-platform support, and the software and hardware are completely open source. Choosing Arduino is not all that needs to be chosen, however. If Arduino is to be chosen, a specific board needs to be chosen. Below are some such boards.

#### 4.1.1.1 Arduino Mega 2560 Rev3


(Fig 4.1.1.1.1 – Arduino Mega 2560, (Arduino, n.d.))

Based on the ATmega2560 microcontroller, the Arduino Mega 2560 Rev3 contains everything needed to support the ATMega2560, including 54 digital I/O pins, 16 analog inputs, 4 hardware serial ports, a 16MHz crystal oscillator, USB connection, and a power jack (Arduino, 2025). The Mega 2560 has enough GPIO pins to handle even the largest of cartridge ports, and the Arduino “port” system allows for the reading from/writing to 8 pins at a time, i.e. 1 byte, all in one single instruction. The Mega 2560 runs on 5V logic. Most cartridges run at 5V logic, with the occasional 3.3V cartridges, so bus transceivers would be needed in these scenarios.

#### 4.1.1.2 Arduino UNO R3


(Fig 4.1.1.2.1 – Arduino UNO R3, (ARDUINO, 2021))

The Arduino UNO R3 is based around the ATmega328P, which is socketed on the board to allow for easy replacement of it in case of failure. The board supports the microcontroller with 14 digital I/O pins, 6 analog inputs, a 16MHz ceramic resonator, a USB connection, and a power jack (Arduino, 2022). To handle the cartridge I/O, the Arduino UNO would need some form of multiplexing and latches, to interface with different lines and to store those inputs/outputs. In addition to that, the UNO runs at 3.3V. The UNO R3 also runs on 5V logic, much like the Mega 2560. Most cartridges run at 5V logic, with the occasional 3.3V cartridges, so bus transceivers would be needed in these scenarios.

### 4.1.2 ESP32

The ESP32 family of chips and boards are developed by Espressif; a fabless silicon vendor based in China, and founded in 2008 (Cording, 2022). Centred around Wi-Fi and Bluetooth connectivity, the ESP32 chip is ideal for Internet of Things (IoT) devices, wearables, and smart home automation. Below are some ESP32 boards.

#### 4.1.2.1 ESP32-P4-Function-EV-Board


(Fig 4.1.2.1.1 – ESP32-P4-Function-EV-Board, (Espressif, 2016))

Clocking in at a maximum of 400MHz, the ESP32-P4 features a dual-core RISC-V processor, supporting the likes of USB 2.0, MIPI-CSI/DSI, H264 Encoder, and various other peripherals (Espressif, 2016). The board supports WiFi 6, Bluetooth 5.0, USB type A and C, Ethernet, and has 55 GPIOs. It also runs at 3.3V, which will require boosting to 5V for some cartridge types. The ESP32-P4-Function-EV-Board seems to be overkill for the project, and it seems to be geared towards audio and video devices.

#### 4.1.2.2 ESP32-C6-DevKitM-1

(Fig 4.1.2.1.1 – ESP32-C6-DevKitM-1, (Espressif, 2023))

The ESP32-C6-MINI-1(U) supports WiFi 6, Bluetooth 5.0, and maxes out at 160MHz (Espressif, 2023). With 22 GPIO pins, the board would need some form of multiplexing and latches, to interface with different lines and to store those inputs/outputs. Much like the ESP32-P4-Function-EV-Board, the ESP32-C6-DevKitM-1 is geared towards audio and video devices, or IoT usage.

## 4.2 Languages

There are a variety of languages supported by the above microcontrollers, all with their pros and cons:

### 4.2.1 Arduino Language


(Fig 4.2.1.1 – Arduino IDE Logo, (Wikimedia Commons, n.d.))

The Arduino programming language is essentially C++ with extra features. It serves as the default programming language for Arduino boards, for use with the Arduino IDE (Arduino, n.d.). As it is based on C++, the Arduino language is fast and lightweight. Support for ESP32 microcontrollers is available, using an Arduino core developed by Espressif, the creators of the ESP32 microcontrollers (Espressif, 2019). The Arduino language is also heavily documented, with code examples available directly from the Arduino IDEs (Arduino, 2025).

### 4.2.2 MicroPython

(Fig 4.2.2.1 – MicroPython Logo, (Wikimedia Commons, 2018))

MicroPython is an implementation of Python 3 that includes a small subset of the Python standard library, optimised to run on microcontrollers and in constrained environments (MicroPython, 2024). Despite all these optimizations, it still has some drawbacks. The main drawback is its compatibility. Among the Arduino boards, only a select few are even compatible (Arduino, 2025). ESP32 boards surpass the specifications for MicroPython, however, and it would be suited to them.

### 4.2.3 TinyGo


(Fig 4.2.3.1 – TinyGo Logo, (TinyGo, 2024))

Bringing concurrency to embedded systems, TinyGo is a port of the Go language to microcontrollers. Unfortunately, it has several flaws as of current. Many microcontrollers are not well-supported, such as the ATmega328P seen in the Arduino UNO, or the ESP32 seen in the ESP32-P4-Function-EV-Board (TinyGo, 2024). It lacks Wi-Fi and Bluetooth support for the ESP32 – one of the microcontroller’s main selling points. In addition to this, the main selling point of Go is its concurrency, but this is irrelevant for microcontrollers possessing only a single core (most Arduino boards). For this reason, there is no reason to use TinyGo on single-core microcontrollers, as it can not be leveraged to its full potential.

## 4.3 Game Cartridges

The SCARAB is intended to interface with many different cartridges through its module boards. The architecture of these cartridges varies, so measures must be taken on a system-by-system basis.

### 4.3.1 Nintendo Entertainment System (NES)

Released in 1983 in Japan as the Famicom, and later in Europe in 1986 (Nintendo, 2016), the NES single-handedly saved the gaming industry. The cartridges, known as Game Paks (a recurring name for Nintendo), have since become iconic.


(Fig. 3.3.1.1 NES Cartridge External View) (Fig. 3.3.1.2 NES Cartridge Internal View)

Earlier games, such as Super Mario Bros, were simple to read and write to, as they contained 2 important chips: one containing 32KB of Program ROM, and the other containing 8KB of Character ROM. These were part of a board revision known as NROM-256 (NESdev Wiki, 2024). The problem with reading later cartridges comes from the introduction of “Mapper Chips”. These chips allowed the NES to bypass its 16-bit address bus limit, by swapping the currently accessible ROM data on the cartridge, allowing for much bigger games (NESdev Wiki, 2023). All but 20 games are covered by the Action 53, MMC1, and MMC3 families, so implementing the 256 registered mappers is not a goal of this project.

Figure 3.3.1.3 shows the pinout of the NES cartridge connector. Most of the important pins for this project come in the format “XXX YZ”, where XXX is either CPU (leading to Program ROM), or PPU (leading to Character ROM), Y is either A for address line or D for data line, and Z is the number for the line. Other important pins include the 5V and GND lines, M2 for the mapper chips, /ROMSEL, CPU R/W, PPU /RD, and CIC +RST (Reset).

(Fig 3.3.1.3 NES cartridge pinout (NESdev Wiki, 2023))

### 4.3.2 Super Nintendo Entertainment System (SNES)

In 1990, Nintendo Japan released the Super Famicom, the 16-bit successor to the Famicom. This was later released in Europe in June 1992 as the SNES (Nintendo, 2016).


(Fig. 3.3.2.1 SNES Cartridges External View) (Fig. 3.3.2.2 SNES Cartridges Internal View)

Many games are straightforward to read from and interface with. The problems arise with some of the “Enhancement Chips” that were seen in later games. Some enhancement chips hold no effect on the reading of cartridges, such as the Super FX chip (seen in Starwing, see MARIO CHIP-1 in Fig 3.3.2.2). The Super Accelerator 1 (SA1) chip, however, is troublesome.

The SA1 is a coprocessor, running at 10.74 MHz: 4 times faster than the speed of the SNES CPU (SnesLab, 2025). As seen in figure 3.3.2.3, it has pins which interface directly with ROM, and has pins for CIC data. This is where the problem lies. Some ROM data is locked behind the SA1 coprocessor, as it contains a Super MMC memory mapper chip. The SA1 begins in a sleeping state, to be woken by the SNES CPU, which will not happen if the CIC lockout chip and correct clock timing are not made available to the SA1. This can be overcome, as seen in how the Sanni Open-Source Cartridge Reader works (sanni, 2024). For the sake of this project, the SA1 bypass will be skipped. It may be implemented down the line.


(Fig. 3.3.2.3 SNES SA1 Chip Pinout (SNESdev Wiki, 2025)) (Fig 3.3.2.4 SNES Connector Pinout (SNESdev Wiki, 2022))

### 4.3.3 Nintendo 64 (N64)

1996 graced Japanese store shelves with the world’s first 64-bit home videogame system: the Nintendo 64. The following year, it was released in Europe, to critical acclaim (Nintendo, 2016).


(Fig. 3.3.3.1 N64 Cartridge External View) (Fig. 3.3.3.2 N64 Cartridge Internal View)

The N64 marks the first cartridge type in my research to use 3.3V power and logic, as opposed to 5V. This is where bus transceivers and a buck converter will be needed see (3.4.1 and 1.4.2).


Figure 3.3.3.3 shows the pinout of the N64 cartridge. AD0-15 are multifunctional. They control the upper 2 bytes of the address input, the lower 2 bytes of the address input, and the 2 bytes of data output. The addresses are latched within the cartridge by the ALE_L and ALE_H pins, and the data is read with the RD pin.

In addition to those, the GND, 3.3V, RESET, and EEPROM_DAT lines will likely be required.

(Fig. 3.3.3.3 N64 Connector Pinout (ConsoleMods Wiki, 2022))

### 4.3.4 Game Boy (GB)

In 1989, Nintendo Japan released the first handheld game system with interchangeable game cartridges. Its name? The Game Boy. It released alongside Tetris, one of its bestselling games. In 1990, the Game Boy came to Europe, and with it, Nintendo of Europe was formed (Nintendo, 2016).


(Fig. 3.3.4.1 Game Boy Cartridge External View) (Fig. 3.3.4.2 Game Boy Cartridge Internal View)

The Game Boy, much like the NES, had mapper chips of its own. Games larger than 32KB needed to use these mapper chips. These chips allowed for “banks” of ROM data to be switched in and out, for access via the address lines. This could be achieved by writing specific values to areas on the cartridge (Retrocomputing Stack Exchange, 2019). Apart from that, addressing the ROM is rather straightforward.


(Fig. 3.3.4.3 GB Connector Pinout (ConsoleMods Wiki, 2022))

Above is the pinout for the Game Boy cartridge. All but AUDIO IN will likely be required.

### 4.3.5 Game Boy Color (GBC)

1998 saw the release of the next step up from the Game Boy, in the Game Boy Color (Nintendo, 2016).


(Fig. 3.3.5.1 GBC Cartridge External View) (Fig. 3.3.5.2 GBC Cartridge Internal View)

From my research, the Game Boy Color cartridges utilise the same addressing and banking systems that the original Game Boy used. This makes things easier, as they are essentially Game Boy games, but bigger.

### 4.3.6 Game Boy Advance (GBA)

The Game Boy Advance released worldwide in 2001, being marked as the fastest selling console ever with over 500k units sold in its first week in Europe. 2 years later, we would see it take on a new clam-shell form; the Game Boy Advance SP (Nintendo, 2016).


(Fig. 3.3.6.1 GBA Cartridge External View) (Fig. 3.3.6.2 GBA Cartridge Internal View)

GBA cartridges are the second cartridges to use 3.3V power and logic. So long as the first read is non-sequential, it’s possible to sequentially read from the ROM by pulsing the “RD” pin repeatedly, to a point (Ziegler, 2025).


(Fig. 3.3. GBA Connector Pinout (ConsoleMods Wiki, 2022))

Reading the ROM is simple enough. The save data depends on the format, however. If it is battery backed SRAM, it’s simple reads and writes. Flash storage requires specific “commands” sent as writes to memory (Korth, 2024). EEPROM is easily the most annoying of the 3. To make a long story short, it handles data serially, i.e. one bit at a time (DenSinH, 2021).

## 4.4 Electronic Components

### 4.4.1 Bus Transceiver

As the GBA and N64 cartridges utilise 3.3V logic, as opposed to the Arduino’s 5V logic, some form of voltage lowering was required. The method of choice was the SN74LVC245AN Octal Bus Transceiver. The bus transceiver allows for bi-directional voltage modulation, converting 5V to 3.3V on one side, and 3.3V to 5V on the other. This feature lets the device function as a translator in mixed 3.3V and 5V environments (Texas Instruments, 2015). These transceivers will allow the Arduino’s 5V logic to interface with the 3.3V logic of the GBA and N64 cartridges.

### 4.4.2 Buck Converter

Not only do the GBA and N64 cartridges use 3.3V logic, but they utilise 3.3V VCC too. The transceivers would not work for the level of amps required, so a new solution was needed. This is where buck converters are introduced. Buck converters convert a DC voltage to a lower DC voltage, such as 5V to 3.3V in this case (Yates, 2024).

### 4.4.3 USB-C Input Module

While a microcontroller has enough power to interface with the cartridge, it doesn’t support the Amps necessary to also power it. Using a USB-C cable, the SCARAB could draw the power necessary from a USB port on the PC. While this will require 2 USB cables to be connected between the SCARAB and the PC, it’s preferable to the alternative of batteries.

### 4.4.4 Cartridge Ports

A microcontroller may have many I/O pins, but cartridges can’t be inserted directly into pins. Cartridge ports are widely available, mostly known by their pin count. For example, the NES port is known as a 72-pin connector. These ports have pins which can be slotted into pin connectors, or directly into PCBs, which will be the case for the cartridge port modules.

### 4.4.5 Resistors

Resistors are passive devices used to control the flow of current in a circuit. Controlling current flow helps to prevent damage to fragile components.

### 4.4.6 EEPROM

EEPROM chips will be used for identification of modules. They can work using serial connections, which the microcontrollers can either support natively or spoof with the correct timing.

# 5. Similar Products

## 5.1 Open Source Cartridge Reader (OSCR)

Created by Sanni, the Open Source Cartridge Reader is a device designed to allow the dumping of cartridge ROMs and Save Data, along with the restoring of saves.

Similarities:

- Both the SCARAB and OSCR will dump and restore save data.
- Both the SCARAB and OSCR use microcontrollers.
- Both the SCARAB and OSCR can calculate the checksum of a cartridge.

Differences:

- The OSCR does not check the checksum against a known valid checksum.
- The OSCR does not interface with a PC. It’s a standalone device with an LCD and SD card. The SCARAB has a PC program it interacts with.
- The SCARAB has automatic voltage detection as standard, with the OSCR it is a modification.
- The OSCR focuses on software preservation, and the SCARAB focuses more on hardware preservation.
- The OSCR solders in multiple cartridge ports to the device itself, where the SCARAB uses a plug-and-play module system.

## 5.2 Retrode2

The Retrode2 is a USB interface for retro cartridges and controllers. It allows users to play their favourite retro games on PC emulators.

Similarities:

- The Retrode2 allows for save dumping and restoring.
- The Retrode2 interfaces with a PC.

Differences:

- The Retrode2 does not check the integrity of the cartridges.
- The Retrode2 serves as an adaptor for SNES and Sega controllers to PC.
- The Retrode2’s main purpose is to bridge the gap between the cartridges and emulators on modern machines, where the SCARAB’s main purpose is hardware preservation.

# 6. Conclusion

Throughout this document, many aspects of the SCARAB have been researched and discussed. First was the GUI Program, where the candidates for language were discussed. Python has been chosen as the language for the program, with the pyserial and PySide libraries. As far as the SCARAB device is concerned, all aspects of it have been researched. The microcontroller chosen is the Arduino Mega 2560. The language of choice for the Arduino is the default C++ based Arduino language. Space conservation is important, so MicroPython won’t do, and TinyGo is focused on concurrency, but the Mega 2560 only has one core. Cartridge pinouts and architecture were also discussed. This was a very important topic, as the Arduino must interface with the cartridges. Knowing which pins are necessary, and where they lie on the connectors, along with any other oddities relating to the cartridges is paramount. Extra components are required, as research had found. These were simple things, such as bus transceivers and buck converters to handle voltage differences, cartridge ports to provide a more familiar interface for the Arduino, USB-C inputs for power, and resistors for many different things.

This document has established several ideas which are important to remember for the development of this project:

- Cartridges are complex. Voltages are different. Pins are different. Pin count is different. Some have extra chips such as mapper chips, EEPROMs, and even CPUs.
- Sometimes, simplicity is ok. For example, C++ may have better speed and memory control than Python, but none of that is needed for this project.

# 7. Appendix

# 8. Glossary

SCARAB – Save and Cartridge Aid Requiring Adapter Boards

UI – User Interface

GUI – Graphical User Interface

RAM – Random Access Memory

EEPROM – Electrically Erasable Programmable Read-Only Memory

I/O – Input/Output

ROM – Read Only Memory

CPU – Central Processing Unit

PPU – Pixel Processing Unit

SRAM – Static Random Access Memory

OSCR – Open Source Cartridge Reader

LCD – Liquid Crystal Display

SD – Secure Digital

USB – Universal Serial Bus

DC – Direct Current

CIC – Checking Integrated Circuit

IoT – Internet of Things

GPIO – General Purpose Input Output

# 9. Bibliography

Anon., 2025. PySide. [Online]
Available at: https://www.pythonguis.com/topics/pyside
[Accessed 12 October 2025].

ARDUINO, 2021. Arduino Uno Rev3. [Online]
Available at: https://store.arduino.cc/products/arduino-uno-rev3
[Accessed 9 November 2025].

Arduino, 2022. Arduino Hardware. [Online]
Available at: https://www.arduino.cc/en/hardware
[Accessed 9 October 2025].

Arduino, 2022. UNO R3 | Arduino Documentation. [Online]
Available at: https://docs.arduino.cc/hardware/uno-rev3
[Accessed 9 November 2025].

Arduino, 2025. Arduino® MEGA 2560 Rev3. [Online]
Available at: https://docs.arduino.cc/resources/datasheets/A000067-datasheet.pdf
[Accessed 10 October 2025].

Arduino, 2025. Built-in Examples. [Online]
Available at: https://docs.arduino.cc/built-in-examples
[Accessed 9 November 2025].

Arduino, 2025. MicroPython. [Online]
Available at: https://docs.arduino.cc/micropython
[Accessed 9 November 2025].

Arduino, n.d. Arduino IDE. [Online]
Available at: https://docs.arduino.cc/software/ide
[Accessed 9 November 2025].

Arduino, n.d. Arduino Mega 2560. [Online]
Available at: https://store-usa.arduino.cc/cdn/shop/files/A000067_00.front_1000x750.jpg?v=1727102662
[Accessed 11 October 2025].

AvaloniaUI, 2024. GitHub - AvaloniaUI/Avalonia: Develop Desktop, Embedded, Mobile and WebAssembly apps with C# and XAML. The most popular .NET UI client technology. [Online]
Available at: https://github.com/avaloniaui/avalonia
[Accessed 9 November 2025].

ConsoleMods Wiki, 2022. Game Boy Connector Pinouts. [Online]
Available at: https://consolemods.org/wiki/Game_Boy:Connector_Pinouts
[Accessed 12 October 2025].

ConsoleMods Wiki, 2022. GBA Connector Pinouts. [Online]
Available at: https://consolemods.org/wiki/GBA:Connector_Pinouts
[Accessed 12 October 2025].

ConsoleMods Wiki, 2022. N64 Connector Pinouts. [Online]
Available at: https://consolemods.org/wiki/N64:Connector_Pinouts
[Accessed 12 October 2025].

Cording, S., 2022. What Is the ESP32? Its Brief History and How to Get Started. [Online]
Available at: https://www.elektormagazine.com/articles/what-is-the-esp32
[Accessed 9 November 2025].

Dahl, Ø. N., 2023. What Is A Resistor And What Does It Do?. [Online]
Available at: https://www.build-electronic-circuits.com/what-is-a-resistor
[Accessed 11 October 2025].

DenSinH, 2021. [GBA] EEPROM Save Type. [Online]
Available at: https://densinh.github.io/DenSinH/emulation/2021/02/01/gba-eeprom.html
[Accessed 12 October 2025].

Espressif, 2016. ESP32-P4-Function-EV-Board v1.5.2 - ESP32-P4 - — esp-dev-kits latest documentation. [Online]
Available at: https://docs.espressif.com/projects/esp-dev-kits/en/latest/esp32p4/esp32-p4-function-ev-board/user_guide.html
[Accessed 9 November 2025].

Espressif, 2019. espressif/arduino-esp32. [Online]
Available at: https://github.com/espressif/arduino-esp32
[Accessed 9 November 2025].

Espressif, 2023. ESP32-C6-DevKitM-1 - ESP32-C6 - — esp-dev-kits latest documentation. [Online]
Available at: https://docs.espressif.com/projects/esp-dev-kits/en/latest/esp32c6/esp32-c6-devkitm-1/user_guide.html
[Accessed 9 November 2025].

Exito Technology, 2023. Boost.Asio: A Powerful Networking Library for C++. [Online]
Available at: https://medium.com/@extio/boost-asio-a-powerful-networking-library-for-c-e86367c2568d
[Accessed 9 November 2025].

GitHub, 2022. pyserial. [Online]
Available at: https://github.com/pyserial/pyserial
[Accessed 12 October 2025].

Korth, M., 2024. GBATEK - GBA/NDS Technical Info. [Online]
Available at: https://problemkaputt.de/gbatek.htm#gbacartbackupflashrom
[Accessed 12 October 2025].

Kumar, A., 2023. Why do We Use the Arduino Programming Language? How is it Helpful?. [Online]
Available at: https://emeritus.org/blog/coding-arduino-programming-language
[Accessed 12 October 2025].

MicroPython, 2024. The MicroPython project. [Online]
Available at: https://github.com/micropython/micropython
[Accessed 9 November 2025].

Microsoft, 2022. File:Logo C sharp.svg. [Online]
Available at: https://commons.wikimedia.org/wiki/File:Logo_C_sharp.svg
[Accessed 09 November 2025].

Microsoft, 2024. Overview - A tour of C#. [Online]
Available at: https://learn.microsoft.com/en-us/dotnet/csharp/tour-of-csharp/overview
[Accessed 9 November 2025].

NESdev Wiki, 2023. Cartridge connector. [Online]
Available at: https://www.nesdev.org/wiki/Cartridge_connector
[Accessed 11 October 2025].

NESdev Wiki, 2023. Mapper. [Online]
Available at: https://www.nesdev.org/wiki/Mapper
[Accessed 11 October 2025].

NESdev Wiki, 2024. NROM. [Online]
Available at: https://www.nesdev.org/wiki/NROM
[Accessed 11 October 2025].

Nintendo, 2016. Nintendo History. [Online]
Available at: https://www.nintendo.com/en-gb/Hardware/Nintendo-History/Nintendo-History-625945.html
[Accessed 11 October 2025].

pyserial, 2022. pySerial. [Online]
Available at: https://github.com/pyserial/pyserial
[Accessed 9 November 2025].

pyside, 2021. GitHub - pyside/pyside-setup: Git super project for PySide. [Online]
Available at: https://github.com/pyside/pyside-setup
[Accessed 9 November 2025].

Python, 2020. socket — Low-level networking interface — Python 3.8.1 documentation. [Online]
Available at: https://docs.python.org/3/library/socket.html
[Accessed 9 November 2025].

Retrocomputing Stack Exchange, 2019. How does the Gameboy's memory bank switching work?. [Online]
Available at: https://retrocomputing.stackexchange.com/questions/11732/how-does-the-gameboys-memory-bank-switching-work
[Accessed 12 October 2025].

sanni, 2024. Reading SNES SFC carts.. [Online]
Available at: https://github.com/sanni/cartreader/wiki/Reading-SNES-SFC-carts
[Accessed 12 October 2025].

Schneider, J. & Smalley, I., 2024. What is a microcontroller?. [Online]
Available at: https://www.ibm.com/think/topics/microcontroller
[Accessed 9 October 2025].

SNESdev Wiki, 2022. Cartridge connector. [Online]
Available at: https://snes.nesdev.org/wiki/Cartridge_connector
[Accessed 12 October 2025].

SNESdev Wiki, 2025. SA-1 Pinout. [Online]
Available at: https://snes.nesdev.org/wiki/SA-1_Pinout
[Accessed 12 October 2025].

SnesLab, 2025. SA-1. [Online]
Available at: https://sneslab.net/wiki/SA-1
[Accessed 12 October 2025].

Texas Instruments, 2015. SN74LVC245A Octal Bus Transceiver With 3-State Outputs. [Online]
Available at: https://www.ti.com/lit/ds/symlink/sn74lvc245a.pdf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
[Accessed 11 October 2025].

The Qt Company, n.d. Qt Features, Framework Essentials, Modules, Tools & Add-Ons. [Online]
Available at: https://www.qt.io/product/features
[Accessed 9 November 2025].

The Qt Company, n.d. Qt Framework - One framework to rule all!. [Online]
Available at: https://www.qt.io/product/framework
[Accessed 9 November 2025].

TinyGo, 2024. Microcontrollers. [Online]
Available at: https://tinygo.org/docs/reference/microcontrollers
[Accessed 9 November 2025].

TinyGo, 2024. TinyGo Home. [Online]
Available at: https://tinygo.org
[Accessed 9 November 2025].

W3Schools, 2011. C++ Introduction. [Online]
Available at: https://www.w3schools.com/cpp/cpp_intro.asp
[Accessed 9 November 2025].

W3Schools, n.d. Introduction to Python. [Online]
Available at: https://www.w3schools.com/python/python_intro.asp
[Accessed 9 November 2025].

Wikimedia Commons, 2008. File:Python-logo-notext.svg - Wikimedia Commons. [Online]
Available at: https://commons.wikimedia.org/wiki/File:Python-logo-notext.svg
[Accessed 9 November 2025].

Wikimedia Commons, 2017. File:ISO C++ Logo.svg - Wikimedia Commons. [Online]
Available at: https://commons.wikimedia.org/wiki/File:ISO_C%2B%2B_Logo.svg
[Accessed 9 November 2025].

Wikimedia Commons, 2018. File:MicroPython new logo.jpg - Wikimedia Commons. [Online]
Available at: https://commons.wikimedia.org/wiki/File:MicroPython_new_logo.jpg
[Accessed 9 November 2025].

Wikimedia Commons, n.d. Arduino IDE logo. [Online]
Available at: https://commons.wikimedia.org/wiki/File:Arduino_IDE_logo.svg
[Accessed 9 November 2025].

Yates, J., 2024. Understanding Buck and Boost Converters and the Capacitors Behind Them. [Online]
Available at: https://blog.knowlescapacitors.com/blog/understanding-buck-and-boost-converters-and-the-capacitors-behind-them
[Accessed 11 October 2024].

Ziegler, R., 2025. Gameboy Advance. [Online]
Available at: https://reinerziegler.de.mirrors.gg8.se/GBA/gba.htm
[Accessed 12 October 2025].

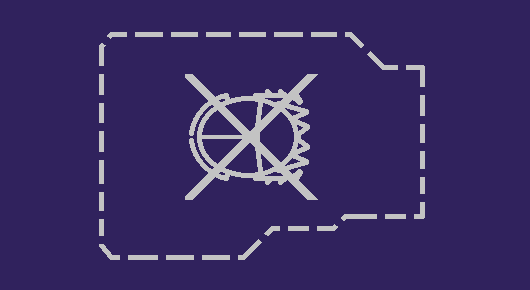
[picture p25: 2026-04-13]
Code/SCARAB Program/Images/SCARAB/not_found.png

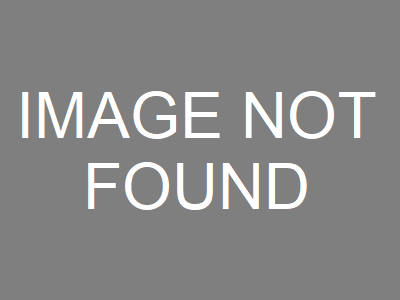
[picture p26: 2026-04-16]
Code/SCARAB Program/Images/cart_image_not_found.png

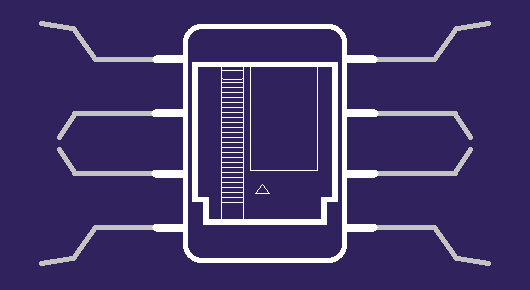
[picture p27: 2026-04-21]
Code/SCARAB Program/Images/Modules/NES.png

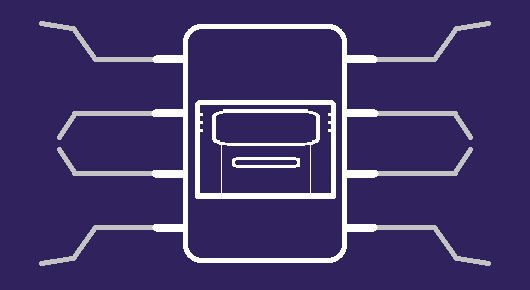
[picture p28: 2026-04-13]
Code/SCARAB Program/Images/Modules/SNES.png

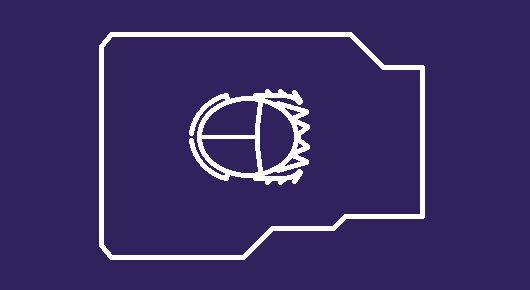
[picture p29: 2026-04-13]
Code/SCARAB Program/Images/SCARAB/found.png

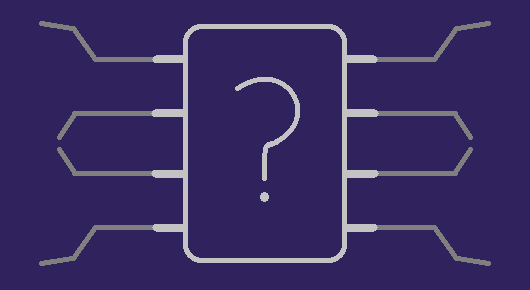
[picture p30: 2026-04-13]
Code/SCARAB Program/Images/Modules/NONE.png

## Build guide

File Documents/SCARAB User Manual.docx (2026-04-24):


# SCARAB: User Manual

For submission to SETU

Author: Stuart Rossiter

Student Number: C00284845

Course: BSc (Hons.) Software Development

Supervisor: Joseph Kehoe

# Requirements

2 Available USB Ports

Arduino IDE

# Installation Instructions

## PC PROGRAM

### Windows:

Download the SCARAB_Setup_Win.exe from GitHub.

Run the installer.

### Linux:

Download the SCARAB_Linux.zip file from GitHub.

Extract the zip file, and run SCARAB

## SCARAB DEVICE

Download the Arduino IDE from the Arduino website.

Download the SCARAB_SKETCH.zip file from GitHub.

Extract it, and open the SCARAB.ino file with the Arduino IDE.

Plug in your Arduino Mega 2560 you will be using for the SCARAB.

Compile and upload the sketch to the Arduino.

# How to Use

Insert the Arduino Mega into the SCARAB Main PCB.

Insert the USB-C Power Cable and USB-A Serial cable into the SCARAB and Arduino respectively.

Insert a module into the SCARAB, with the module facing away from the SCARAB’s Main PCB.

Insert a cartridge into the SCARAB’s module.

Run the SCARAB PC Program.

If the SCARAB GUI Program is running for the first time, it will not auto-identify the SCARAB. This needs to be enabled in “Options”.

Click “Re-Identify SCARAB”. The SCARAB will be identified, along with the Module and Cartridge. If this is a new module, the EEPROM can be written to in “Options”.

Navigate to the “Check Health” menu.

Click “Check Health”.

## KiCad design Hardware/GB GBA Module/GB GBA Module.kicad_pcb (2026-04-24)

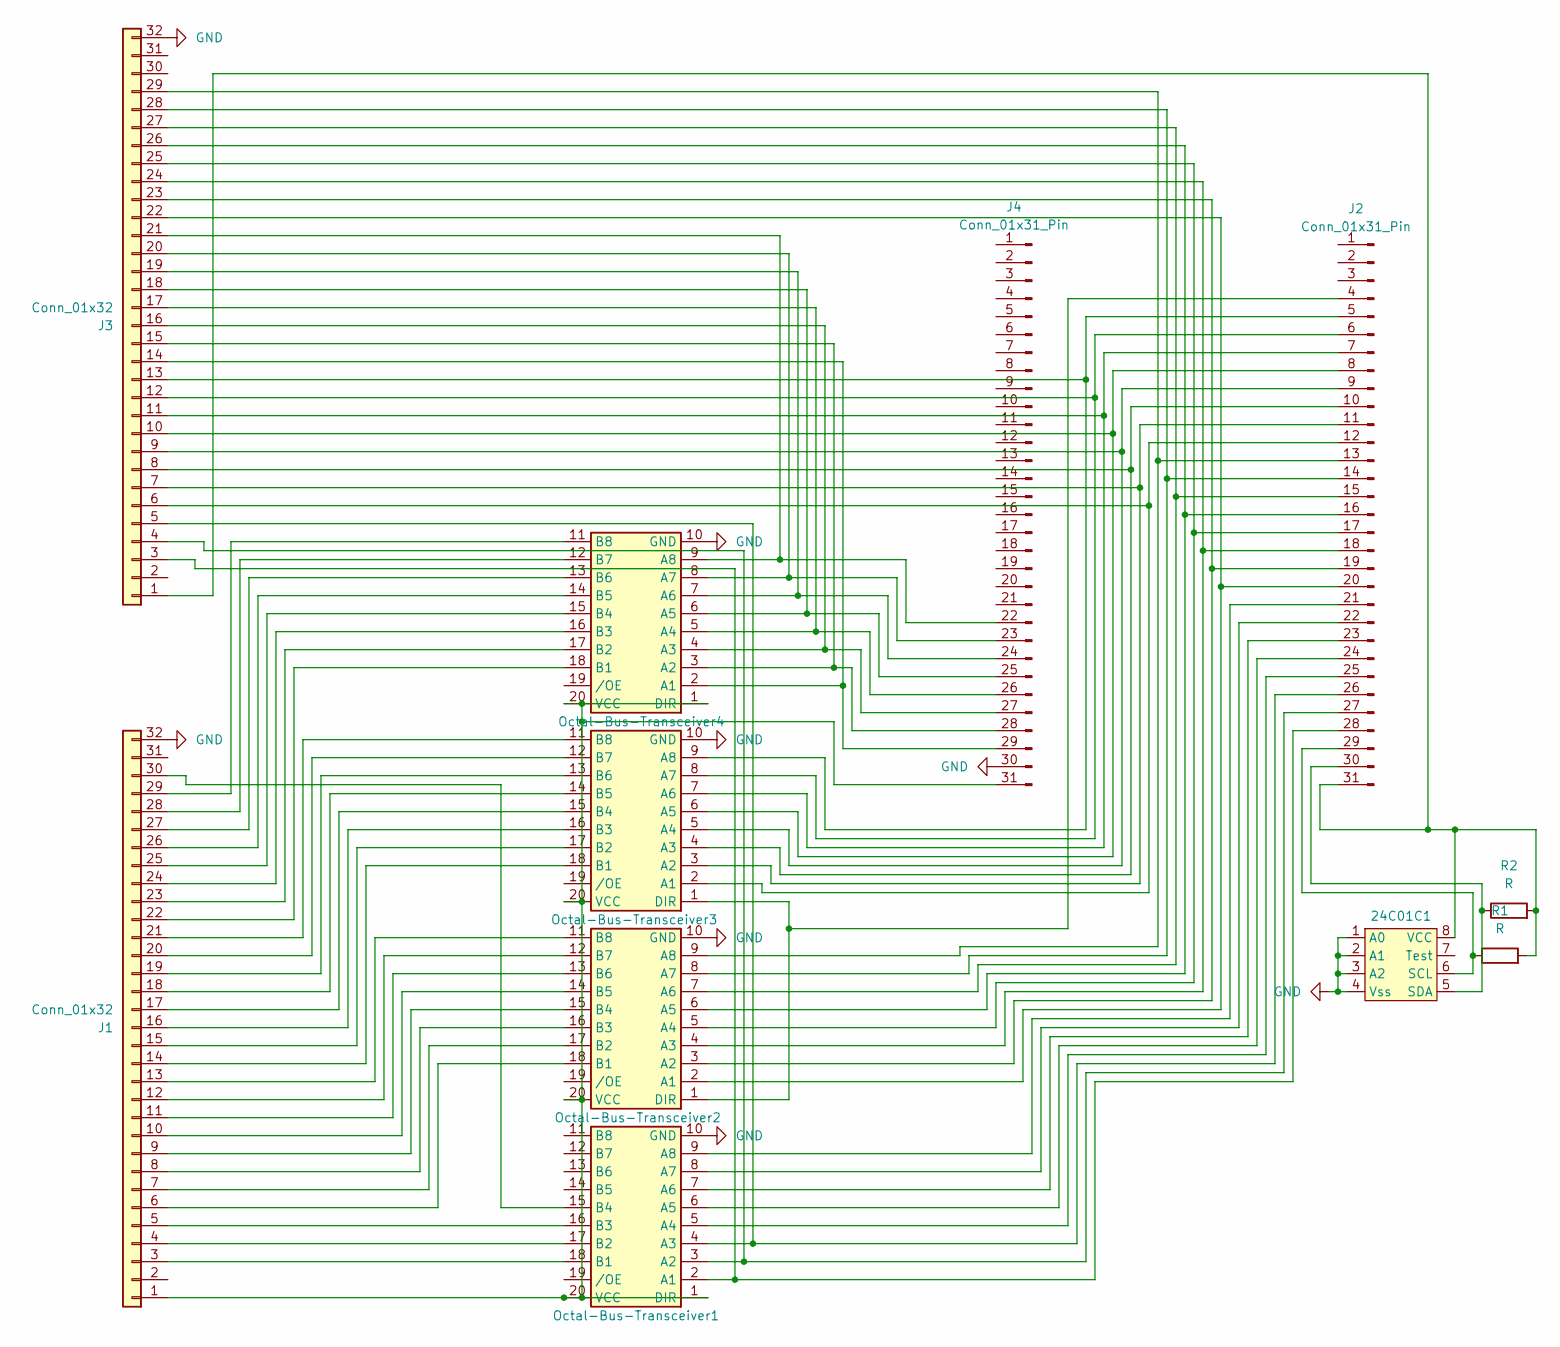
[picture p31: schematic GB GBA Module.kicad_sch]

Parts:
24C01C1: DIP-8_W7.62mm
J1, J3: Conn_01x32; GB_GBA_Cartridge_Port
J2, J4: Conn_01x31_Pin; PinSocket_1x31_P2.54mm_Vertical
Octal-Bus-Transceiver1, Octal-Bus-Transceiver2, Octal-Bus-Transceiver3, Octal-Bus-Transceiver4: CERDIP-20_W7.62mm_SideBrazed
R1, R2: R; R_Axial_DIN0207_L6.3mm_D2.5mm_P10.16mm_Horizontal

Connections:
GND: 24C01C1.1 (A0), 24C01C1.2 (A1), 24C01C1.3 (A2), 24C01C1.4 (Vss), J1.32, J3.32, J4.30, Octal-Bus-Transceiver1.10 (GND), Octal-Bus-Transceiver2.10 (GND), Octal-Bus-Transceiver3.10 (GND), Octal-Bus-Transceiver4.10 (GND)
unnamed: 24C01C1.6 (SCL), J2.29, R1.1
unnamed: 24C01C1.5 (SDA), J2.30, R2.1
unnamed: 24C01C1.8 (VCC), J2.31, J3.1, R1.2, R2.2
unnamed: J1.1, J4.31, Octal-Bus-Transceiver1.1 (DIR), Octal-Bus-Transceiver1.20 (VCC), Octal-Bus-Transceiver2.20 (VCC), Octal-Bus-Transceiver3.20 (VCC), Octal-Bus-Transceiver4.1 (DIR), Octal-Bus-Transceiver4.20 (VCC)
unnamed: J1.3, Octal-Bus-Transceiver1.18 (B1)
unnamed: J1.4, Octal-Bus-Transceiver1.17 (B2)
unnamed: J1.5, Octal-Bus-Transceiver1.16 (B3)
unnamed: J1.6, Octal-Bus-Transceiver2.18 (B1)
unnamed: J1.7, Octal-Bus-Transceiver2.17 (B2)
unnamed: J1.8, Octal-Bus-Transceiver2.16 (B3)
unnamed: J1.9, Octal-Bus-Transceiver2.15 (B4)
unnamed: J1.10, Octal-Bus-Transceiver2.14 (B5)
unnamed: J1.11, Octal-Bus-Transceiver2.13 (B6)
unnamed: J1.12, Octal-Bus-Transceiver2.12 (B7)
unnamed: J1.13, Octal-Bus-Transceiver2.11 (B8)
unnamed: J1.14, Octal-Bus-Transceiver3.18 (B1)
unnamed: J1.15, Octal-Bus-Transceiver3.17 (B2)
unnamed: J1.16, Octal-Bus-Transceiver3.16 (B3)
unnamed: J1.17, Octal-Bus-Transceiver3.15 (B4)
unnamed: J1.18, Octal-Bus-Transceiver3.14 (B5)
unnamed: J1.19, Octal-Bus-Transceiver3.13 (B6)
unnamed: J1.20, Octal-Bus-Transceiver3.12 (B7)
unnamed: J1.21, Octal-Bus-Transceiver3.11 (B8)
unnamed: J1.22, Octal-Bus-Transceiver4.18 (B1)
unnamed: J1.23, Octal-Bus-Transceiver4.17 (B2)
unnamed: J1.24, Octal-Bus-Transceiver4.16 (B3)
unnamed: J1.25, Octal-Bus-Transceiver4.15 (B4)
unnamed: J1.26, Octal-Bus-Transceiver4.14 (B5)
unnamed: J1.27, Octal-Bus-Transceiver4.13 (B6)
unnamed: J1.28, Octal-Bus-Transceiver4.12 (B7)
unnamed: J1.29, Octal-Bus-Transceiver4.11 (B8)
unnamed: J1.30, Octal-Bus-Transceiver1.15 (B4)
unnamed: J2.4, Octal-Bus-Transceiver2.1 (DIR), Octal-Bus-Transceiver3.1 (DIR)
unnamed: J2.5, J3.13, Octal-Bus-Transceiver3.9 (A8)
unnamed: J2.6, J3.12, Octal-Bus-Transceiver3.8 (A7)
unnamed: J2.7, J3.11, Octal-Bus-Transceiver3.7 (A6)
unnamed: J2.8, J3.10, Octal-Bus-Transceiver3.6 (A5)
unnamed: J2.9, J3.9, Octal-Bus-Transceiver3.5 (A4)
unnamed: J2.10, J3.8, Octal-Bus-Transceiver3.4 (A3)
unnamed: J2.11, J3.7, Octal-Bus-Transceiver3.3 (A2)
unnamed: J2.12, J3.6, Octal-Bus-Transceiver3.2 (A1)
unnamed: J2.13, J3.29, Octal-Bus-Transceiver2.9 (A8)
unnamed: J2.14, J3.28, Octal-Bus-Transceiver2.8 (A7)
unnamed: J2.15, J3.27, Octal-Bus-Transceiver2.7 (A6)
unnamed: J2.16, J3.26, Octal-Bus-Transceiver2.6 (A5)
unnamed: J2.17, J3.25, Octal-Bus-Transceiver2.5 (A4)
unnamed: J2.18, J3.24, Octal-Bus-Transceiver2.4 (A3)
unnamed: J2.19, J3.23, Octal-Bus-Transceiver2.3 (A2)
unnamed: J2.20, J3.22, Octal-Bus-Transceiver2.2 (A1)
unnamed: J2.21, Octal-Bus-Transceiver1.9 (A8)
unnamed: J2.22, Octal-Bus-Transceiver1.8 (A7)
unnamed: J2.23, Octal-Bus-Transceiver1.7 (A6)
unnamed: J2.24, Octal-Bus-Transceiver1.6 (A5)
unnamed: J2.25, Octal-Bus-Transceiver1.5 (A4)
unnamed: J2.26, J3.5, Octal-Bus-Transceiver1.4 (A3)
unnamed: J2.27, J3.4, Octal-Bus-Transceiver1.3 (A2)
unnamed: J2.28, J3.3, Octal-Bus-Transceiver1.2 (A1)
unnamed: J3.14, J4.29, Octal-Bus-Transceiver4.2 (A1)
unnamed: J3.15, J4.28, Octal-Bus-Transceiver4.3 (A2)
unnamed: J3.16, J4.27, Octal-Bus-Transceiver4.4 (A3)
unnamed: J3.17, J4.26, Octal-Bus-Transceiver4.5 (A4)
unnamed: J3.18, J4.25, Octal-Bus-Transceiver4.6 (A5)
unnamed: J3.19, J4.24, Octal-Bus-Transceiver4.7 (A6)
unnamed: J3.20, J4.23, Octal-Bus-Transceiver4.8 (A7)
unnamed: J3.21, J4.22, Octal-Bus-Transceiver4.9 (A8)

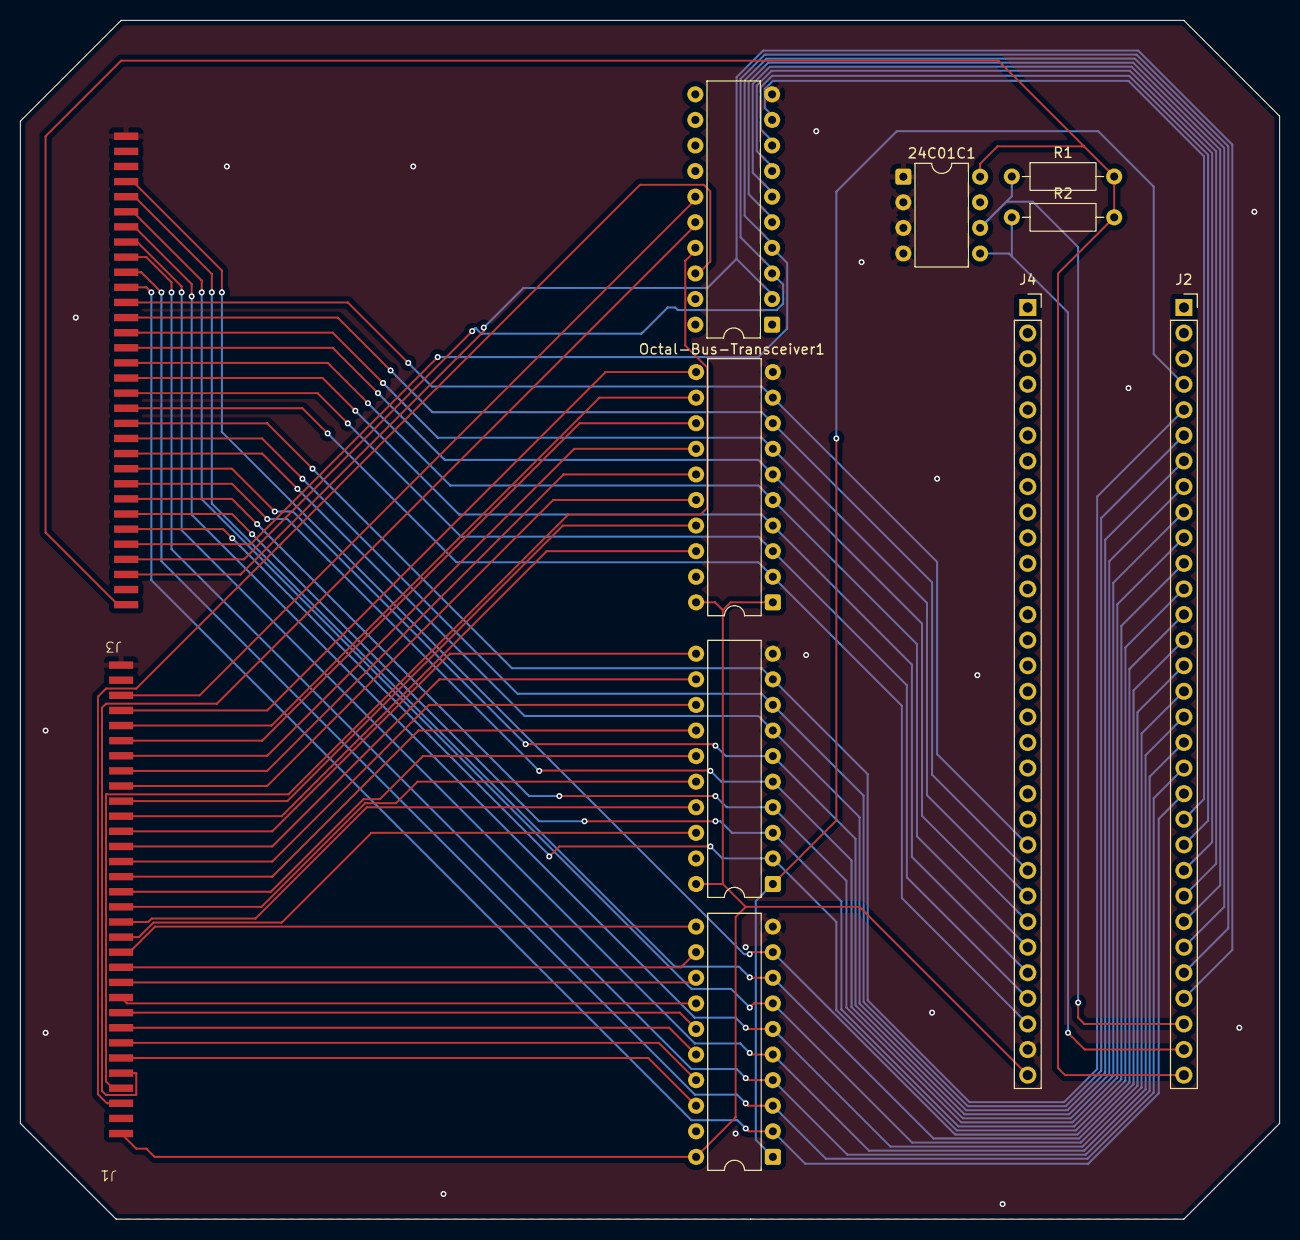
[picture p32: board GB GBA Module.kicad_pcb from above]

Board: 2 copper layers, 125.0 x 119.0 mm, 11 parts (0 on the bottom side), 66 nets.

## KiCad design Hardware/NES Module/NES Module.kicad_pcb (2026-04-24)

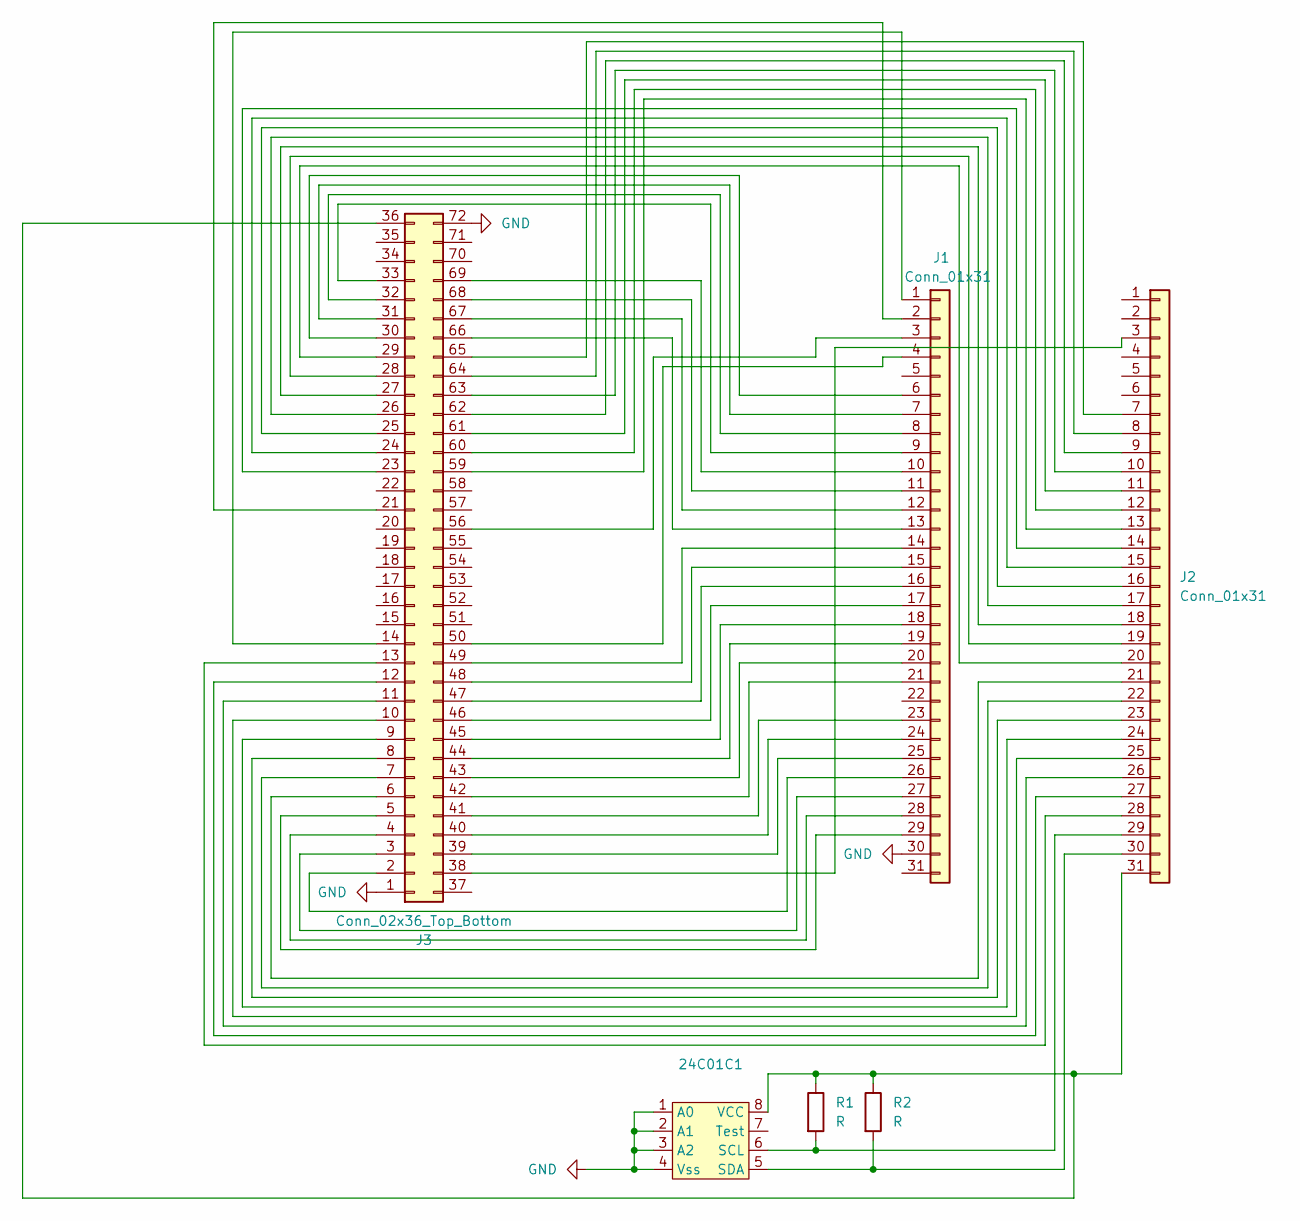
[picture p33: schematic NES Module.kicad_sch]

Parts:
24C01C1: DIP-8_W7.62mm
J1, J2: Conn_01x31; PinHeader_1x31_P2.54mm_Vertical
J3: Conn_02x36_Top_Bottom; NES_Cartridge_Port
R1, R2: R; R_Axial_DIN0207_L6.3mm_D2.5mm_P10.16mm_Horizontal

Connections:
GND: 24C01C1.1 (A0), 24C01C1.2 (A1), 24C01C1.3 (A2), 24C01C1.4 (Vss), J1.30, J3.1, J3.72
unnamed: 24C01C1.6 (SCL), J2.29, R1.2
unnamed: 24C01C1.5 (SDA), J2.30, R2.2
unnamed: 24C01C1.8 (VCC), J2.31, J3.36, R1.1, R2.1
unnamed: J1.1, J3.14
unnamed: J1.2, J3.21
unnamed: J1.3, J3.56
unnamed: J1.4, J3.50
unnamed: J1.6, J3.30
unnamed: J1.7, J3.31
unnamed: J1.8, J3.32
unnamed: J1.9, J3.33
unnamed: J1.10, J3.69
unnamed: J1.11, J3.68
unnamed: J1.12, J3.67
unnamed: J1.13, J3.66
unnamed: J1.14, J3.49
unnamed: J1.15, J3.48
unnamed: J1.16, J3.47
unnamed: J1.17, J3.46
unnamed: J1.18, J3.45
unnamed: J1.19, J3.44
unnamed: J1.20, J3.43
unnamed: J1.21, J3.42
unnamed: J1.23, J3.41
unnamed: J1.24, J3.40
unnamed: J1.25, J3.39
unnamed: J1.26, J3.2
unnamed: J1.27, J3.3
unnamed: J1.28, J3.4
unnamed: J1.29, J3.5
unnamed: J2.3, J3.38
unnamed: J2.7, J3.65
unnamed: J2.8, J3.64
unnamed: J2.9, J3.62
unnamed: J2.10, J3.63
unnamed: J2.11, J3.61
unnamed: J2.12, J3.60
unnamed: J2.13, J3.59
unnamed: J2.14, J3.23
unnamed: J2.15, J3.24
unnamed: J2.16, J3.25
unnamed: J2.17, J3.26
unnamed: J2.18, J3.27
unnamed: J2.19, J3.28
unnamed: J2.20, J3.29
unnamed: J2.21, J3.6
unnamed: J2.22, J3.7
unnamed: J2.23, J3.8
unnamed: J2.24, J3.9
unnamed: J2.25, J3.10
unnamed: J2.26, J3.11
unnamed: J2.27, J3.12
unnamed: J2.28, J3.13

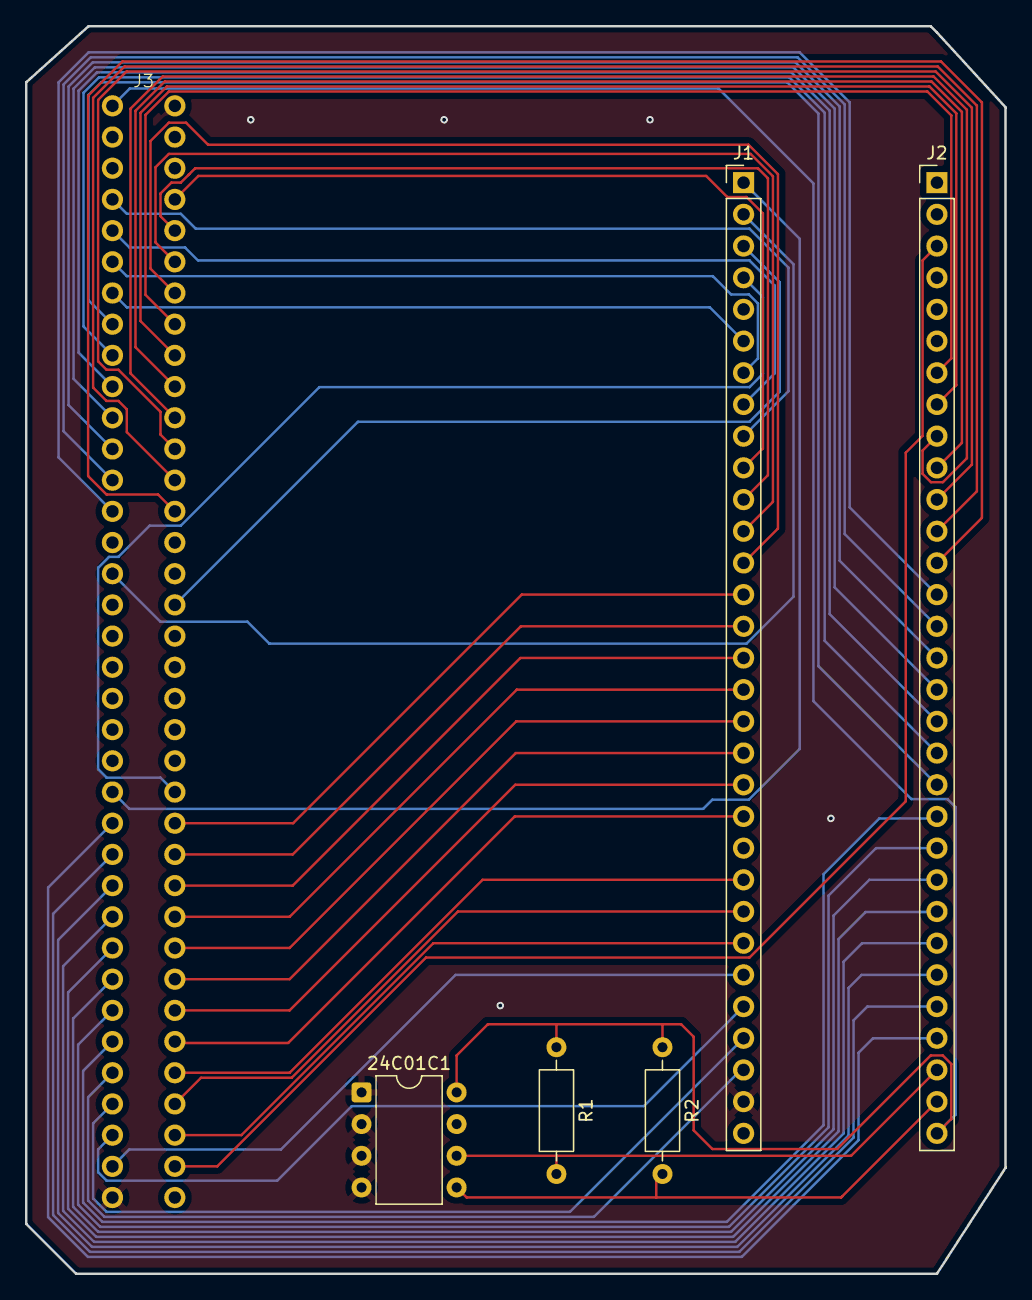
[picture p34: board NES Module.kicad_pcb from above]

Board: 2 copper layers, 78.5 x 100.0 mm, 6 parts (0 on the bottom side), 54 nets.

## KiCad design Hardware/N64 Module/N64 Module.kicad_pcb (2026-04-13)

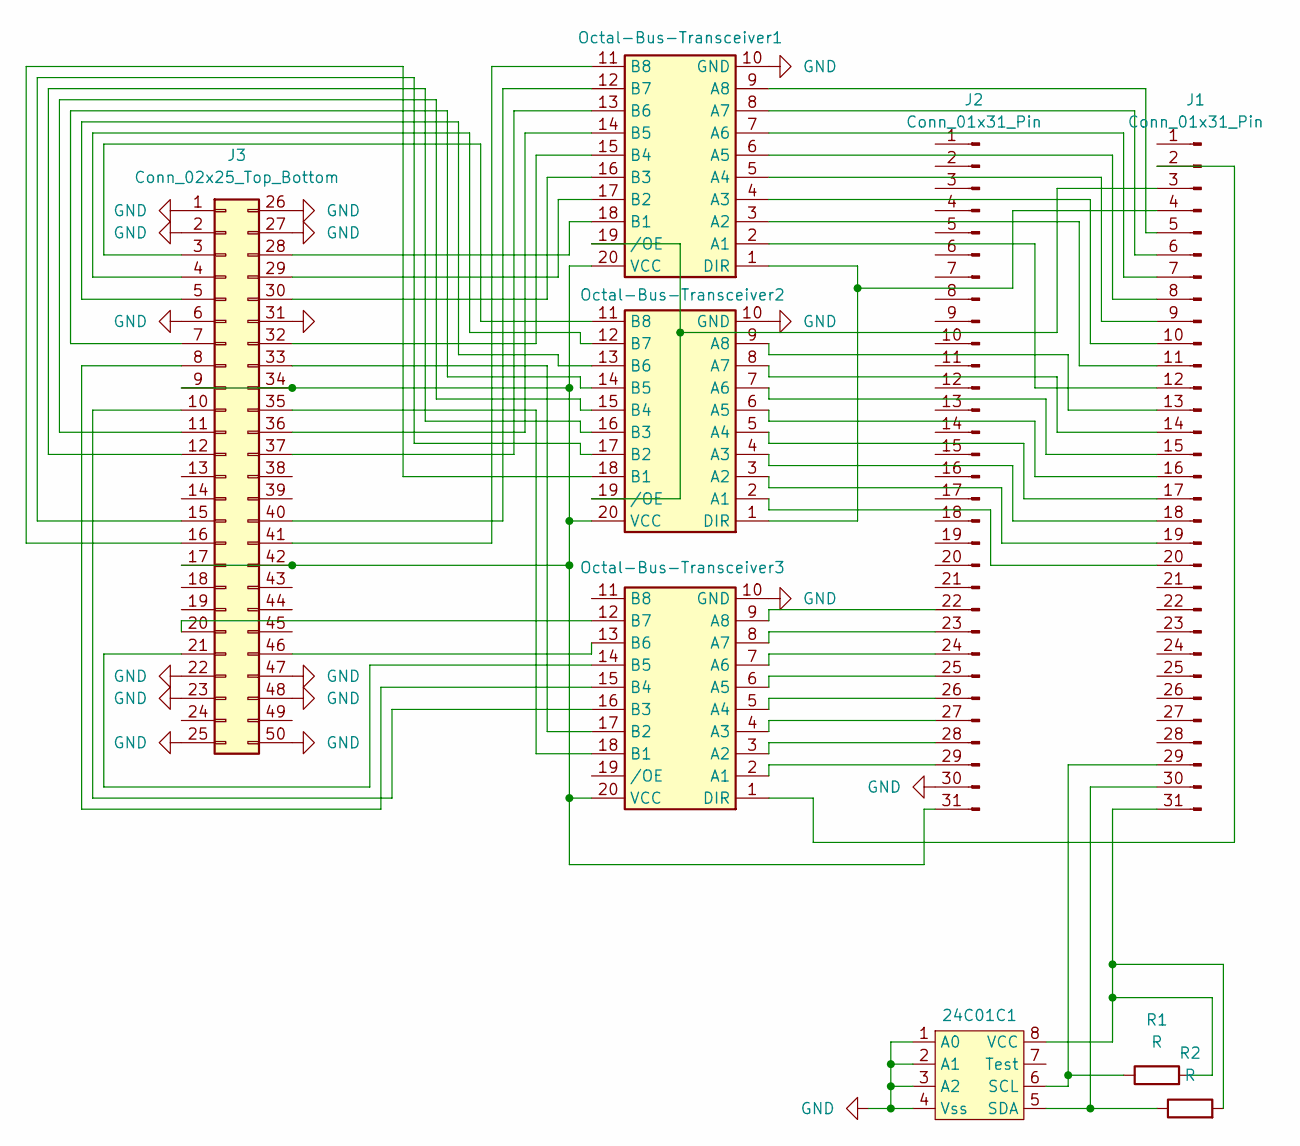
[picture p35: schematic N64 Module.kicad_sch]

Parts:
24C01C1: DIP-8_W7.62mm
J1, J2: Conn_01x31_Pin; PinSocket_1x31_P2.54mm_Vertical
J3: Conn_02x25_Top_Bottom; PinHeader_2x25_P2.54mm_Vertical
Octal-Bus-Transceiver1, Octal-Bus-Transceiver2, Octal-Bus-Transceiver3: CERDIP-20_W7.62mm_SideBrazed
R1, R2: R; R_Axial_DIN0207_L6.3mm_D2.5mm_P10.16mm_Horizontal

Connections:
GND: 24C01C1.1 (A0), 24C01C1.2 (A1), 24C01C1.3 (A2), 24C01C1.4 (Vss), J2.30, J3.1, J3.2, J3.6, J3.22, J3.23, J3.25, J3.26, J3.27, J3.31, J3.47, J3.48, J3.50, Octal-Bus-Transceiver1.10 (GND), Octal-Bus-Transceiver2.10 (GND), Octal-Bus-Transceiver3.10 (GND)
unnamed: 24C01C1.6 (SCL), J1.29, R1.1
unnamed: 24C01C1.5 (SDA), J1.30, R2.1
unnamed: 24C01C1.8 (VCC), J1.31, R1.2, R2.2
unnamed: J1.2, Octal-Bus-Transceiver3.1 (DIR)
unnamed: J1.3, Octal-Bus-Transceiver1.19 (/OE), Octal-Bus-Transceiver2.19 (/OE)
unnamed: J1.4, Octal-Bus-Transceiver1.1 (DIR), Octal-Bus-Transceiver2.1 (DIR)
unnamed: J1.5, Octal-Bus-Transceiver1.9 (A8)
unnamed: J1.6, Octal-Bus-Transceiver1.8 (A7)
unnamed: J1.7, Octal-Bus-Transceiver1.7 (A6)
unnamed: J1.8, Octal-Bus-Transceiver1.6 (A5)
unnamed: J1.9, Octal-Bus-Transceiver1.5 (A4)
unnamed: J1.10, Octal-Bus-Transceiver1.4 (A3)
unnamed: J1.11, Octal-Bus-Transceiver1.3 (A2)
unnamed: J1.12, Octal-Bus-Transceiver1.2 (A1)
unnamed: J1.13, Octal-Bus-Transceiver2.9 (A8)
unnamed: J1.14, Octal-Bus-Transceiver2.8 (A7)
unnamed: J1.15, Octal-Bus-Transceiver2.7 (A6)
unnamed: J1.16, Octal-Bus-Transceiver2.6 (A5)
unnamed: J1.17, Octal-Bus-Transceiver2.5 (A4)
unnamed: J1.18, Octal-Bus-Transceiver2.4 (A3)
unnamed: J1.19, Octal-Bus-Transceiver2.3 (A2)
unnamed: J1.20, Octal-Bus-Transceiver2.2 (A1)
unnamed: J2.22, Octal-Bus-Transceiver3.9 (A8)
unnamed: J2.23, Octal-Bus-Transceiver3.8 (A7)
unnamed: J2.24, Octal-Bus-Transceiver3.7 (A6)
unnamed: J2.25, Octal-Bus-Transceiver3.6 (A5)
unnamed: J2.26, Octal-Bus-Transceiver3.5 (A4)
unnamed: J2.27, Octal-Bus-Transceiver3.4 (A3)
unnamed: J2.28, Octal-Bus-Transceiver3.3 (A2)
unnamed: J2.29, Octal-Bus-Transceiver3.2 (A1)
unnamed: J2.31, J3.9, J3.17, J3.34, J3.42, Octal-Bus-Transceiver1.20 (VCC), Octal-Bus-Transceiver2.20 (VCC), Octal-Bus-Transceiver3.20 (VCC)
unnamed: J3.3, Octal-Bus-Transceiver2.11 (B8)
unnamed: J3.4, Octal-Bus-Transceiver2.12 (B7)
unnamed: J3.5, Octal-Bus-Transceiver2.13 (B6)
unnamed: J3.7, Octal-Bus-Transceiver2.14 (B5)
unnamed: J3.8, Octal-Bus-Transceiver3.15 (B4)
unnamed: J3.10, Octal-Bus-Transceiver3.16 (B3)
unnamed: J3.11, Octal-Bus-Transceiver2.15 (B4)
unnamed: J3.12, Octal-Bus-Transceiver2.16 (B3)
unnamed: J3.15, Octal-Bus-Transceiver2.17 (B2)
unnamed: J3.16, Octal-Bus-Transceiver2.18 (B1)
unnamed: J3.20, Octal-Bus-Transceiver3.12 (B7)
unnamed: J3.21, Octal-Bus-Transceiver3.14 (B5)
unnamed: J3.28, Octal-Bus-Transceiver1.18 (B1)
unnamed: J3.29, Octal-Bus-Transceiver1.17 (B2)
unnamed: J3.30, Octal-Bus-Transceiver1.16 (B3)
unnamed: J3.32, Octal-Bus-Transceiver1.15 (B4)
unnamed: J3.33, Octal-Bus-Transceiver3.17 (B2)
unnamed: J3.35, Octal-Bus-Transceiver3.18 (B1)
unnamed: J3.36, Octal-Bus-Transceiver1.14 (B5)
unnamed: J3.37, Octal-Bus-Transceiver1.13 (B6)
unnamed: J3.40, Octal-Bus-Transceiver1.12 (B7)
unnamed: J3.41, Octal-Bus-Transceiver1.11 (B8)
unnamed: J3.46, Octal-Bus-Transceiver3.13 (B6)

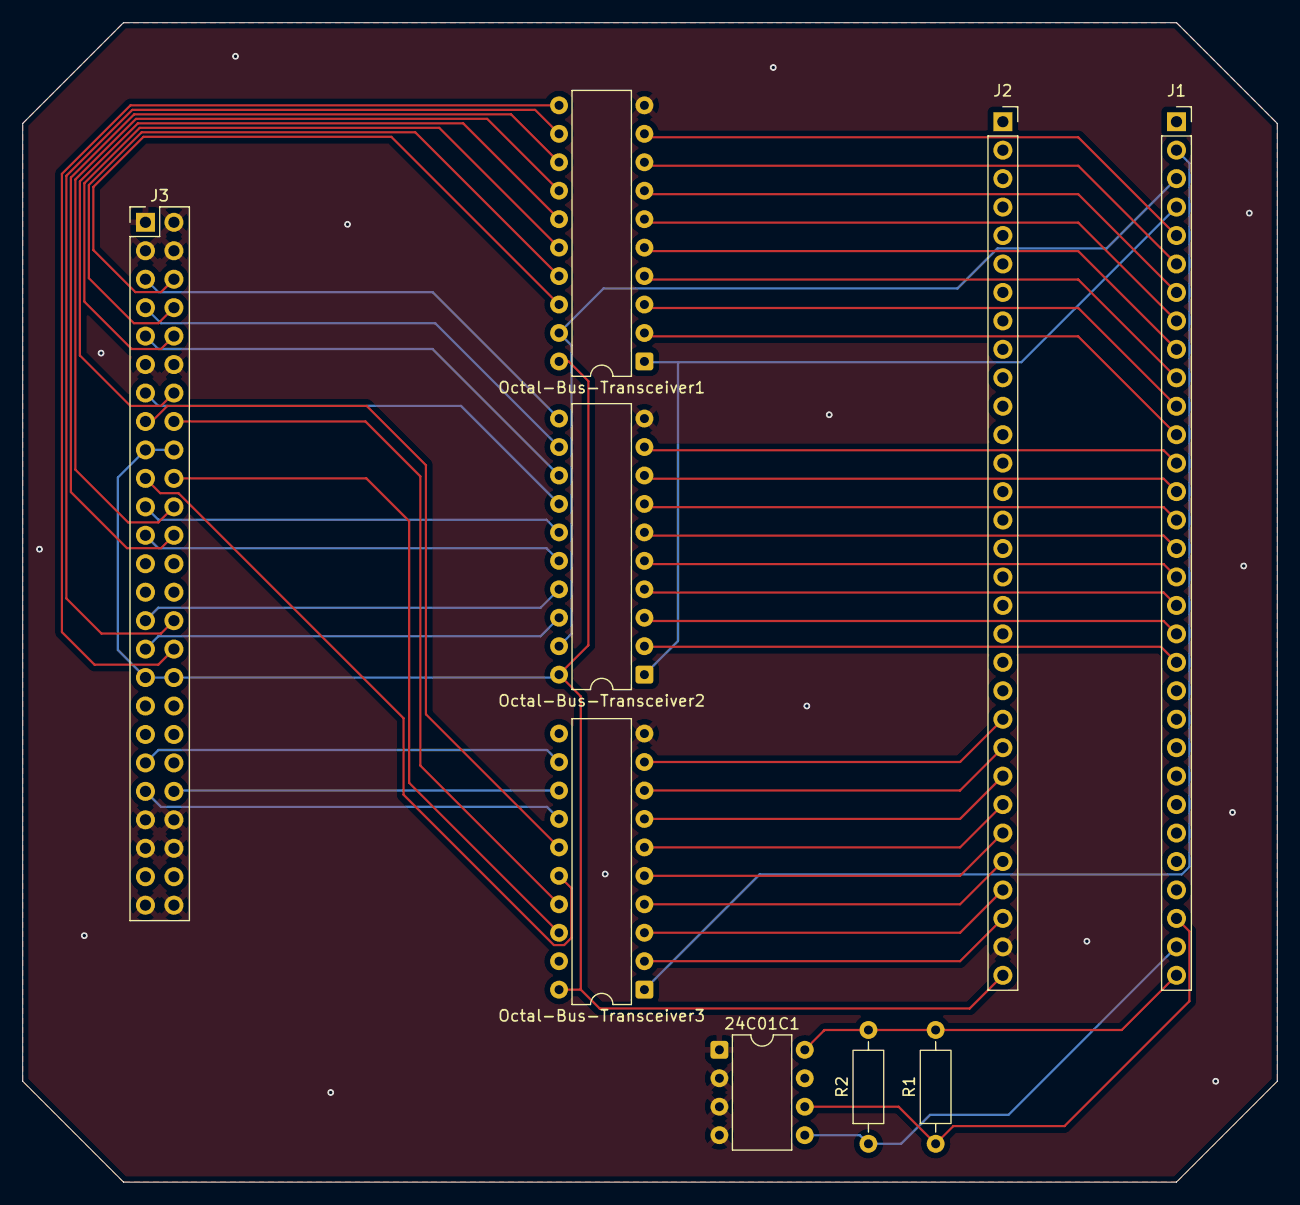
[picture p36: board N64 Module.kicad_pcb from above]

Board: 2 copper layers, 112.0 x 103.5 mm, 9 parts (0 on the bottom side), 55 nets.

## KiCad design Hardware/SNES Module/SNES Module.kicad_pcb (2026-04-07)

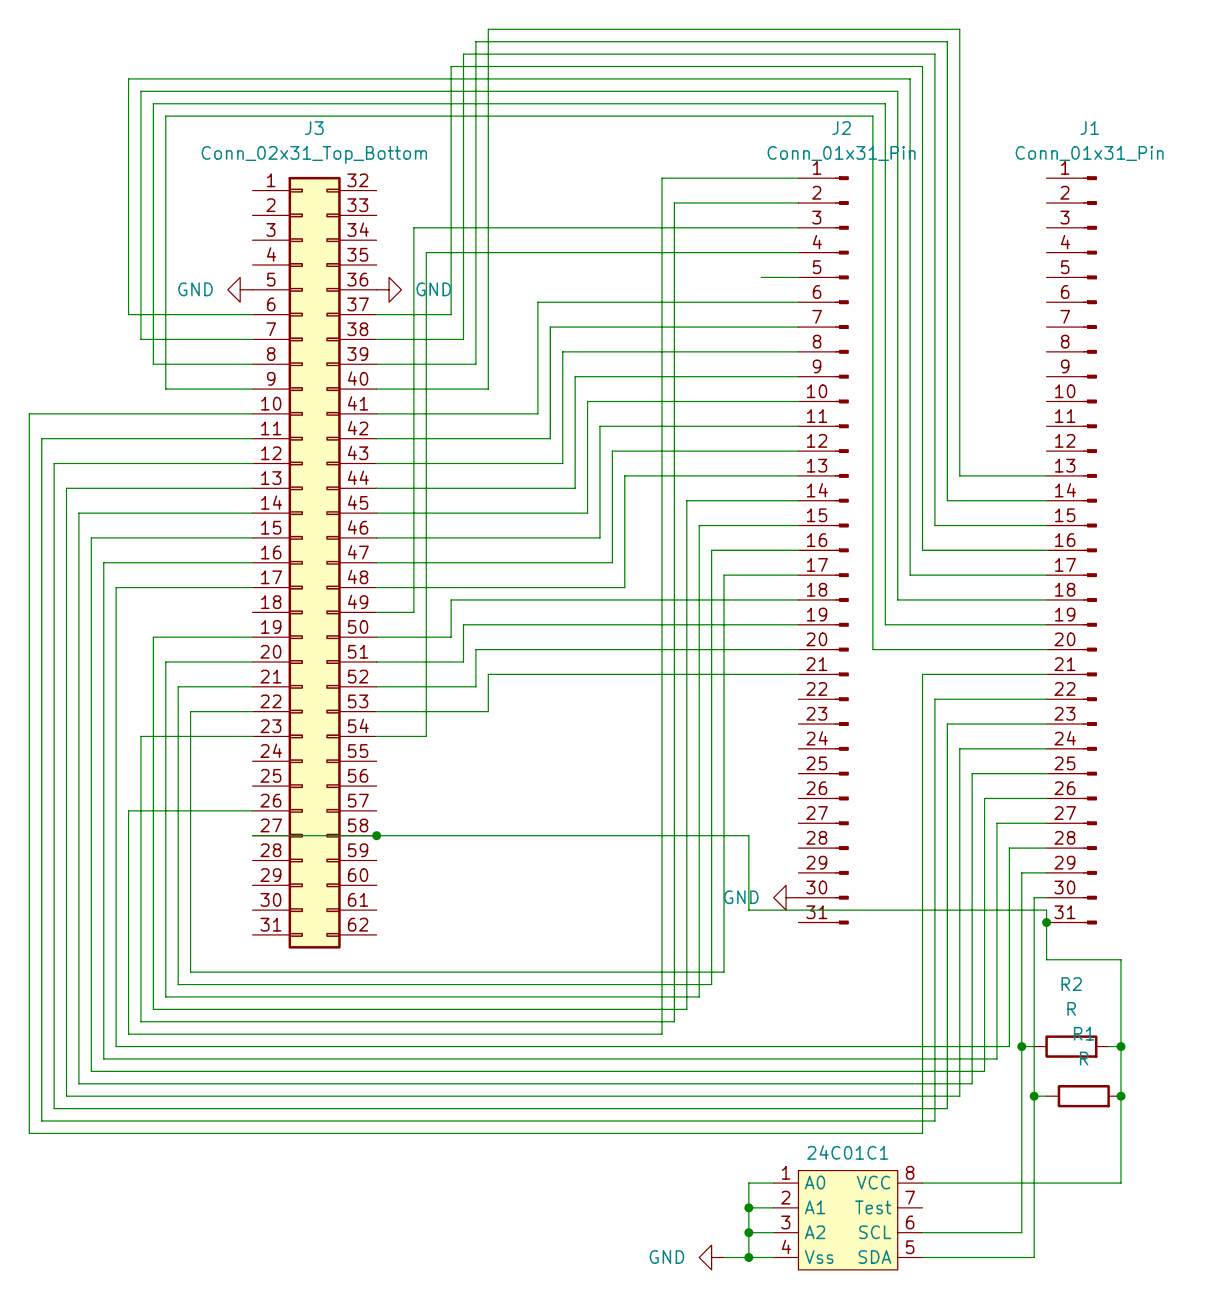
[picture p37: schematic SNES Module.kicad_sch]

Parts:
24C01C1: DIP-8_W7.62mm
J1, J2: Conn_01x31_Pin; PinSocket_1x31_P2.54mm_Vertical
J3: Conn_02x31_Top_Bottom; SNES_Cartridge_Port
R1, R2: R; R_Axial_DIN0207_L6.3mm_D2.5mm_P10.16mm_Horizontal

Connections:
GND: 24C01C1.1 (A0), 24C01C1.2 (A1), 24C01C1.3 (A2), 24C01C1.4 (Vss), J2.30, J3.5, J3.36
unnamed: 24C01C1.6 (SCL), J1.29, R2.1
unnamed: 24C01C1.5 (SDA), J1.30, R1.1
unnamed: 24C01C1.8 (VCC), J1.31, J3.27, J3.58, R1.2, R2.2
unnamed: J1.13, J3.40
unnamed: J1.14, J3.39
unnamed: J1.15, J3.38
unnamed: J1.16, J3.37
unnamed: J1.17, J3.6
unnamed: J1.18, J3.7
unnamed: J1.19, J3.8
unnamed: J1.20, J3.9
unnamed: J1.21, J3.10
unnamed: J1.22, J3.11
unnamed: J1.23, J3.12
unnamed: J1.24, J3.13
unnamed: J1.25, J3.14
unnamed: J1.26, J3.15
unnamed: J1.27, J3.16
unnamed: J1.28, J3.17
unnamed: J2.1, J3.26
unnamed: J2.2, J3.23
unnamed: J2.3, J3.49
unnamed: J2.4, J3.54
unnamed: J2.6, J3.41
unnamed: J2.7, J3.42
unnamed: J2.8, J3.43
unnamed: J2.9, J3.44
unnamed: J2.10, J3.45
unnamed: J2.11, J3.46
unnamed: J2.12, J3.47
unnamed: J2.13, J3.48
unnamed: J2.14, J3.19
unnamed: J2.15, J3.20
unnamed: J2.16, J3.21
unnamed: J2.17, J3.22
unnamed: J2.18, J3.50
unnamed: J2.19, J3.51
unnamed: J2.20, J3.52
unnamed: J2.21, J3.53

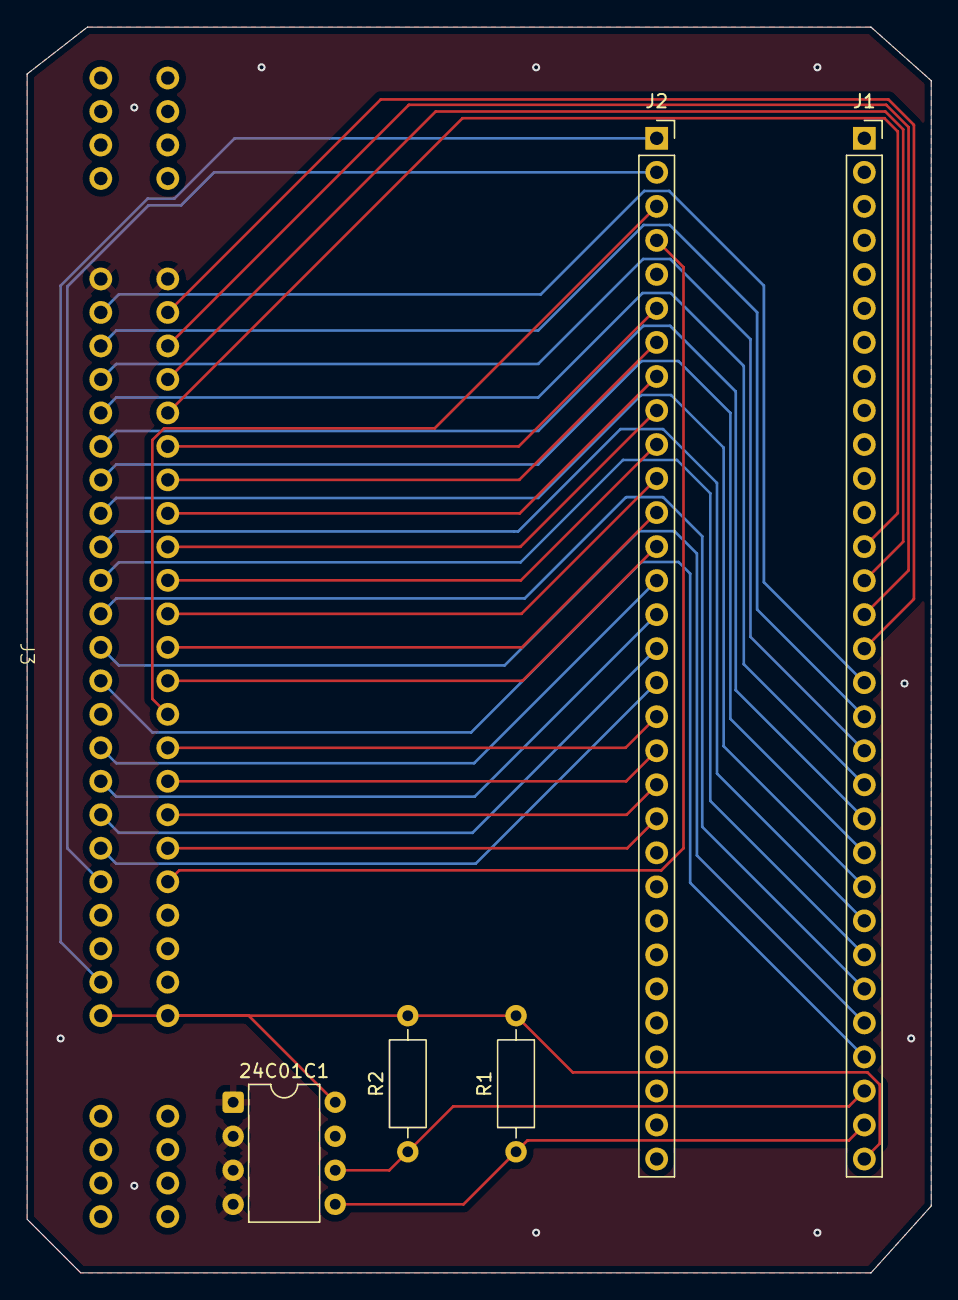
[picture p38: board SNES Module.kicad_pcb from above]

Board: 2 copper layers, 67.5 x 93.0 mm, 6 parts (0 on the bottom side), 40 nets.

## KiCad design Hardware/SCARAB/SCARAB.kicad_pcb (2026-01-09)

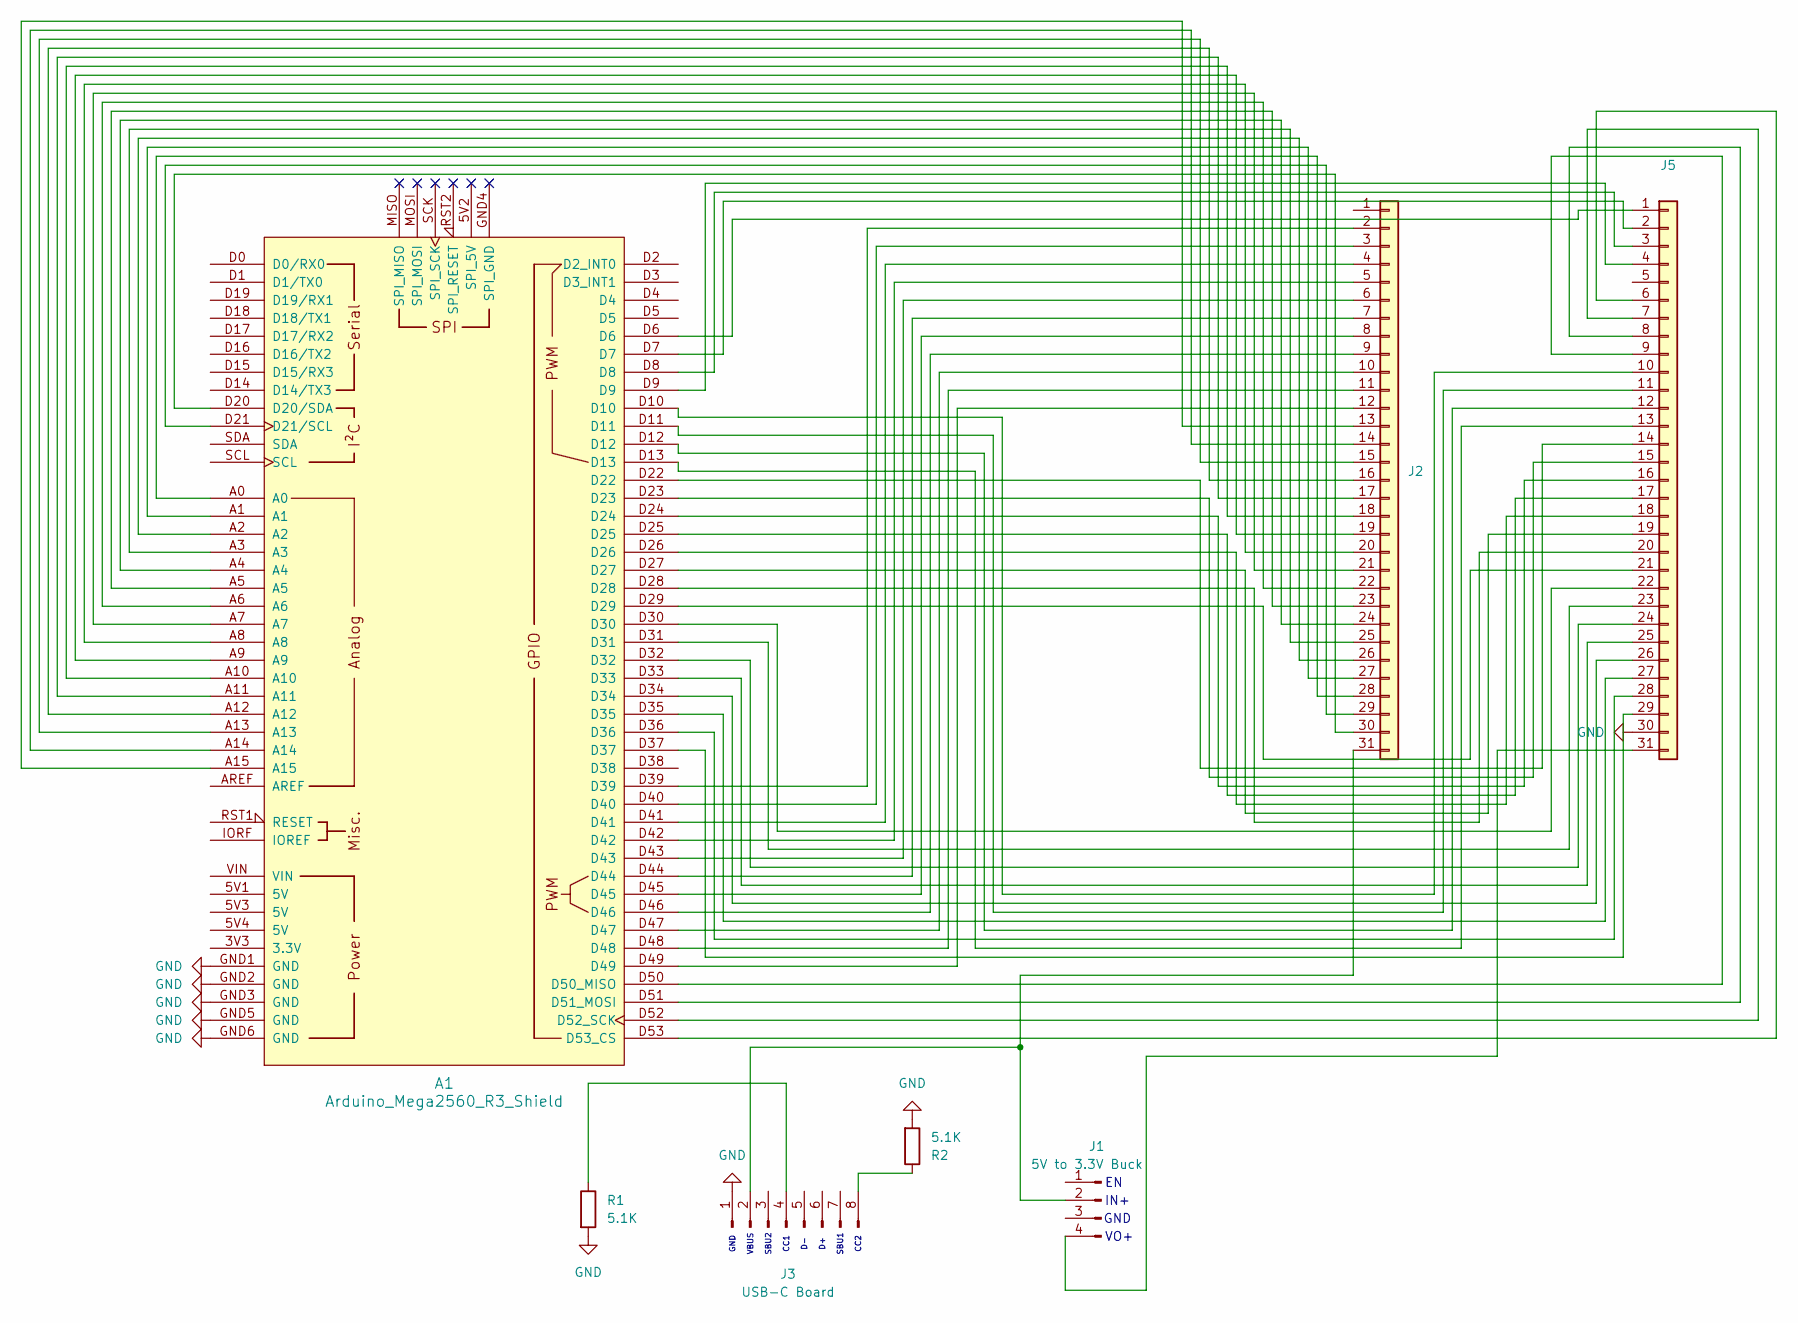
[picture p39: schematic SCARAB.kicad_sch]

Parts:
A1: Arduino_Mega2560_R3_Shield
J1: 5V to 3.3V Buck; PinHeader_1x04_P2.54mm_Vertical
J2, J5: Conn_01x31; PinSocket_1x31_P2.54mm_Vertical
J3: USB-C Board; PinSocket_1x08_P2.54mm_Vertical
R1, R2: 5.1K; R_Axial_DIN0207_L6.3mm_D2.5mm_P7.62mm_Horizontal

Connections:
GND: A1.GND1 (GND), A1.GND2 (GND), A1.GND3 (GND), A1.GND5 (GND), A1.GND6 (GND), J3.1, J5.30, R1.2, R2.2
unnamed: A1.D20 (D20/SDA), J2.30
unnamed: A1.D21 (D21/SCL), J2.29
unnamed: A1.D50 (D50_MISO), J5.9
unnamed: A1.D51 (D51_MOSI), J5.8
unnamed: A1.D52 (D52_SCK), J5.7
unnamed: A1.D53 (D53_CS), J5.6
unnamed: J1.2, J2.31, J3.2
unnamed: J1.4, J5.31
unnamed: A1.D39, J2.2
unnamed: A1.D40, J2.3
unnamed: A1.D41, J2.4
unnamed: A1.D42, J2.5
unnamed: A1.D43, J2.6
unnamed: A1.D44, J2.7
unnamed: A1.D45, J2.8
unnamed: A1.D46, J2.9
unnamed: A1.D47, J2.10
unnamed: A1.D48, J2.11
unnamed: A1.D49, J2.12
unnamed: A1.A15, J2.13
unnamed: A1.A14, J2.14
unnamed: A1.A13, J2.15
unnamed: A1.A12, J2.16
unnamed: A1.A11, J2.17
unnamed: A1.A10, J2.18
unnamed: A1.A9, J2.19
unnamed: A1.A8, J2.20
unnamed: A1.A7, J2.21
unnamed: A1.A6, J2.22
unnamed: A1.A5, J2.23
unnamed: A1.A4, J2.24
unnamed: A1.A3, J2.25
unnamed: A1.A2, J2.26
unnamed: A1.A1, J2.27
unnamed: A1.A0, J2.28
unnamed: J3.4, R1.1
unnamed: J3.8, R2.1
unnamed: A1.D6, J5.1
unnamed: A1.D7, J5.2
unnamed: A1.D8, J5.3
unnamed: A1.D9, J5.4
unnamed: A1.D10, J5.10
unnamed: A1.D11, J5.11
unnamed: A1.D12, J5.12
unnamed: A1.D13, J5.13
unnamed: A1.D22, J5.14
unnamed: A1.D23, J5.15
unnamed: A1.D24, J5.16
unnamed: A1.D25, J5.17
unnamed: A1.D26, J5.18
unnamed: A1.D27, J5.19
unnamed: A1.D28, J5.20
unnamed: A1.D29, J5.21
unnamed: A1.D30, J5.22
unnamed: A1.D31, J5.23
unnamed: A1.D32, J5.24
unnamed: A1.D33, J5.25
unnamed: A1.D34, J5.26
unnamed: A1.D35, J5.27
unnamed: A1.D36, J5.28
unnamed: A1.D37, J5.29

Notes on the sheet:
GND VBUS SBU2 CC1 D- D+ SBU1 CC2
GND
VO+
IN+

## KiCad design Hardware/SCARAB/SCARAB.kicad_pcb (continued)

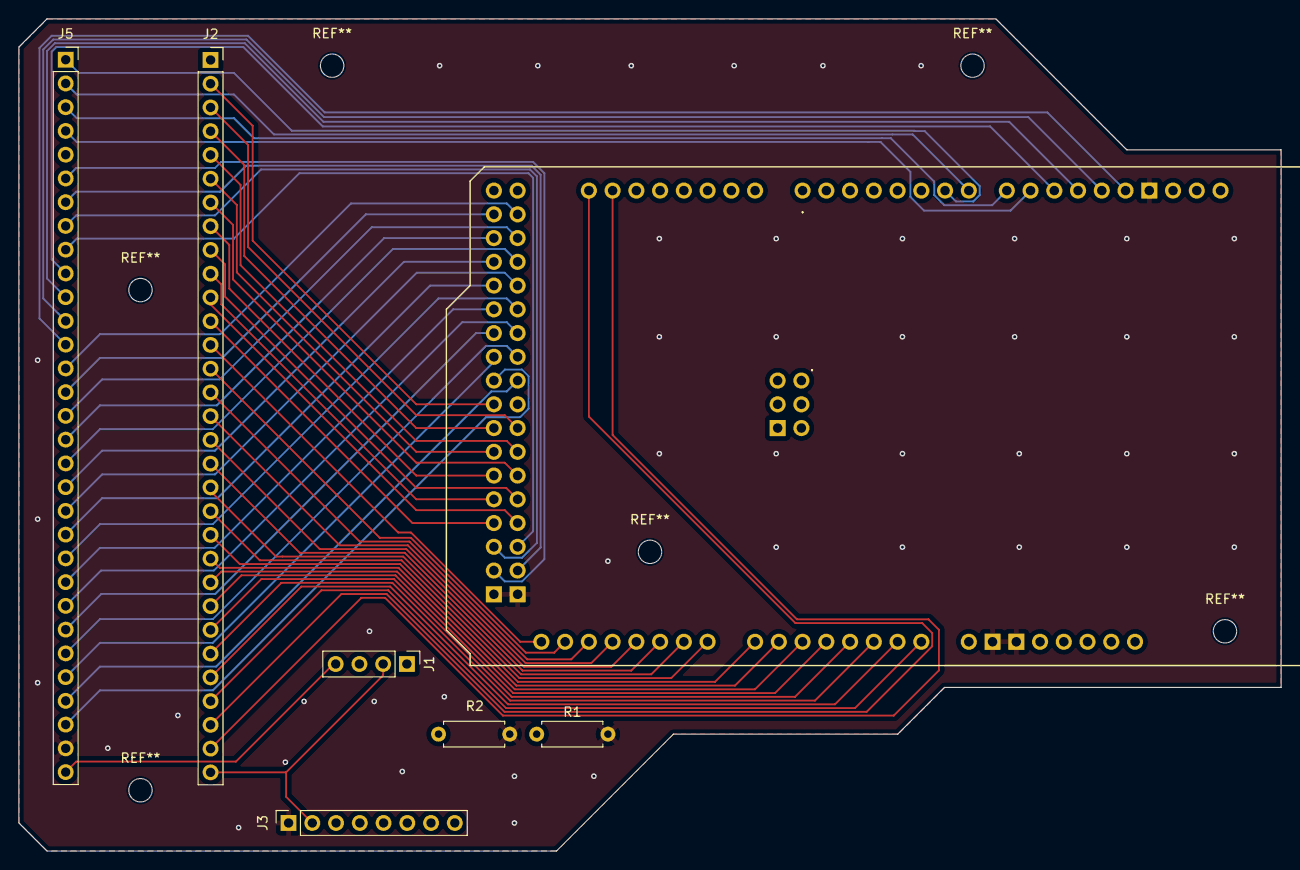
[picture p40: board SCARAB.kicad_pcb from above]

Board: 2 copper layers, 135.0 x 89.0 mm, 7 parts (1 on the bottom side), 62 nets.

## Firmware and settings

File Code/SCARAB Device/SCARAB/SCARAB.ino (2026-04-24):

#define EEPROM_CONTROL_ADDRESS 0x50
#define NOP __asm__ __volatile__("nop\n\t")
#include <Wire.h>

void setup() {
  Serial.begin(2000000);
  Wire.begin();
  Wire.setWireTimeout(1000, true);
}

void eeprom_write_page(byte deviceaddress, uint8_t eeaddr, const byte * data, byte length)
{
    Wire.beginTransmission(deviceaddress);
    Wire.write(int(eeaddr));
    for (int i = 0; i < length; i++) {
        Wire.write(data[i]);
    }
    Wire.endTransmission();
    delay(10);
}

int eeprom_read_buffer(byte deviceaddr, uint8_t eeaddr, byte * buffer, byte length)
{
    Wire.beginTransmission(deviceaddr);
    Wire.write(int(eeaddr));
    Wire.endTransmission(false);

    Wire.requestFrom(deviceaddr, length);
    int i;
    for (i = 0; i < length && Wire.available(); i++) {
        buffer[i] = Wire.read();
    }
    return i;
}

void loop() {
  // put your main code here, to run repeatedly:
  if (Serial.available() > 0)
  {
    uint8_t op = Serial.read();
    switch (op) {
      case 0x01:{
        Serial.print("SCARAB");
        break;}
      case 0x02:{
        byte myBuff[8];
        eeprom_read_buffer(0x50, 0x00, myBuff, 0x08);
        String mod = (char *)myBuff;
        if (mod.equalsIgnoreCase("SNES    ")) {snes_setup();}
        if (mod.equalsIgnoreCase("NES     ")) {nes_setup();}
        Serial.write(myBuff, 8);
        break;
      }
      case 0x03:{
        byte myBuff[8];
        while(Serial.available() < 8){}
        for (int i = 0; i < 8; i++) {
          myBuff[i] = Serial.read();
        }
        eeprom_write_page(0x50, 0x00, myBuff, 0x08);
        Serial.print("OK");
        break;
      }
      case 0x11:{
        snes_setup();
        uint8_t buffer[64];
        readSnesHeader(buffer, SNES_HEADER_START, SNES_HEADER_END, 'H');
        Serial.write(buffer, SNES_HEADER_SIZE);
        break;}
      case 0x12:{
        snes_setup();
        uint8_t header[64];
        readSnesHeader(header, SNES_HEADER_START, SNES_HEADER_END, 'H');
        uint8_t headerCheck[64];
        readSnesHeader(headerCheck, SNES_HEADER_START, SNES_HEADER_END, 'L');
        boolean loRom = true;
        for (uint8_t count = 0; count < SNES_HEADER_SIZE && loRom; count++) {
          loRom = header[count] == headerCheck[count];
        }
        if (loRom) {Serial.write('L');}
        else {
          readSnesHeader(headerCheck, SNES_HEADER_START, SNES_HEADER_END, 'X');
          boolean exHiRom = true;
          for (uint8_t count = 0; count < SNES_HEADER_SIZE && exHiRom; count++) {
            exHiRom = header[count] == headerCheck[count];
          }
          if (exHiRom) {Serial.write('X');}
          else {Serial.write('H');}
        }
        break;
      }
      case 0x20:{
        snes_setup();
        testDataPinsSnes('H');
        break;}

      case 0x21: {
        while (Serial.available() < 2) {}
        nes_setup();
        uint8_t mapper = Serial.read();
        uint8_t banks = Serial.read();
        testPrgDataPins(mapper, banks);
        break;
      }
      case 0x22: {
        while (Serial.available() < 2) {}
        nes_setup();
        uint8_t mapper = Serial.read();
        uint8_t banks = Serial.read();
        testChrDataPins(mapper, banks);
        break;
      }
      
      case 0x30:{
        while(Serial.available() < 2){}
        snes_setup();
        uint8_t romPow = Serial.read();
        char romType = Serial.read();
        uint64_t romSize = 1024UL << romPow;
        uint16_t crc = calcSnesChecksum(romSize, romType);
        uint8_t upper = crc >> 8;
        uint8_t lower = crc & 0xFF;
        Serial.write(upper);
        Serial.write(lower);
        break;
      }

      case 0x31: {
        while (Serial.available() < 2) {}
        nes_setup();
        uint8_t mapper = Serial.read();
        uint8_t banks = Serial.read();
        uint32_t crc = calcPrgCrc32(mapper, banks);
        Serial.write((crc >> 24) & 0xFF);
        Serial.write((crc >> 16) & 0xFF);
        Serial.write((crc >>  8) & 0xFF);
        Serial.write(crc & 0xFF);
        break;
      }

      case 0x32: {
        while (Serial.available() < 2) {}
        nes_setup();
        uint8_t mapper = Serial.read();
        uint8_t banks = Serial.read();
        uint32_t crc = calcChrCrc32(mapper, banks);
        Serial.write((crc >> 24) & 0xFF);
        Serial.write((crc >> 16) & 0xFF);
        Serial.write((crc >>  8) & 0xFF);
        Serial.write(crc & 0xFF);
        break;
      }
        
      case 0x40:{
        while(Serial.available() < 2){}
        snes_setup();
        uint8_t ramPow = Serial.read();
        char romType = Serial.read();
        uint64_t ramSize = 1024 * pow(2, ramPow);
        dumpSnesSave(ramSize, romType);
        break;
      }
      case 0x41:{
        while(Serial.available() < 2){}
        snes_setup();
        uint8_t ramPow = Serial.read();
        char romType = Serial.read();
        uint64_t ramSize = 1024 * pow(2, ramPow);
        prepSnesWrite();
        restoreSnesSave(ramSize, romType);
        break;
      }
      case 0x50: {
        nes_setup();
        dumpNesSave();
        break;
      }

      case 0x51: {
        nes_setup();
        restoreNesSave();
        break;
      }
      case 0x60: {
        while (Serial.available() < 2) {}
        nes_setup();
        uint8_t base_page = Serial.read();
        uint8_t num_banks = Serial.read();
        uint16_t base_addr = base_page ? 0xE000 : 0x8000;
        uint8_t buffer[64];
        prepPrgRead();
        NES_ROMSEL_LOW;
        for (uint8_t b = 0; b < num_banks; b++) {
          for (uint16_t x = 0; x < 0x2000; x++) {
            buffer[x % 64] = readPrg(base_addr + x);
            if (x % 64 == 63) {
              Serial.write(buffer, 64);
              Serial.flush();
              while (Serial.available() < 1) {}
              Serial.read();
            }
          }
        }
        NES_ROMSEL_HIGH;
        break;
      }
    case 0x70: {
        while (Serial.available() < 2) {}
        uint8_t mapper = Serial.read();
        uint8_t banks = Serial.read();
        dumpPrgRom(mapper, banks);
        break;
      }

      case 0x71: {
        while (Serial.available() < 2) {}
        uint8_t mapper = Serial.read();
        uint8_t banks = Serial.read();
        dumpChrRom(mapper, banks);
        break;
      }
    }
  }
}

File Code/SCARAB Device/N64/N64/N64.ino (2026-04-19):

#define NOP __asm__ __volatile__("nop\n\t")
#define READ_HIGH PORTC |= 0b00000100
#define READ_LOW PORTC &= 0b11111011
#define WRITE_HIGH PORTC |= 0b00001000
#define WRITE_LOW PORTC &= 0b11110111
#define ALEL_HIGH PORTC |= 0b00000010
#define ALEL_LOW PORTC &= 0b11111101
#define ALEH_HIGH PORTC |= 0b00000001
#define ALEH_LOW PORTC &= 0b11111110
#define DIR_CART PORTG |= 0b00000001
#define DIR_SCARAB PORTG &= 0b11111110
#define OE_HIGH PORTG |= 0b00000010
#define OE_LOW PORTG &= 0b11111101
#define AD0toAD7out PORTL
#define AD8toAD15out PORTK
#define AD0toAD7in PINL
#define AD8toAD15in PINK
bool isChecked;

void setup() {
  // put your setup code here, to run once:
  DDRG = 0xFF;
  DDRC = 0xFF;
  DDRL = 0xFF; //LOWER
  DDRK = 0xFF; //UPPER
  READ_HIGH;
  WRITE_HIGH;
  ALEL_HIGH;
  ALEH_HIGH;
  OE_LOW;
  PORTG |= 0b00000100;
  delay(300);
  Serial.begin(2000000);
  isChecked = false;
}

void n64WriteSetup() {
  DDRL = 0xFF; //LOWER
  PORTL = 0x00;
  DDRK = 0xFF; //UPPER
  PORTK = 0x00;
  DIR_CART;
  delayMicroseconds(5);
}

void n64ReadSetup() {
  DDRL = 0x00; //LOWER
  DDRK = 0x00; //UPPER
  PORTL = 0xFF;
  PORTK = 0xFF;
  DIR_SCARAB;
  delayMicroseconds(5);
}

void n64WriteAddress(uint32_t address) {
  n64WriteSetup();

  uint16_t adrLow = address & 0xFFFF;
  uint16_t adrHigh = (address >> 16) & 0xFFFF;

  READ_HIGH;
  WRITE_HIGH;
  ALEL_HIGH;
  ALEH_HIGH;

  AD0toAD7out = adrHigh & 0xFF;
  AD8toAD15out = (adrHigh >> 8) & 0xFF;

  delay(5);

  ALEH_LOW;

  AD0toAD7out = adrLow & 0xFF;
  AD8toAD15out = (adrLow >> 8) & 0xFF;

  delay(5);delay(5);

  ALEL_LOW;

  n64ReadSetup();
}

uint16_t n64ReadData() {
  READ_LOW;
  delay(5);NOP;NOP;NOP;NOP;
  uint16_t tempWord = ((AD8toAD15in & 0xFF) << 8) | (AD0toAD7in & 0xFF);
  READ_HIGH;
  return tempWord;
}

void loop() {
  while(!isChecked) {
    // Set the address
    byte sdBuffer[64];
    delayMicroseconds(5);
    // Read first 64 bytes of rom
    for (int c = 0; c < 64; c += 2) {
      n64WriteAddress(0x10000000 + c);
      // split word
      word myWord = n64ReadData();
      byte loByte = myWord & 0xFF;
      byte hiByte = myWord >> 8;

      // write to buffer
      sdBuffer[c] = hiByte;
      sdBuffer[c + 1] = loByte;
    }
    // Pull ale_H(PC1) high
    ALEH_HIGH;
    for(int i = 0; i < 64; i++)
    {
      Serial.print(sdBuffer[i], HEX);
      Serial.print(" ");
    }
    Serial.println();
    Serial.write(sdBuffer, 64);
    Serial.println();
    isChecked = true;
  }

}

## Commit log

2025-10-05 Uploaded current Functional Specification
2025-11-30 Made progress on SNES Read and Test, provided CLI for SCARAB, added Circuit Diagrams.
2026-01-09 Added Schematics and PCB Design for SCARAB and accompanying SNES Module
    [SCARAB.kicad_pcb, SCARAB.kicad_sch, SNES Module.kicad_pcb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]
2026-01-11 Added SCARAB Connector Footprint
2026-02-13 Progressed in the SCARAB Device Development
    [NES Module.kicad_pcb, NES Module.kicad_sch]
2026-03-19 Fixed bug leading to some save files not being dumped.
    [SNES.py]
2026-04-07 Setup Check Health menu, and remade the SNES Module PCB.
    [SNES Module.kicad_pcb, SNES Module.kicad_sch]
2026-04-13 Created PCBs for more Cartridges, and fleshed out imagery in the PC Program
    [GB GBA Module.kicad_pcb, GB GBA Module.kicad_sch, N64 Module.kicad_pcb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]
2026-04-15 Made Progress on game image display, and finished health checking + error handlng, along with an options menu
    [File_Management.py, Game_Imagery.py, SCARAB_Device.py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]
2026-04-16 Added image support and fixed bugs.
    [Game_Imagery.py, Module_Base.py, SCARAB_GUI.py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]
2026-04-19 Updated Final Report, Added NES Arduino Code
    [GB GBA Module.kicad_pcb]
2026-04-24 edited nes module board
    [NES Module.kicad_pcb, NES Module.kicad_sch]
2026-04-24 Commented Code, Converted documents to PDF.
    [GB GBA Module.kicad_pcb]
